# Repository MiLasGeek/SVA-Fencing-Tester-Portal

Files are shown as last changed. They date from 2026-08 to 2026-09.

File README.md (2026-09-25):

# SVA-Fencing-Tester-Portal 🤺

Willkommen im offiziellen Portal für den SVA-Fencing-Tester. Dieses Projekt wird als private Non-Profit-Initiative im Ehrenamt geführt, um Fechtvereine und Fechter mit einem zuverlässigen Werkzeug für die Wartung und Materialkontrolle zu unterstützen.

Der SVA-Fencing-Tester wird von Fechtern für Fechter ohne Gewinnabsicht entwickelt. Er soll den Sport durch erschwingliche Materialpflege attraktiver machen, bei Wartung und Turnierbetrieb Zeit sparen und nachvollziehbare, transparente Materialkontrollen unterstützen.

Die Bedienung wird bewusst einfach und möglichst intuitiv gestaltet, damit Ergebnisse eindeutig eingeordnet werden können und Interpretationsfehler vermieden werden. Das Gerät soll sowohl Einsteigern als auch erfahrenen Prüfern helfen; Nachwuchs nutzt es im Vereinsrahmen nach Einweisung und bei Bedarf begleitet.

Das Bedienkonzept folgt dem Prinzip **vom Ergebnis zum Detail**: Zuerst zeigt die Oberfläche klar OK oder NOK. Balken mit Grenzlinie und einstellbarem Warnbereich vermitteln anschließend, wie gut oder wie schlecht ein Messwert ist - mit einem Verlauf von Grün zu Gelb. Charts und Zahlenwerte ermöglichen die vertiefte Analyse; eine vollständige visuelle Anschluss- und Fehlermatrix macht Zusammenhänge auf einen Blick sichtbar. So reduziert die Oberfläche die geistige Belastung bei der Prüfung.

Für nachvollziehbare Materialprüfungen kann ein signiertes FIE-Preset verwendet werden. Die darin hinterlegten Grenzwerte sind im Gerät nur lesbar einsehbar; bei aktivem Preset kennzeichnet die Benutzeroberfläche den FIE-Modus deutlich. Das schafft Transparenz über die verwendeten Prüfparameter, ohne eine FIE-Zertifizierung oder formale Konformitätsaussage des Testers zu behaupten. Das Messprinzip und die Inhouse-Validierung sind in der [Messvalidierung](./docs/measurement_validation.md) dokumentiert.

⚠️ **AKTUELLER STATUS: Entwicklungs- und Evaluierungsphase**
Dieses öffentliche Portal veröffentlicht OTA-Updates, Handbücher, technische Hinweise und signierte Prüfparameter. Firmware und Webapp bleiben Closed Source; Quellcode und editierbare Elektronik-Layouts werden hier nicht veröffentlicht. Nicht CE-gekennzeichnete Einheiten sind keine allgemeinen Produkte und nicht für Verbraucher freigegeben.

---

## 📂 Portal-Übersicht

* 🤖 **[Firmware & OTA-Updates](./bin)** – Enthält die `version.json` für den automatischen Versionsabgleich über den Client-Browser sowie die offiziellen Update-Bundles.
* 🤺 **[FIE-Presets](./fie)** – Lesbare, signierte FIE-Prüfparameter mit aktuellem Manifest, Archiv und direktem Download für die Geräte-Webapp.
* 📑 **[FIE Material Rules (December 2025)](https://static.fie.org/uploads/38/190667-book%20m%20ang.pdf)** – Externe Regelwerksreferenz des aktuellen FIE-Presets; Erreichbarkeit und Aktualität liegen bei der FIE.
* 📐 **[Hardware & 3D-Druck](./hardware)** – STL- und STEP-Dateien für das frei druckbare Basis-Gehäuse und alle gängigen Verschleißteile.
* 📖 **[Online-Handbuch & Dokumentation](./docs)** – Das vollständige Online-Handbuch, ausführliche Reparaturanleitungen und die Material-Stückliste (BOM).
* ⚙️ **[Technische Spezifikationen](./FEATURES.md)** – Das vollständige, detaillierte Leistungsspektrum und alle Geräteeigenschaften im Überblick.
* ⏳ **[Entwicklungsgeschichte & Veröffentlichungsnachweis](./DEVELOPMENT_HISTORY.md)** – Die Chronologie der Hardware-Revisionen (Rev 1.0 bis Rev 4.0).
* 💻 **[Software-Architektur & Algorithmen](./SOFTWARE_ARCHITECTURE.md)** – Dokumentation der deterministischen Echtzeit-Schnittstellen und Lock-Free-Puffer.
* ⚖️ **[Rechtliches & Impressum](./IMPRINT.md)** – Gesetzliche Anbieterkennzeichnung nach § 5 DDG sowie Haftungsausschlüsse für Software und Hardware.
* 🛡️ **[Datenschutzerklärung](./PRIVACY.md)** – Transparente Informationen zur DSGVO-konformen Datenverarbeitung innerhalb dieses Repositories.
* 📋 **[Compliance-Status (Entwurf)](./docs/compliance/README.md)** – Vorläufige CE-, CRA- und FIE-bezogene Unterlagen; keine finale Konformitätsdokumentation.
* 📜 **[Lizenzliste (Third-Party)](./docs/compliance/THIRD_PARTY_LICENSES.md)** – Übersicht über die verwendeten Open-Source-Bibliotheken und Drittlizenzen.
* 💬 **[Community & Support](../../discussions)** – Unser virtuelles Vereinsheim. Nutze den Tab "Discussions" für Fragen, Erfahrungsaustausch und Best Practices.
* 🐛 **[Fehler melden](../../issues)** – Nutze den Tab "Issues" für strukturierte Bug-Reports zur Firmware, Webapp oder Hardware.

---

## 🚀 Highlights & Kernfeatures (Sperrveröffentlichung)

Der SVA-Fencing-Tester (Revision 4.0) bricht mit traditionellen Messgeräte-Konzepten und bietet Profiliga-Diagnose im ultrakompakten Eurokarten-Format ($100 \times 60$ mm):

* **860-Hz-Echtzeit-Abtastung:** Lückenlose Erkennung transienter Wackelkontakte im Millisekundenbereich zur präzisen Materialkontrolle.
* **Prädiktiver Matrix-Scan:** Graphentheoretische Transitivitäts-Reduktion überspringt redundante Kreuzprüfungen und schont ADC-Einschwingzeiten.
* **Asymmetrisches Fading:** Visueller Hold-Effekt „streckt“ flüchtige Fehler für das menschliche Auge (Sofort-Rot bei Defekt, weiches, einstellbares Fade-out).
* **Topologie-identische UI:** 1:1 grafische Buchsen-Projektion auf dem Display mit dynamischen Spline-Bögen zur sofortigen Entlarvung von Adernvertauschungen.
* **Echtes Zero-Power-Standby:** Automatische PMIC-Abschaltung bei Inaktivität. Knopflose Wiederzuschaltung rein über transienten Kondensator-Einschaltstrom.
* **Masse-Anker-Stabilisierung:** Das mechanische Plangepresste Akku-Platinen-Sandwich nutzt die Batteriezelle als thermische Kapazität zur ADC-Rauschminimierung.
* **Bulletproof-Recovery-Kaskade:** Ein im Core integrierter Notfall-HTML-Server und ein lokaler microSD-OTA-Pfad sichern das System gegen Datenkorruption im Feld ab.

👉 **Das vollständige, detaillierte Leistungsspektrum findest du in der [FEATURES.md](./FEATURES.md).**

---

## 🔒 Technisches Konzept & Sicherheit (Closed-Source)

Dieses Projekt ist auf Code-Ebene Closed-Source. Es werden keine Quellcodes oder editierbaren Elektronik-Layouts veröffentlicht. Zum Schutz vor Manipulationen, zum Erhalt der Turniertransparenz bei Waffenkontrollen und zur Abwehr von Reverse Engineering greift folgende Architektur:

* **Hybrid-Updates über Client-Brücke:** Die Geräte arbeiten im Messbetrieb komplett offline und strahlen einen eigenen WLAN-Access-Point aus. Der Abgleich erfolgt über den Browser des Endgeräts (Smartphone/PC), welcher die Update-Datei von GitHub lädt und lokal per Webapp auf den Tester überträgt. Alternativ ist ein Offline-Update via microSD-Karte möglich.
* **All-in-One Custom Bundle:** Updates werden als verschlüsseltes Kombi-Paket bereitgestellt, welches die Firmware, das LittleFS-Dateisystem (inkl. der komprimierten Webapp `webapp.gz`) und ein schlankes Geräte-Handbuch enthält.
* **Automatischer Failsafe (Recovery Mode):** Die Integrität des Filesystems wird beim Systemstart geprüft. Fehlt die `webapp.gz` im Flash oder ist sie beschädigt, lädt der ESP32 automatisch einen autarken, minimalistischen Notfall-Webserver. Die Weboberfläche zur Rettung ist im Fehlerfall direkt über **`http://192.168.4.1`** erreichbar.
* **Hardware-Sicherheit:** Für die Releasekonfiguration ist die hardwareseitige AES-Verschlüsselung des ESP32-S3 (Flash Encryption) vorgesehen. Sie schützt die Vertraulichkeit der Flash-Inhalte, ersetzt jedoch keinen hardwareseitig erzwungenen Secure Boot oder physischen Manipulationsschutz. Die genaue Grenze ist in der Compliance-Dokumentation beschrieben.

---

## 📖 Dokumentation (Hybrid-Konzept)

Um den begrenzten Flash-Speicher des ESP32 zu schonen, teilen wir die Dokumentation auf:
1. **Offline-Handbuch (Lite):** Direkt im LittleFS des Geräts gespeichert. Es ist extrem speicheroptimiert, verzichtet auf große Bilder und beschreibt nur die physischen Tasten, LEDs und die Display-Menüs.
2. **Online-Handbuch (Full):** Hier im Repository unter `/docs/manuals`. Nur hier findest du die vollständige Anleitung inklusive hochauflösender Screenshots der Webapp und Erklärungen zu den Browser-Statistiken.

---

## 🛠️ Bezug von Hardware & Ersatzteilen (Non-Profit)

Es gibt keinen kommerziellen Webshop und keine allgemeine Geräteabgabe. Nicht CE-gekennzeichnete Einheiten werden ausschließlich als kundenspezifische Evaluierungskits an benannte Vereine mit sachkundiger Projektleitung abgegeben. Der Verein übernimmt die Endmontage einschließlich der eigenständigen Beschaffung und des Anschlusses eines geeigneten Akkus über den vorgesehenen Steckverbinder und verwendet das Kit ausschließlich in einer dokumentierten Forschungs- und Entwicklungsumgebung.

Das Projekt kann eine technische Akkuempfehlung bereitstellen. Der Akku wird nicht als Bestandteil des Evaluierungskits geliefert. Das vermeidet Gefahrgutversand und hilft, die Bereitstellungs- und Beschaffungskosten für Vereine niedrig zu halten. Er darf nur unbeschädigt, ohne Gewalt und gemäß der Kit-Anleitung angeschlossen werden. Die Endmontage durch den Verein ändert für sich allein weder die rechtliche Einordnung des Kits noch ersetzt sie die später erforderliche Konformitätsbewertung.

Die Übergabe der Evaluierungskits erfolgt in der Regel persönlich. Dadurch entfällt Versandverpackung; die Anforderungen für eine spätere allgemeine Marktbereitstellung bleiben davon unberührt. Bei Rückgaben ist Versand nicht ausgeschlossen, wird aber vorab abgestimmt.

Für die Rücknahme eines Evaluierungskits bitte vorab Kontakt aufnehmen. Der abgestimmte Rückgabeweg und eine Vorlage für die erforderlichen Angaben stehen unter [Rücknahme eines Evaluierungskits](./docs/return_request_template.md) bereit.

Private Fechter erhalten keine Einheit direkt, sondern nur über ihren Verein im Rahmen dieses Projektvorhabens. Eine andere Bereitstellung wird erst nach Abschluss der erforderlichen Laborprüfungen und der Konformitätsbewertung geprüft.

Ein Erwerb oder eine Kostenerstattung für ein Evaluierungskit wird ebenso individuell mit dem Verein abgestimmt; es gibt keinen offenen Shop und keine anonyme Direktbestellung. Dieser kleine, dokumentierte Rahmen erleichtert Übergabe, Rücknahme und Nachverfolgbarkeit. Er ersetzt jedoch nicht die rechtliche Prüfung, falls eine Überlassung als Marktbereitstellung einzuordnen ist.

Die technische Vorbereitung für die Laborprüfung ist abgeschlossen. Bei der kleinen Stückzahl liegen die Kosten voraussichtlich etwa beim Vier- bis Fünffachen der Kosten von zehn Geräten. Spenden und Fördermittel werden vorrangig für die EMV- und Funkprüfungen durch ein geeignetes Labor eingesetzt.

Eine CE-Erklärung wird erst nach abgeschlossener, dokumentierter Konformitätsbewertung unterzeichnet. Vor einer allgemeinen Marktbereitstellung werden außerdem die jeweils anwendbaren Pflichten für Elektrogeräte, Batterien und Verpackungen - einschließlich Kennzeichnung, Registrierung, Rücknahme und Entsorgung - geprüft und erfüllt.

Für eine einzelne B2B-Registrierung fallen nach der veröffentlichten Gebührenübersicht der stiftung ear derzeit beispielhaft rund 28,40 EUR netto einmalig sowie rund 131,20 EUR netto jährlich an, zuzüglich möglicher Entsorgungskosten. Bei einer Weitergabe von etwa zwanzig Geräten ist das ein erheblicher Fixkostenanteil. Die begrenzte Evaluierungsphase ermöglicht Vereinen daher einen preiswerten, dokumentierten Testeinsatz. Sie ist jedoch keine Zusage, dass keine Markt-, CE-, Entsorgungs- oder sonstigen Rechtsrisiken bestehen; jede Überlassung wird einzeln dokumentiert und rechtlich eingeordnet.

Diese Abgrenzung dient nicht dazu, gesetzliche Pflichten zu umgehen. Sobald eine Überlassung als Marktbereitstellung einzuordnen ist, werden die erforderlichen Pflichten unabhängig von Stückzahl oder Kostendeckung erfüllt. Bei einer einmaligen Kleinserie wären die laufenden Registrierungs- und Organisationskosten jedoch ein erheblicher privater Zuschuss, weil Vereine die Geräte nur zum Selbstkostenpreis erhalten. Die Evaluierungsphase schafft deshalb einen nachvollziehbaren Weg, den tatsächlichen Bedarf und die technische Reife zunächst begrenzt zu prüfen.

Eine geringe Zahl dokumentierter Einheiten im Feld ist für diese Evaluierung sinnvoll; eine Ausweitung in kleinen Einzelschritten wäre es nicht. Steigt die Nachfrage über diesen Rahmen hinaus, soll ein geeigneter Hersteller die professionelle beziehungsweise maschinelle Fertigung, die abgeschlossene Konformitätsbewertung und die vollständige Marktfreigabe übernehmen. Voraussetzung ist ein Preis, der den Vereinen und der ehrenamtlichen Entwicklung weiterhin gerecht wird.

👉 **[Evaluierungskit-Anfrage für einen Verein erstellen](../../issues/new?template=anfrage_premium.md)**

---

## 🧾 Steuerlicher Hinweis & Abrechnung

* **Aktueller Rahmen:** Das Projekt wird von einer einzelnen Privatperson in der Freizeit betrieben; eine Gewinnabsicht besteht nicht. Solange keine andere Organisationsform oder gewerbliche Tätigkeit besteht, werden keine gesonderten Umsatzsteuerbeträge ausgewiesen.
* **Brutto-Selbstkosten:** Elektronische Bauteile werden über offizielle Distributoren wie Mouser und Aisler bezogen. Eine etwaige Weitergabe erfolgt zu den tatsächlich angefallenen Brutto-Materialkosten, ohne Gewinnaufschlag und nur im Rahmen der zeitlich möglichen Handbestückung.
* **Vereinsbuchhaltung:** Vereine erhalten einen privaten Kaufbeleg (Quittung über Aufwandsersatz/Materialkosten) für ihre Unterlagen. Kopien der originalen Distributor-Rechnungen können zur absoluten Transparenz beigelegt werden. 
* **Fertigung nach Verfügbarkeit:** Bestückung, Kalibrierung und Endtests erfolgen in der Freizeit und nur in kleinen Stückzahlen. Sollte sich die Organisations- oder Fertigungsform ändern, werden die rechtlichen, steuerlichen und vertraglichen Angaben vor einer Bereitstellung entsprechend überprüft und angepasst.

---

## 📄 Lizenz & Rechtliches

Die Firmware ist urheberrechtlich geschützt (Binary-only). Für die 3D-Druckdaten im Ordner `/hardware` gilt die **Creative Commons Namensnennung - Nicht-kommerziell - Weitergabe unter gleichen Bedingungen 4.0 International (CC BY-NC-SA 4.0)**. Eine gewerbliche Nutzung oder der kommerzielle Weiterverkauf der Gehäuseteile ist strikt untersagt. Siehe `LICENSE`-Datei für Details.

Informationen zum Anbieter sowie zum Datenschutz findest du in unserem separaten [Impressum](./IMPRINT.md) und der [Datenschutzerklärung](./PRIVACY.md).

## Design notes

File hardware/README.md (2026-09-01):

# Hardware-Übersicht

Dieser Bereich enthält ausgewählte, nicht-editierbare Visualisierungen der Hardware-Revisionen des SVA-Fencing-Testers. Schaltpläne, PCB-Quelldaten und Fertigungsdaten sind nicht Bestandteil dieses öffentlichen Portals.

## PCB-Renderings

- [Revision 2](./pcb/rev2/)
- [Revision 4](./pcb/rev4/)

## 3D-Modelle für Gehäuse-CAD

Die KiCad-exportierten STEP-Modelle enthalten die bestückten PCB-Baugruppen und dienen als räumliche Grundlage für Gehäusekonstruktionen:

- [Revision 2](./models/sva-fencing-tester-rev2.step)
- [Revision 4](./models/sva-fencing-tester-rev4.step)

Die Abbildungen dienen ausschließlich zur Identifikation und Dokumentation der jeweiligen Hardware-Revision. Sie sind keine Fertigungsunterlagen.

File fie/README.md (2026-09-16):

# FIE preset archive

This directory publishes readable, signed FIE test-parameter presets for the SVA-Fencing-Tester.

## Current preset

The current package is identified by [`latest.json`](./latest.json). It references the signed file in [`stable/`](./stable/) and includes its SHA-256 checksum for the browser download flow.

- Preset version: `1`
- Preset date: `2026-08-18`
- Rule reference: FIE Material Rules, `December 2025`
- Source: [FIE Material Rules PDF](https://static.fie.org/uploads/38/190667-book%20m%20ang.pdf)

## Use and verification

The device webapp can download the current preset through the user's browser, or the JSON file can be downloaded here and imported manually. In both cases, the ESP verifies the schema, values, key ID and ECDSA P-256/SHA-256 signature itself before it stores or activates a preset.

The manifest checksum is an additional transport check only. A modified portal file, manifest or browser response cannot activate a changed preset without a valid device-trusted signature.

The source URL is the signed reference snapshot for this particular preset; it is not a promise that the linked FIE document remains reachable or the newest publication. The external FIE website is outside this project's control. A changed FIE source, rule edition or URL requires a new dated, versioned and signed preset. Published preset files are never edited retroactively. Devices continue to show and use their imported preset until the user explicitly loads or imports a newer one.

## Publication rule

Each new release keeps its dated signed JSON package in `stable/` and updates `latest.json` only after the package, its SHA-256 value, FIE source document and source month/year have been reviewed together. The source version uses the exact form `Month YYYY`, for example `December 2025`.

This preset identifies a selected test-parameter profile. It is not an official FIE logo, certification, or a certification of a test result or device.

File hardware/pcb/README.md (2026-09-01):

# PCB-Visualisierungen

Dieser Bereich enthält nicht-editierbare Renderings und Grafiken der Leiterplatten (PCBs) des SVA-Fencing-Testers. Diese Abbildungen dienen ausschließlich zur Identifikation, Dokumentation und visuellen Überprüfung der jeweiligen Hardware-Revision. 

Schaltpläne, Layout-Quelldaten (z. B. KiCad-Dateien) und Gerber-Fertigungsdaten sind nicht Bestandteil dieses Verzeichnisses.

## PCB-Revisionen

- [Revision 2](./rev2/) – Enthält Darstellungen des stabilen Revision-2-Formfaktors (Platinen-Unterseite und Display).
- [Revision 4](./rev4/) – Enthält Darstellungen der aktuellen Revision-4-Hardware (Platinen-Unterseite und Display).

## Inhalt der Unterverzeichnisse

Jeder Revisions-Ordner stellt folgende Standard-Visualisierungen bereit:
* **Platinen-Layout (`*-bottom.png`)**: Ansicht der Leiterbahnen und kritischen Bauteilplatzierungen auf der Unterseite.
* **Display-Layout (`*-display.png`)**: Visuelle Referenz für die Ausrichtung und Integration der Display-Komponente.

Die bereitgestellten Grafiken sind keine Fertigungsunterlagen.

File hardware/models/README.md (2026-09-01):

# STEP-Modelle für Gehäuse-CAD

| Hardware-Revision | STEP-Modell |
| --- | --- |
| Rev 2 | [sva-fencing-tester-rev2.step](./sva-fencing-tester-rev2.step) |
| Rev 4 | [sva-fencing-tester-rev4.step](./sva-fencing-tester-rev4.step) |

Die Modelle stammen aus KiCad-STEP-Exports der bestückten PCB-Baugruppen und sind als räumliche Grundlage für Gehäuse-CAD vorgesehen. Sie sind keine Schaltplan-, PCB-Quell- oder Fertigungsdaten.

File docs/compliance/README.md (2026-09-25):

# 📜 Regulatory Compliance, Specifications & Impressum (Rev 2 & Rev 4) — Draft

> **Status: Entwurf / nicht finale Konformitätsdokumentation.** Dieses Dokument beschreibt den derzeitigen Planungs- und Entwicklungsstand. Es ist **keine** unterschriebene EU-Konformitätserklärung, kein CE-Nachweis, kein CRA-Konformitätsnachweis und kein FIE-Zertifikat. Finale, datierte und gegebenenfalls unterzeichnete Unterlagen werden nach Abschluss der technischen Prüfung und Freigabe veröffentlicht.

The SVA-Fencing-Tester (supporting hardware revisions 2 and 4 via automatic firmware detection) is intended to be used exclusively as a specialized workshop diagnostic and maintenance tool for fencing gear. It is not intended as a tournament signaling apparatus (Melder). The final regulatory classification and the scope of any required assessment will be confirmed before product release.

---

## 🤺 1. FIE Reference & Specifications — Draft
The intended use is a dedicated workshop test bench for fencing equipment. It is not a tournament scoring apparatus (Melder) and does not display or control competition hits. The project aims to document conformity of the tested fencing material with the applicable FIE material requirements. A separate FIE certification of the tester itself is not intended for this diagnostic use; the final scope will be documented before product release.

* **Signal Evaluation:** Designed to test and analyze weapon assemblies, body cords, and reels against the applicable electrical tolerance windows in the FIE Technical Rules.
* **Microsecond Analytics:** The firmware loop records transient resistance changes in the microsecond range to visually isolate mechanical contact bouncing (Prellen) before it triggers a lockout on an official piste scoring box.
* **Pure Diagnostic Scope:** The unit does not actively interfere with tournament scoring loops. It serves solely as a diagnostic aid for material inspection before use.

---

## 🇪🇺 2. CE / RED / RoHS — Planning Status
The following points define the intended compliance scope for the final device. They do not constitute a declaration that either revision already satisfies the listed directives:
* **Radio Equipment Directive (RED - 2014/53/EU):** Planned assessment of the local 2.4 GHz Wi-Fi function and transmission parameters.
* **EMC Directive (2014/30/EU):** Planned assessment of electromagnetic compatibility based on the finalized hardware design.
* **RoHS Directive (2011/65/EU):** Component and supplier documentation will be collected for the final bill of materials.

### Evaluation phase

Until the final conformity assessment is complete, non-CE-marked units are supplied only as custom-built evaluation kits to named fencing clubs with a qualified project lead. The club independently procures and connects a suitable battery through the specified connector as part of final assembly, and uses the kit solely in a documented research and development environment. The project may provide a technical battery recommendation, but the battery is not part of the evaluation kit. Battery connection must follow the kit instructions and is not, by itself, a substitute for the required conformity assessment. Private fencers do not receive units directly; any involvement is exclusively through their club within that documented project. This is not a general market release or a regular club operation.

The technical preparation for laboratory testing is complete. Because of the small quantity, laboratory costs are expected to be approximately four to five times the cost of ten devices. Donations and grants are therefore reserved primarily for the required EMC and radio testing.

### Market release gate

No CE declaration will be signed and no CE marking will be affixed before the final device has a documented conformity assessment. For this project, a suitable EMC and radio laboratory report is a required release record. The report, technical documentation, risk assessment, instructions, manufacturer identification, and EU declaration of conformity must be complete and internally approved before any general market release.

Before market release in Germany, the project must also determine and complete all applicable producer obligations for electrical equipment, batteries and packaging, including registration, marking, take-back and disposal information. Final assembly by a club or separate procurement of a recommended battery does not by itself remove these obligations. The evaluation-kit boundary remains subject to documented case-by-case legal review.

For perspective, the published stiftung ear B2B example for one registration currently shows approximately EUR 28.40 net one-off and EUR 131.20 net per year, before any actual disposal costs. For a small run of around twenty devices, this is a material fixed-cost share. The limited evaluation phase is intended to let clubs test the equipment affordably while evidence is gathered for the final release. It does not guarantee exemption from market, CE, disposal, competition or other legal requirements; each supply must remain documented and be assessed for its specific circumstances.

This boundary is not intended to avoid statutory duties. If a supply is classified as making the product available on the market, the applicable duties will be fulfilled regardless of quantity or cost recovery. For a one-off small run, however, recurring registration and administration costs would be a material private subsidy because clubs receive units only at cost. The evaluation phase therefore provides a documented way to establish actual demand and technical maturity before a general release is considered.

A small number of documented units in the field is appropriate for that evaluation; gradual expansion through additional small runs is not. If demand exceeds this limited scope, an appropriate manufacturer should take over professional or automated manufacture, completed conformity assessment and the full market-release process. This is conditional on a price that remains appropriate for clubs and respects the voluntary nature of the project's development.

---

## 🔒 3. EU Cyber Resilience Act (CRA) — Preliminary Security Concept
The SVA-Fencing-Tester (Rev 2 / Rev 4) is being developed according to "Security by Design" principles. The following describes the intended architecture and must be validated against the final hardware, firmware, update process and applicable CRA requirements:

* **Zero Personal Data (GDPR Free):** The system does not collect, process, or store any personal user data or fencing club metrics.
* **Credential Hardening:** Local Wi-Fi credentials and security tokens are securely hashed/encrypted within the non-volatile storage and cannot be extracted via the user interface or wireless dumps.
* **Secure Configuration Backup:** Parameter and JSON configuration files are encrypted during export. While the local import logic accepts standard schemas for club flexibility, unencrypted exploitation from the outside is blocked.
* **Minimized Attack Surface (No OS / No FTP):** The device does not run a generic operating system (No OS overhead). High-risk legacy protocols like FTP, Telnet, or SSH are completely omitted.
* **No Internet Routing:** The device operates exclusively as a local, air-gapped server. It features no network forwarding, no internet gateway routing, and cannot connect to external cloud services.
* **Hardened Server & Binary Streams:** The local network architecture consists solely of a locked-down, proprietary server utilizing a minimalist REST API and an isolated, purely binary measurement data stream for real-time hit telemetry.
* **Strict Upload Restriction:** Outside of the authenticated OTA firmware update pipeline and the local configuration JSON import, no files can be uploaded or written to the internal LittleFS partition.
* **Physical Service Boundary:** Secure Boot is not enabled. Flash encryption and the custom OTA format protect the confidentiality of release contents and the regular update paths, but they do not prevent physical reprogramming. Reprogramming requires opening the device, the custom programming adapter and an independently developed firmware for the custom hardware; a device modified in this way is outside the released and supported configuration.

---

## 📦 Proprietary Encrypted OTA Bundle Format (SVA-Container)

To protect release contents and maintain a controlled update workflow, the SVA-Fencing-Tester uses an encrypted, proprietary bundle format (`.ota`).

Unencrypted firmware binaries (`.bin`) or raw file system images are never distributed publicly and will be automatically rejected by the device's bootloader.

### 🛡️ Core Security Layers of the `.ota` Container:

1. **Cryptographic Encapsulation (Container Encryption):**
   The firmware payload and LittleFS system assets (webapp and lite manual) are packed into a proprietary container using a private cryptographic routine prior to deployment on the `main` branch. The intended protection against extraction or unauthorised modification depends on the implemented cryptography, key management and final release configuration.
2. **Integrity & Origin Validation:**
   Before executing any flash sequence, the device validates the structure, header signatures, and checksums of the custom bundle. Modified, corrupted, or third-party tampered files are rejected by the main updater and recovery server.
3. **Intellectual Property Protection:**
   This closed distribution workflow is intended to protect the integrity of released update bundles and the project's proprietary implementation.

---

*Note for the Testing Phase: The files deployed to the public `main` branch during the current 'Under Construction' phase contain purely non-functional dummy datasets to validate the download, storage routing, and parsing logic of the device webapp.*

---

## 📜 Impressum & Anbieterkennzeichnung (Legal Notice)

Dieses Portal ist eine private, ehrenamtliche Non-Profit-Initiative zur Unterstützung des Fechtsports.

Die Anbieterkennzeichnung und Kontaktangaben sind im zentralen [Impressum](../../IMPRINT.md) als Grafik hinterlegt.

*For official compliance inquiries or full hardware verification requests, please refer to the contact details provided in the integrated 'About' page of the official device webapp.*

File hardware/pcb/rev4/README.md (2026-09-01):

# PCB – Revision 4

| Ansicht | Datei |
| --- | --- |
| Bestückungsseite | [pcb-rev4-bottom.png](./pcb-rev4-bottom.png) |
| Display-/Frontansicht | [pcb-rev4-display.png](./pcb-rev4-display.png) |

Die Renderings zeigen Revision 4 zur visuellen Identifikation. Sie enthalten keine editierbaren PCB-, Schaltplan- oder Fertigungsdaten.

Das vollständige 3D-Modell für Gehäuse-CAD ist unter [sva-fencing-tester-rev4.step](../../models/sva-fencing-tester-rev4.step) verfügbar.

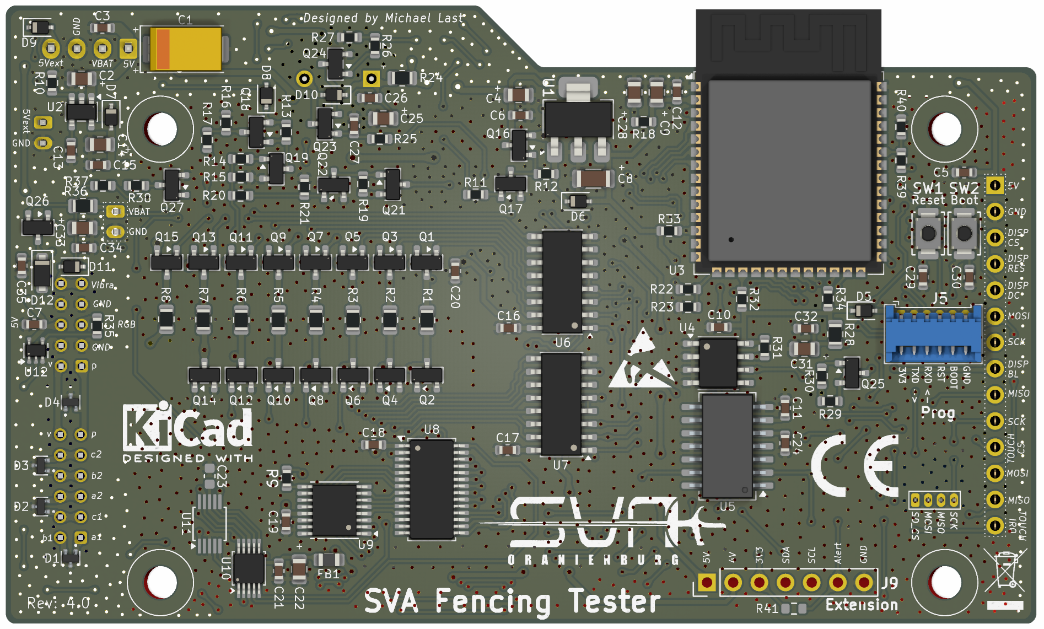
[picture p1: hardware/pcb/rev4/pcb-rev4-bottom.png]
Bestückungsseite Rev 4


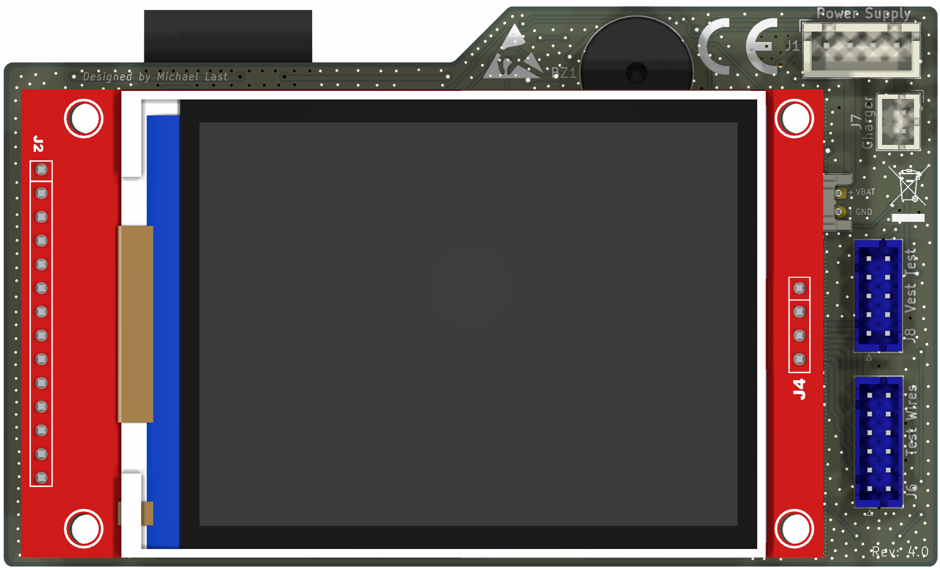
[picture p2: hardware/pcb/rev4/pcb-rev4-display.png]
Display-/Frontansicht Rev 4


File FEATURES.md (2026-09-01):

# ⚡ Feature-Übersicht & Leistungsspektrum (Features & Specifications)

Der SVA-Fencing-Tester (Revision 4.0) ist ein ultrakompaktes, proprietäres Prüf- und Diagnosegerät für den Fechtsport. Die Firmware wird als Closed-Source-Binary bereitgestellt. Es kombiniert multimodale Echtzeit-Messtechnik mit intuitiver visueller Analyse und industrieller Ausfallsicherheit.

---

### 🔬 Messtechnik & Diagnose-Performance
* **860-Hz-Echtzeit-Sampling:** Ultra-hochfrequente Abtastung zur lückenlosen Erfassung transienter Wackelkontakte im Millisekundenbereich.
* **Dualer Messbereich (0,01 Ω bis 10 MΩ):** Hochpräzise Durchgangsprüfung ($< 10\,\Omega$ mit $0,01\,\Omega$ Auflösung) und hochohmige Isolationsüberwachung ($> 500\,\text{k}\Omega$) in einer einzigen Matrix.
* **Prädiktiver Matrix-Scan:** Graphentheoretische Transitivitäts-Reduktion zur drastischen Verkürzung der physischen Abfragezyklen der N-zu-N-Kreuzmatrix.
* **Sub-Matrix-Paarprüfung:** Gezielte Fokussierung der vollen ADC-Abtastrate auf ein einzelnes Adernpaar (z. B. A1-A2) zur dedizierten, hochauflösenden Fehlersuche.
* **Flankengesteuerte Trigger-Engine:** Speicheroszilloskop-Modus für Waffenspitzen (Öffner/Schließer) mit frei einstellbarem Pre- und Post-Trigger-Verhältnis ($X\,\%$) im Live-Chart.

---

### 🎨 Visuelle UI/UX & Bedienkomfort
* **Asymmetrisches Fading (Fehler-Verstärker):** Visuelle Hold-Streckung für Mikrosekunden-Fehler (sofortiges hartes Rot bei Defekt, weiches Fade-out nach Stabilisierung). Abklingzeit einstellbar (*Off / Fast / Medium / Slow*).
* **Topologie-identische Netz-Matrix:** 1:1 grafisches Abbild der physischen Buchsen auf dem Display. Kurzschlüsse und Adernvertauschungen werden als dynamische, farbcodierte Spline-Bögen direkt visualisiert.
* **Duale Skalierungs-Balken mit Peak-Hold:** Lineare Anzeige für Durchgang ($0-10\,\Omega$) und logarithmische, invers gefüllte Darstellung für Isolation ($500\,\text{k}\Omega-10\,\text{M}\Omega$) inklusive dauerhafter Schlechtwert-Markierung.
* **Flow-Free Gestensteuerung:** Intuitive Navigation in einer horizontalen UI-Landschaft via Wischen, Touch-Bereichen und Long-Clicks – optimiert für die Bedienung in der Halle.
* **FIE-Preset-Transparenz:** Permanente Visualisierung des aktiven Regelwerks im Display. Manipulationssicherer Sabotageschutz (Read-Only Firmware-Lock) auf Geräteebene.

---

### 🔌 Konnektivität & Flottenmanagement
* **Dual-WiFi-Modus (AP & Client):** Autarker Access Point für die Planche und Client-Mode zur komfortablen Einbindung ins Vereins-Netzwerk.
* **Dynamische QR-Code-Kopplung:** Knopflose Verbindung per Scan direkt im Display (WiFi-AP-Connect, Webapp-Redirect via mDNS, Direktlink zum Public GitHub-Repo).
* **JSON-Parameter-Klonen:** Vollständiger Export und Import aller Einstellungen zur sekundenschnellen Flottenprovisionierung. Granulare Auswahl der Datenklassen via Checkbox-Filter beim Import.
* **Asymmetrische Credential-Sicherheit:** Verschlüsselte WiFi-Zugangsdaten im JSON-Export bei gleichzeitiger Akzeptanz von Klartext-Profilen zur Erstkonfiguration am PC.
* **Zentralisiertes Webapp-Update:** Passwortgeschütztes Over-the-Air-Update (OTA) für künftige FIE-Regelanpassungen direkt über den Browser.

---

### 🛡️ Hardware-Härtung, Power & Ausfallsicherheit
* **Echtes Zero-Power-Standby (0 Watt):** Automatische Abschaltung der 5V-Hauptschiene bei Inaktivität via Last-Unterschreitung des PMICs. Knopfloses Aufwecken rein über transienten Kondensator-Einschaltstrom (Inrush Current) durch kurzes Betätigen des Netzschalters ($< 1\,\text{s}$).
* **Peripherie-Trennung via LDO-Enable:** Vollständige physische und spannungslose Trennung der analogen +4V-Messstrecke im Deep-Sleep zur Eliminierung von Kriechströmen und Verhinderung von Akku-Restentladung.
* **Wartungsfreie RTC-Zeithaltung:** Direktes Akku-Backup der Echtzeituhr im Nanoampere-Bereich (weit unter der LiPo-Selbstentladung). Keine separate Knopfzelle nötig.
* **Temperaturkompensierte Batterie-Überwachung:** Silizium-Diode mit Gegenlauf-Kennlinie gleicht thermische Effekte des LiPos im Feld autark aus. Inhärente Fail-Safe-Sicherung gegen Überspannung bei Pfad-Unterbrechung.
* **Thermodynamisches Sandwich-Design:** Plangepresster 1800-mAh-LiPo-Akku wirkt als massive thermische Kapazität, dämpft Umgebungsschwankungen auf der Platine und eliminiert ADC-Rauschen. Schonende Laderate ($400\,\text{mA} \approx 0,22\,\text{C}$) schützt das TFT-Display vor Hitze.
* **Bulletproof Recovery-Kaskade:** Bei korruptem Filesystem startet die Firmware automatisch einen integrierten HTML-Notfall-Webserver zur Systemrettung im Browser. Zusätzlicher, autarker Offline-Flashpfad über integrierten SD-Kartenslot ($J4$).
* **Designed for Manufacturing & Repair:** Kompakte Eurokarten-Geometrie ($100 \times 60\,\text{mm}$) passend für Standard-Aluminium-Strangpressprofile ohne Platinenüberhang (keine Kollision mit tiefen 4-mm Frontbuchsen). Striktes Einseiten-SMD-Layout (Bottom) für kostengünstigen Single-Reflow-Nutzen inklusive Stencil-Schablone, vollständig handlötbar (Zero BGA/QFN) und mechanisch entkoppelte Anschlussbuchsen.

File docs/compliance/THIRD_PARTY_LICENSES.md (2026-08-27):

# Third-Party Components and Licenses

The primary firmware and custom web application of the SVA-Fencing-Tester are proprietary and closed-source. 

However, this project utilizes a variety of third-party open-source components, libraries, and frameworks within its compilation and build environments. The inventory below reflects the active components and their respective licenses.

## Core Firmware / Toolchain

| Component | Source / Package | License |
| --- | --- | --- |
| PlatformIO `espressif32` platform via pioarduino | `platform = https://github.com...` | Apache-2.0 |
| Arduino-ESP32 framework | `framework-arduinoespressif32` | LGPL-2.1-or-later |
| Arduino-ESP32 framework libraries | `framework-arduinoespressif32-libs` | LGPL-2.1-or-later |
| mklittlefs tool | `tool-mklittlefs` | MIT |

## PlatformIO Libraries

| Component | Version | License |
| --- | --- | --- |
| PsychicHttp | 2.1.1 | MIT |
| TaskScheduler | 3.8.5 | BSD-2-Clause |
| ArduinoJson | 7.4.3 | MIT |
| ADS1115_WE | 1.5.5 | MIT |
| ESP32Time | 2.0.6 | MIT |
| CRC | 1.0.4 | MIT |
| DS3232 | 0.6.1 | MIT |
| I2C_EEPROM | 1.9.4 | MIT |
| htcw_rmt_led_strip | 0.2.2 | MIT |
| Sqlite Micro Logger | 1.2.0 | Apache-2.0 |
| UrlEncode | transitive | MIT |

## Local / Vendored Libraries

| Component | Location | License |
| --- | --- | --- |
| XPT2046_Touchscreen_TT | `lib/XPT2046_Touchscreen_TT` | MIT; the remaining source files `XPT2046_Touchscreen_TT.h/.cpp` carry the MIT permission notice from the Paul Stoffregen-based upstream |

## Webapp Runtime Dependencies

| Component | Version | License |
| --- | --- | --- |
| Vue | 3.5.30 | MIT |
| Vue Router | 5.0.4 | MIT |
| Vue I18n | 11.3.0 | MIT |
| Bootstrap | 5.3.7 | MIT |
| bootstrap-icons-vue | 1.11.3 | MIT |
| @popperjs/core | 2.11.8 | MIT |
| mitt | 3.0.1 | MIT |
| sortablejs | 1.15.7 | MIT |
| spark-md5 | 3.0.2 | MIT or WTFPL |
| pulltorefreshjs | 0.1.22 | MIT |
| uPlot | 1.6.32 | MIT |
| uplot-vue | 1.2.4 | MIT |
| sass-embedded | 1.98.0 | MIT |
| @intlify/message-resolver | 9.1.10 | MIT |

## Webapp Build / Development Dependencies

| Component | Version | License |
| --- | --- | --- |
| @eslint/js | 10.0.1 | MIT |
| @intlify/unplugin-vue-i18n | 11.0.7 | MIT |
| @tsconfig/node22 | 22.0.2 | MIT |
| @types/bootstrap | 5.2.10 | MIT |
| @types/node | 25.5.0 | MIT |
| @types/pulltorefreshjs | 0.1.7 | MIT |
| @types/sortablejs | 1.15.8 | MIT |
| @types/spark-md5 | 3.0.5 | MIT |
| @vitejs/plugin-vue | 6.0.5 | MIT |
| @vue/eslint-config-typescript | 14.7.0 | MIT |
| @vue/tsconfig | 0.9.1 | MIT |
| eslint | 10.1.0 | MIT |
| eslint-plugin-vue | 10.8.0 | MIT |
| globals | 17.4.0 | MIT |
| npm-run-all | 4.1.5 | MIT |
| prettier | 3.8.1 | MIT |
| sass | 1.98.0 | MIT |
| sass-loader | 16.0.7 | MIT |
| TypeScript | 5.9 | Apache-2.0 |
| Terser | 5.46.1 | BSD-2-Clause |
| Knip | 6.0.4 | ISC |
| Vite | 8.0.2 | MIT |
| vite-plugin-compression | 0.5.1 | MIT |
| vite-plugin-css-injected-by-js | 4.0.1 | MIT |
| vue-eslint-parser | 10.x | MIT |
| vue-tsc | 3.2.6 | MIT |

## Notes

- This inventory is based on the package metadata and license files present in the current local project environment.
- The web dependency sections reflect the direct production and development dependencies declared in `webapp/package.json`.
- Transitive dependencies may introduce additional notices or obligations.
- The proprietary license of the primary SVA-Fencing-Tester firmware does not affect or alter the original open-source licenses governing these third-party tools and components.

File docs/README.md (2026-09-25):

# Dokumentation

Diese Übersicht führt zu den öffentlich verfügbaren Anleitungen und Hintergrundinformationen für den SVA-Fencing-Tester.

> **Hinweis zum Projektstatus:** Solange das Portal als „Under Construction“ gekennzeichnet ist, sind alle Inhalte als Entwicklungs- und Testdokumentation zu verstehen.

## Anleitungen

- [Firmware & OTA-Updates](../bin/README.md) – Update über die lokale Geräte-Webapp, Downgrade und Recovery-Verweis.
- [SD-OTA-Recovery](./manuals/sd_ota_recovery.md) – Wiederherstellung bzw. Offline-Update per SD-Karte.
- [Versionskonvention](./manuals/version_convention.md) – Aufbau und Einordnung der Firmware-Versionen.

## Wartung und Hardware

- [Stückliste & Service-Konzept](./bom.md) – Überblick über Komponenten und austauschbare Teile.
- [Messvalidierung und Genauigkeit](./measurement_validation.md) – Messprinzip, Inhouse-Validierung und FIE-Modus.
- [Reparaturleitfaden](./repair/material_failures.md) – Hinweise zu häufigen Materialfehlern an Fechtausrüstung.
- [Hardware-Übersicht](../hardware/README.md) – PCB-Renderings und STEP-Modelle der Hardware-Revisionen.

## Rechtliches und Nachweise

- [Compliance-Status (Entwurf)](./compliance/README.md) – Vorläufiger CE-, CRA- und FIE-bezogener Status.
- [Third-Party-Lizenzen](./compliance/THIRD_PARTY_LICENSES.md) – Versionsgebundener Nachweis der verwendeten Komponenten.
- [Vorlage für Kostenbeleg](./receipt_template.md) – Dokumentationsvorlage für privaten Aufwandsersatz.
- [Rücknahme eines Evaluierungskits](./return_request_template.md) – Vorlage und Ablauf für die abgestimmte Rückgabe.

## Hilfe und Rückmeldung

Fragen, Fehlerberichte und Vorschläge können über die [Issue-Vorlagen](../.github/ISSUE_TEMPLATE/README.md) eingereicht werden.

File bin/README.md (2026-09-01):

# Firmware & OTA-Updates

Dieser Ordner enthält die OTA-Bundles für den SVA-Fencing-Tester sowie die Datei `version.json` für den Versionsabgleich in der Geräte-Webapp.

> **Entwicklungsstatus:** Solange das Portal als „Under Construction“ gekennzeichnet ist, sind bereitgestellte Dateien ausschließlich für Tests vorgesehen. Installiere nur ausdrücklich freigegebene Bundles auf einem Gerät.

## Update-Prinzip

Der Tester benötigt selbst keinen Internetzugang. Er stellt für die lokale Geräte-Webapp ein eigenes WLAN bereit. Ein Smartphone oder PC übernimmt die Internetverbindung, lädt das OTA-Bundle aus diesem Portal herunter und überträgt die Datei anschließend lokal über die Webapp an das Gerät.

## Update durchführen

1. Stelle sicher, dass der Akku ausreichend geladen ist und unterbrich die Stromversorgung während des Updates nicht.
2. Verbinde Smartphone oder PC mit dem WLAN des Testers und öffne die lokale Geräte-Webapp.
3. Öffne dort den Update-Bereich und wähle **Neueste Version laden**. Die Webapp lädt das vollständige Bundle über die Internetverbindung des Clients, verifiziert dessen SHA-256-Prüfsumme und bietet es anschließend zur lokalen Übertragung an.
4. Prüfe Version und Hinweise und starte die Übertragung auf den Tester. Das Gerät selbst benötigt dabei keinen Internetzugang.
5. Alternativ kann eine bereits gespeicherte `.ota`-Datei über die Dateiauswahl hochgeladen werden. Das ist auch der Weg für ein gezieltes Downgrade.
6. Warte, bis die Webapp den erfolgreichen Abschluss meldet. Das Gerät startet danach gegebenenfalls neu.
7. Prüfe nach dem Neustart im Info-Bereich die installierte Version.

## Downgrade

Ältere, kompatible Bundles bleiben in [`stable/`](./stable/) verfügbar. Für ein Downgrade wird derselbe Ablauf verwendet. Installiere nur vollständige, ausdrücklich freigegebene OTA-Bundles.

## `version.json` für die direkte Aktualisierung

Die Geräte-Webapp liest die aktuelle Freigabe aus `version.json`. Damit der Button **Neueste Version laden** aktiv genutzt werden kann, benötigt `latest_release` zusätzlich zu den beschreibenden Feldern diese Werte:

```json
{
  "latest_release": {
    "version": "1.2.3+45",
    "filename": "SVA-Fencing-Tester_1.2.3+45.ota",
    "download_url": "https://raw.githubusercontent.com/MiLasGeek/SVA-Fencing-Tester-Portal/main/bin/stable/SVA-Fencing-Tester_1.2.3%2B45.ota",
    "sha256": "64-stellige-kleingeschriebene-sha256-pruefsumme"
  }
}
```

Die Datei wird erst nach vollständigem Download und erfolgreicher Prüfsummenprüfung als Update-Datei angeboten. Solange noch kein freigegebenes Bundle existiert, bleiben `filename` und `sha256` bewusst weg; die Webapp bietet dann keine Direktinstallation an.

## SD-Karten-Recovery

Falls ein reguläres Update nicht möglich ist oder die Webapp nicht geladen werden kann, nutze die [Anleitung zur SD-OTA-Recovery](../docs/manuals/sd_ota_recovery.md).

## Screenshots

Screenshots der einzelnen Webapp-Schritte werden nach Fertigstellung der finalen Update-Oberfläche ergänzt.

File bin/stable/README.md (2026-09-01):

# Stabile OTA-Bundles

Dieser Ordner enthält freigegebene OTA-Bundles für den SVA-Fencing-Tester. Die jeweils aktuelle Version wird über `../version.json` referenziert.

Ältere, kompatible Versionen bleiben hier für einen möglichen Downgrade verfügbar. Verwende nur vollständige `.ota`-Bundles, die für die jeweilige Hardware-Revision freigegeben sind.

Eine Anleitung zum lokalen Update über die Geräte-Webapp findest du in der [Update-Anleitung](../README.md).

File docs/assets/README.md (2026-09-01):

# Dokumentations-Assets

Dieser Ordner enthält Bilder, die in der öffentlichen Dokumentation verwendet werden.

- `Impressum.png` – Grafik mit den im Impressum genannten Kontaktinformationen.
- `hist_01_breadboard_2024.png` – Bild aus der Entwicklungsgeschichte.

Die Assets dienen der Dokumentation und sind nicht als technische Fertigungsunterlagen vorgesehen.

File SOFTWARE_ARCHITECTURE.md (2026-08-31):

# 💻 Software-Architektur & Deterministisches Echtzeit-Framework

Dieses Dokument dokumentiert die softwareseitige Architektur, die asynchrone Kommunikationsmatrix und die Echtzeit-Datenverarbeitung des SVA-Fencing-Testers zum Schutz des geistigen Eigentums (Stand der Technik). Der Fokus der Firmware liegt auf absolutem Determinismus, Lock-Free-Ressourceneffizienz und der Vermeidung von blockierendem Overhead zur Gewährleistung der 860-Hz-Echtzeit-Messtaktung auf der ESP32-S3-Plattform.

---

### 1. Striktes Task-Priorisierungs-Modell (RTOS & Bare-Metal Hybrid)
Die Firmware arbeitet auf Basis von FreeRTOS in Kombination mit hardwarenahen Interrupts (INT) und dedizierten Timern (Ticker). Zur Gewährleistung Jitter-freier Messungen sind die Systemaufgaben streng nach zeitlicher Kritikalität hierarchisch auf die CPU-Kerne aufgeteilt:
* **Priorität 1: Der Mess-Task (Core 0):** Höchste Systempriorität. Liest den I2C-Messwandler (ADS1115) im kontinuierlichen Modus aus, steuert die binäre FET-Kreuzmatrix und berechnet die ratiometrischen Widerstandswerte.
* **Priorität 2: Der UI-Task (Core 1):** Mittlere Priorität. Verwaltet die grafische Benutzeroberfläche des TFT-Displays (Touch-Eingaben, Kurven-Rendering aus dem PSRAM über den SPI-Bus).
* **Priorität 3: Der WiFi/Netzwerk-Task (Core 0/1):** Niedrigste Priorität. Verwaltet den HTTP-Server und die asynchrone Bereitstellung der JSON/Binär-Datenströme für die Webapp.

---

### 2. Lock-Free I2C-Zentralisierung & Thread-Sicherheit
Um blockierende Mutex- oder Semaphor-Sperren (Locks) auf dem I2C-Bus zu verhindern, die das Timing des zeitkritischen Mess-Tasks unvorhersehbar verzögern würden, sind sämtliche I2C-Zugriffe exklusiv im Mess-Task zentralisiert:
* **Flag-Steuerung:** Andere Tasks (z. B. UI oder Webapp) fordern Daten oder Einstellungsänderungen (wie das Schreiben in den FRAM oder das Auslesen der RTC) rein über atomare Status-Flags an. Der Mess-Task arbeitet diese Anforderungen sequenziell in seinen natürlichen Messpausen ab. Der Bus bleibt vollkommen kollisions- und blockierungsfrei.

---

### 3. Ultra-Schlanker Modulo-Ringpuffer (Lock-Free Circular Buffer)
Der Datenaustausch der hochfrequenten Messwerte zwischen Core 0 (Messung) und Core 1 (UI-Darstellung) erfolgt über einen maßgeschneiderten, hochoptimierten Ringpuffer, der ohne Mutex-Sperren auskommt:
* **Entkoppelte Pointer-Logik:** Der Producer (Mess-Task) inkrementiert ausschließlich den `Head`-Pointer. Der Consumer (UI-Task) verwaltet einen eigenen, isolierten `Tail`-Pointer.
* **Modulo- & Overflow-Handling:** Der physische Speicherindex wird über eine einfache Modulo-Operation mit der Pufferkapazität berechnet. Der `Head`-Pointer läuft als fortlaufender Ganzzahlwert ($N \times \text{Kapazität}$) endlos hoch. Dadurch wird das systemkritische Überlauf-Handling (Overflow) mathematisch trivial gelöst, die CPU-Zyklen pro Schreibvorgang auf ein absolutes Minimum reduziert und Race Conditions prinzipiell ausgeschlossen.

---

### 4. Proprietäres Binär-Datenformat zur Bandbreiten-Minimierung
Um den WLAN-Durchsatz und den RAM-Overhead des ESP32-S3 im 860-Hz-Betrieb minimal zu halten, werden Live-Messdaten nicht als Text (JSON), sondern in einem hochkomprimierten, proprietären **16-Bit-Binärformat** gestreamt:
* **2 Steuerbits (Bit 15–14):** Definieren den Kontext des Datenpakets (z. B. Kanal-ID, Statustyp oder Bereichs-Indikator).
* **14 Databits (Bit 13–0):** Übertragen den reinen Nutzwert.
* **Hybride Skalierung (Festkomma & Logarithmisch):** Im FIE-relevanten Niederohmbereich ($< 10\,\Omega$) arbeiten die 14 Bits als hochauflösendes Festkommaformat zur exakten Zehntel-Ohm-Darstellung. Wechselt das System in den hochohmigen Isolationsbereich ($> 500\,\text{k}\Omega$), schaltet das Format automatisch auf eine logarithmische Skalierung um. Dies garantiert ein Maximum an signifikanten Stellen (*Maximum Significants*) bei gleichzeitig maximaler Dynamikreichweite (*Maximum Range*) innerhalb eines einzigen 2-Byte-Wortes.

---

### 5. LittleFS-Partitionierung & Redundantes Dual-App-Speicherschema
Die Flash-Topologie des ESP32-S3 ist strikt in funktionale Segmente unterteilt, um die Speicherbandbreite optimal zu nutzen:
* **Duale App-Redundanz:** Der ausführbare Firmware-Kern arbeitet im klassischen Dual-Partition-Verfahren (app0 und app1). Dies ermöglicht sichere, fehlerresistente Over-the-Air-Updates des Core-Codes im laufenden Betrieb.
* **Isolierte Webapp- & Manual-Partition:** Die komprimierte Single-Page-Application (webapp.gz) sowie die digitalen Benutzerhandbücher (manuals) sind vollständig in eine separate, dedizierte LittleFS-Partition ausgelagert. Dies verhindert das Überschreiten der App-Speichergrenzen und entkoppelt Web-Ressourcen logisch vom Binärcode.

---

### 6. Unzerstörbares Werks-Dateisystem (FFat-Immutable-Partition)
Die Systemarchitektur nutzt eine dedizierte, verschleißfreie Flash-Dateisystempartition (FFat) zur Speicherung der unveränderlichen System-Assets. FIE-Werkspresets, Systemspezifikationen und Custom-Vereinslogos sind direkt in diesem partitionsbasierten Speichersegment verankert. Diese Immutable-Struktur ist fest an den OTA-Update-Pfad gekoppelt, wodurch ein unzerstörbarer System-Fallback (Factory Reset) bei Datenkorruption des externen flüchtigen Speichers systemisch garantiert ist.

---

### 7. Unified-Firmware mit I²C-Autoscan & Fallback-Logik
Die Firmware führt beim Systemstart einen automatischen Peripheriescan durch und adaptiert vorhandene Hardware-Topologien dynamisch zur Laufzeit:
* **Modulare Bestückungsvarianten:** Das System erkennt das Fehlen von RTC (Fallstand: keine Uhrzeit), sekundärem ADC (Wechsel von Parallelsampling auf sequenzielles Time-Multiplexing) oder FRAM (Wechsel auf EEPROM/Flash) und schaltet die Systemlogik verzögerungsfrei in den jeweiligen Fallback-Modus.
* **Vollständige Abwärtskompatibilität:** Durch die Abfrage historischer I²C-Adressen (z. B. 0x2F für Digital-Potentiometer oder 0x68 für ältere RTC-Typen) bleibt ein einziger, einheitlicher Release-Build über alle Hardware-Generationen hinweg (Rev 2.0 bis Rev 4.0) plattformübergreifend lauffähig.
---

### 8. Prädiktiver N-zu-N-Matrix-Optimierungsalgorithmus (Transitive Reduktion)
Zur Maximierung der transienten Erfassungsrate (860 Hz) arbeitet die Firmware nicht mit einem statischen, sequenziellen Durchlaufen aller Kreuzungspunkte, sondern implementiert eine dynamische, graphentheoretische Matrix-Reduktion zur Laufzeit:
* **Transitive Zustandsschlussfolgerung:** Der Algorithmus nutzt die mathematische Transitivität und den historisch ermittelten Systemzustand (Kopplung vs. Isolation), um redundante Messzyklen logisch zu eliminieren. Wird eine niederohmige FIE-Verbindung zwischen Knoten $A_1$ und $A_2$ detektiert sowie eine Isolation zwischen $B_1$ und $A_1$ nachgewiesen, schlussfolgert die State-Machine prädiktiv die Isolation zwischen $B_1$ und $A_2$. Ist zudem $B_1$ mit $B_2$ verbunden, wird die Isolation von $B_2$ zu $A_1$ und $A_2$ rein mathematisch verifiziert, ohne den physischen Messkanal abzufragen.
* **Präventive PGA-Vorselektion:** Basierend auf dem prädiktiv erwarteten Zustand steuert die Firmware das Register des internen Signalverstärkers (PGA) des ADS1115 vorausschauend an. Dies eliminiert Einschwingzeiten (Settling Times) und Sättigungs-Artefakte (Clipping) beim Kanalwechsel vollständig, wodurch die physikalische Zykluszeit auf das absolute Minimum komprimiert wird.

---

### 9. Hochauflösende Einzelpaar-Abtastung (Sub-Matrix-Modus)
Neben dem universellen N-zu-N-Gesamtscan unterstützt die Firmware die gezielte Reduktion der Schaltmatrix auf isolierte Einzelpaar-Prüfungen (z. B. dediziert A1-A2 oder B2-C1). Durch den vollständigen Entfall von Multiplexer-Umschaltzeiten (ADG707) und PGA-Registeranpassungen wird die transiente Abtastrate des 16-Bit-ADC (ADS1115) exakt auf den Zielkanal konzentriert. Dies maximiert die zeitliche Auflösung zur Detektion von Mikrosekunden-Kabelbrüchen unter mechanischer Last (Biegetest), während der Isolations- und Verbindungsstatus des Paares parallel autark abgeleitet wird.

---

### 10. Flankengesteuerte transiente Trigger-Engine & Pre-/Post-Speicherung
Für die detaillierte Analyse des mechanischen Schaltverhaltens von Waffen-Spitzenkontakten implementiert das System eine universelle Signal-Trigger-Engine im Echtzeit-Chart:
* **Flanken-Unabhängiger Trigger:** Die Firmware überwacht kontinuierlich den Gradienten der Widerstandsänderung. Bei Überschreiten der Schwellenwert-Flanke (unabhängig von der Richtung: Low-to-High / High-to-Low) friert das Grafik-Framework das Live-Chart instantan ein.
* **Einstellbares Pre-/Post-Trigger-Verhältnis (X-Prozent):** Der Stopp- und Visualisierungszeitpunkt des eingefrorenen Signalverlanfs ist über einen prozentualen Parameter ($X$) auf der Zeitachse frei konfigurierbar. Dies ermöglicht die exakte geometrische Positionierung des Schaltmomenten auf dem Display, wodurch transiente Prell-Effekte vor dem Stoß (Pre-Trigger) sowie Kontaktschwankungen nach dem mechanischen Anschlag (Post-Trigger) zur tiefgehenden Rüstmeister-Diagnose konserviert werden.

---

### 11. Asymmetrische UI/UX-Visualisierungs-Engine & Gestensteuerung
Zur intuitiven Fehlersuche im Feld implementiert die Core-UI auf Core 1 eine asymmetrische, farbcodierte Signal-Verstärkungs-Engine. Diese übersetzt hochfrequente transiente Messereignisse (860 Hz) in eine für das menschliche Auge optimierte visuelle Dynamik:
* **Asymmetrisches Fade- & Hold-Verfahren (Wackelkontakt-Hold):**
  * *Signal-Eintritt (Gut):* Ein stabiler niederohmiger Durchgang blendet zeitverzögert weich ein (Fade-in zu Grün). Ein transienter Kontaktausfall schaltet die Anzeige ohne Latenz augenblicklich hart um (Sofort-Rot).
  * *Fehler-Austritt (Schlecht):* Ein transienter Fehlerfall triggert sofort die Alarmfarbe Rot. Nach der Stabilisierung des Signals blendet die Warnfarbe verzögert aus (Fade-out). Dieser visuelle Hold-Effekt streckt Mikrosekunden-Einbrüche, wodurch sporadische Wackelkontakte ohne Trägheitsverlust für den Anwender sichtbar werden.
* **Topologie-identische Netz-Matrix & Spline-Visualisierung:** Die UI projiziert ein 1:1 geometrisches Abbild der physischen Buchsenanordnung auf das Display. Elektrische Zustände des prädiktiven N-zu-N-Scans werden in Echtzeit als dynamisches Vektor-Netzwerk dargestellt: Offene Kanäle verbleiben grau, gültige Verbindungen spanen grüne/gelbe Spline-Bögen, und Brückenfehler/Isolationsbrüche leuchten rot auf. Adernvertauschungen sind instantan geometrisch interpretierbar. Die Abklinggeschwindigkeit des Hold-Effekts ist über diskrete Stufen regulierbar (*Off / Fast / Medium / Slow*).
* **Gestenbasierte Landschafts-UI (Flow-Free Interaction):** Die Benutzeroberfläche verzichtet auf starre Menü-Strukturen und Double-Clicks. Die Navigation erfolgt fluid über Gesten (Wischen/Sliden in einer horizontalen UI-Landschaft), Touch-Bereiche und Long-Clicks. Dies gewährt maximale Bedienfreiheit und stellt sicher, dass Laien rein intuitiv über die Farbmetrik (Grün-Gelb-Rot) agieren können, während Rüstmeister parallel die vollständige physikalische Rohdaten-Transparenz erhalten.

---

### 12. Autonome Anschlusspaar-Suchlogik & Zustandshold-Ablauf
Zur Optimierung von Ein-Mann-Prüfungen an langen Hallenleitungen implementiert die Firmware eine zustandsgesteuerte Auto-Lock-Such-Engine:
* **Autonomer Suchmodus:** Solange kein gültiger Messkontakt vorliegt, befindet sich das System im kontinuierlichen Suchlauf. Die RGB-Signalisierung verbleibt hierbei in einem gedimmten, neutralen Weiß (visueller Grauwert).
* **Dynamische Messpaar-Verriegelung:** Bei Eintritt eines stabilen "OK"-Zustands arretiert die Firmware den Messfokus augenblicklich auf diesem dedizierten Paar, schaltet die LED in die aktive FIE-Farbmetrik und aktiviert die akustischen/haptischen Signalgeber. Die Matrix-Verriegelung bleibt so lange aktiv, bis das Signal für eine konfigurierbare, längere Zeitschwelle permanent im "NOK"-Bereich verbleibt. Erst nach Ablauf dieses Timeouts wechselt das Framework kreisfrei zurück in den globalen Suchmodus.

---

### 13. Multimodale Feedback-Kaskade (Buzzer / RGB-LDO / Haptik)
Jeder Messmodus verfügt über vollständig unabhängig konfigurierbare Signalisierungsparameter zur optimalen Anpassung an die Hallenakustik:
* **Akustik-Profil (Buzzer):** Softwareseitig modulierbar in den Stufen *Off / Short NOK / Long NOK / OK*.
* **Haptik-Profil (Vibrationsmotor):** Angesteuert über den dedizierten Treiber-IC NCP18255 zur direkten mechanischen Alarmierung bei transienten oder permanenten Fehlern (*Off / Short NOK / Long NOK*), um akustische Störungen in der Fechthalle zu umgehen.
* **Visuelles Umgebungs-Mapping (RGB-LED):** Gepuffert über eine 74LVC1617-Treiberstufe arbeitet die externe RGB-Status-LED synchron mit der asymmetrischen Fading- und Farb-Engine des Hauptdisplays. Die Grundhelligkeit ist zur Vermeidung von Blendeffekten bzw. zur Maximierung der Tageslichttauglichkeit vollständig per Software registergesteuert skalierbar.

---

### 14. FIE-Preset-Validierung & Sabotageschutz
Zur Einhaltung internationaler Wettkampfstandards implementiert die Firmware eine manipulationssichere Preset-Validierungs-Engine für die Materialkontrolle:
* **Permanentes Visuelles FIE-Feedback:** Das aktiv geladene FIE-Regelwerk mitsamt den exakten physikalischen Grenzwerten wird permanent transparent im UI dargestellt. Dies sichert eine unanfechtbare Nachvollziehbarkeit bei offiziellen Waffenkontrollen auf Turnieren.
* **Read-Only Firmware-Lock:** Die Kern-Grenzwerte sind im Firmware-Image als unveränderliche Read-Only-Konstanten fest verankert und hardwareseitig über die aktive Flash-Verschlüsselung (Flash Encryption) gegen jegliche lokale oder physische Manipulation geschützt. 
* **Zentralisiertes Webapp-Update:** Zukünftige offizielle Regeländerungen des Internationalen Fechtverbandes (FIE) können ohne Hardware-Modifikationen über die integrierte Webapp per passwortgeschütztem Over-the-Air-Update (OTA) eingespielt und im FRAM dynamisch aktualisiert werden.

---

### 15. Granulares JSON-Parameter-Framework & Asymmetrischer Krypto-Import
Für das effiziente Flottenmanagement implementiert die Firmware eine konfigurierbare Im-/Export-Schnittstelle auf JSON-Basis über die integrierte Webapp:
* **Selektiver Import via Kategorie-Filter:** Beim Einspielen der JSON-Konfigurationsdatei erlauben modulare Checkboxen das selektive Überschreiben spezifischer Datenklassen (z. B. Hardware-Kalibrierungsdaten vs. globale Systemeinstellungen).
* **Asymmetrische Credential-Sicherheit:** WiFi-Zugangsdaten (SSID/Passwort) werden beim Export aus dem Gerät kryptografisch verschlüsselt in die JSON-Struktur eingebunden. Der Import-Parser akzeptiert zur vereinfachten Erstprovisionierung neuer Geräte über den Administrations-PC jedoch auch unverschlüsselte Klartext-JSON-Profile.

---

### 16. Dual-Netzwerk-Topologie & Dynamische QR-Code-Kopplungs-Engine
Das Kommunikationsmodul unterstützt den parallelen oder exklusiven Betrieb als eigenständiger Access Point (AP-Mode) oder als Netzknoten im bestehenden Infrastruktur-Netzwerk (Client-Mode). Zur Eliminierung manueller Eingabefehler im Hallenbetrieb generiert das TFT-Grafikframework dynamische QR-Codes im Geräte-Display:
* **WiFi-AP-Connect:** Automatisierte Endgeräte-Kopplung an den verschlüsselten Access Point ohne manuelle Passworteingabe.
* **Webapp-Redirect:** Direkter Aufruf der REST/WebSocket-Schnittstelle via lokaler mDNS-Namensauflösung (`fencingtester.local`).
* **Public-Repo-Link:** Permanenter QR-Verweis auf das öffentliche GitHub-Repository zur abrufbaren Bereitstellung der Open-Hardware-Dokumentation im Feld.

---

### 17. Integrierter Recovery-Webserver & Autarker SD-Karten-OTA (Offline Rescue)
Zur Gewährleistung einer absoluten Ausfallsicherheit (Anti-Brick-Schutz) implementiert das System eine mehrstufige Notfall-Update-Kaskade:
* **Automatischer Notfall-OTA-Server:** Erkennt die Firmware beim Systemstart eine Beschädigung oder das vollständige Fehlen der webapp.gz in der LittleFS-Partition, startet die MCU autark einen minimalistischen, fest im Core-Image integrierten Recovery-Webserver. Dieser stellt via Direktaufruf eine native HTML-Schnittstelle bereit, über die die LittleFS-Dateistruktur direkt im Browser ohne externe Programmierwerkzeuge wiederhergestellt werden kann.
* **Hardwarenaher SD-OTA-Pfad:** Für den netzwerkunabhängigen Offline-Einsatz in isolierten Fechthallen verfügt das System über eine autarke SD-Karten-Update-Routine. Beim Booten detektiert die Firmware das Vorhandensein spezifischer Binärdateien auf dem SD-Speichermedium (J4-Schnittstelle) und triggert einen vollautomatischen lokalen Flash-Vorgang für die App- oder Filesystem-Bereiche.

---

### 18. Asymmetrisches UI-Design-Framework & Visuelle Skalierungslogik
Das visuelle Konzept folgt einer dualen Design-Philosophie, die strikte funktionale Konsistenz mit gerätespezifischer UX-Optimierung kombiniert:
* **Device-UI (Strikter Minimalismus):** Die hardwareintegrierte Benutzeroberfläche auf dem 2,8"-TFT-Display ist sachlich, unverschnörkelt und auf maximale Kontrastwerte optimiert. Jede visuelle Redundanz wird zugunsten einer fehlerfreien Ablesbarkeit im hektischen Hallenbetrieb unter schwierigen Lichtverhältnissen eliminiert.
* **Webapp-UI (Feingranulares Diagnose-Center):** Die Client-Side-Webapp spiegelt die Kern-Struktur und den Bedien-Flow der Device-UI 1:1 wider, nutzt jedoch die höhere Pixeldichte moderner Endgeräte-Displays aus. Durch feinere Vektorgrafiken, abgerundete UI-Elemente und strukturierte Hintergrund-Farbpaletten wird eine hochwertige High-End-Ästhetik erzielt.
* **Flächeneffizientes Informations-Mapping:** Der zusätzliche Anzeigeraum auf größeren Client-Bildschirmen wird explizit zur Skalierung hochauflösender Live-Widerstands-Charts und Trendkurven genutzt. Das Aufblähen von reinem Text wird systemisch verhindert. Der globale Informations- und Bedien-Flow ist streng linear von links nach rechts sowie von oben nach unten ausgerichtet und folgt der physischen Geometrie des äußeren Buchsenlayouts.

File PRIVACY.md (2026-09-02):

# Datenschutzerklärung (DSGVO)

Der Schutz deiner persönlichen Daten ist uns ein wichtiges Anliegen. Nachfolgend informieren wir dich über den Umgang mit deinen Daten im Rahmen dieses GitHub-Repositories. 

Da dieses Projekt auf der Plattform GitHub gehostet wird, weisen wir darauf hin, dass die grundlegende technische Infrastruktur von der GitHub, Inc. bereitgestellt wird.

---

### 1. Verantwortlicher im Sinne der DSGVO
Verantwortlich für die Datenverarbeitung in diesem spezifischen Repository ist der im [Impressum](IMPRINT.md) genannte Betreiber des Projekts.

---

### 2. Datenverarbeitung durch den Plattform-Betreiber (GitHub)
Dieses Repository wird auf GitHub gehostet. Wenn du diese Seite besuchst, erfasst GitHub automatisch Protokollierungsdaten (z. B. deine IP-Adresse, Browsertyp, Datum und Uhrzeit des Zugriffs). Auf diese Datenverarbeitung haben wir keinen Einfluss.

GitHub verarbeitet Nutzungs- und Inhaltsdaten im Rahmen der eigenen Plattformverantwortung. Informationen zu Empfängern, möglichen internationalen Datenübermittlungen und den dort geltenden Schutzmaßnahmen findest du in der [GitHub Privacy Statement](https://docs.github.com/de/site-policy/privacy-policies/github-privacy-statement).

---

### 3. Datenverarbeitung bei Interaktion (Issues, Discussions, Pull Requests)
Wenn du aktiv mit diesem Repository interagierst (z. B. einen Bug-Report im Tab „Issues“ erstellst oder dich im virtuellen Vereinsheim unter „Discussions“ austauschst), werden folgende Daten öffentlich sichtbar verarbeitet:
* Dein GitHub-Benutzername und dein Profilbild.
* Der Inhalt deines Beitrags (z. B. Fehlerbeschreibungen, Fragen zum Fechtsport-Tester oder hochgeladene Logfiles/Bilder).
* Der Zeitpunkt deiner Interaktion.

**Zweck der Verarbeitung:** Bereitstellung einer Support- und Austauschplattform für Fechter und Vereine, Fehlerbehebung der Firmware/Hardware sowie die kontinuierliche Weiterentwicklung des Projekts.
**Rechtsgrundlage:** Die Verarbeitung erfolgt auf Grundlage unseres berechtigten Interesses an der Kommunikation mit Nutzern und der Verbesserung unseres Non-Profit-Projekts (Art. 6 Abs. 1 lit. f DSGVO).
**Empfänger:** Die Beiträge werden über GitHub verarbeitet und sind bei öffentlichen Issues, Discussions und Pull Requests für die Öffentlichkeit sichtbar. Darüber hinaus setzen wir für dieses Repository keine eigenen Tracking- oder Analysedienste ein.

---

### 4. Hardware- und Ersatzteilanfragen
Sobald die Testphase beendet ist und Anfragen für Komplettgeräte oder vorbestückte Platinen über GitHub-Formulare (Issue Templates) möglich sind, verarbeiten wir die von dir dort freiwillig angegebenen Daten (z. B. Vereinsname, Stückzahlen). 
* Diese Daten dienen ausschließlich der Vorbereitung und – erst nach Abschluss der Testphase – der Abwicklung eines angefragten Materialkosten- und Aufwandsersatzes.
* Eine Weitergabe erfolgt nur, soweit sie für die Abwicklung erforderlich oder gesetzlich vorgeschrieben ist. Hardware-Anfragen sind während der Testphase deaktiviert.
**Rechtsgrundlage:** Die Verarbeitung dient der Anbahnung oder Erfüllung einer privaten Vereinbarung über den Aufwandsersatz (Art. 6 Abs. 1 lit. b DSGVO).

---

### 5. Speicherdauer
* **Öffentliche Beiträge:** Beiträge in Issues und Discussions bleiben grundsätzlich sichtbar, solange sie auf GitHub veröffentlicht sind. Die Bearbeitung oder Löschung richtet sich nach den Funktionen und Richtlinien von GitHub; bei berechtigten Löschanfragen kannst du den im Impressum genannten Kontakt nutzen.
* **Anfragen:** Daten aus später aktivierten Hardware-Anfragen werden nur so lange gespeichert, wie dies für die Bearbeitung, Abwicklung und gegebenenfalls gesetzliche Aufbewahrungspflichten erforderlich ist.

---

### 6. Deine Rechte
Du hast im Rahmen der DSGVO das Recht auf kostenlose Auskunft über deine bei uns gespeicherten Daten (Art. 15 DSGVO) sowie ein Recht auf Berichtigung (Art. 16 DSGVO), Löschung (Art. 17 DSGVO) oder Einschränkung der Verarbeitung (Art. 18 DSGVO) dieser Daten. 

Da deine Beiträge auf GitHub öffentlich sind, kannst du viele davon selbst editieren oder löschen. Bei Fragen zur Löschung von Inhalten, die du nicht selbst entfernen kannst, wende dich bitte an die im Impressum angegebene E-Mail-Adresse. Zudem steht dir ein Beschwerderecht bei einer Datenschutz-Aufsichtsbehörde zu.

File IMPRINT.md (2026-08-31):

# Impressum & Anbieterkennzeichnung

Angaben gemäß § 5 Digitale-Dienste-Gesetz (DDG). 

Da es sich hierbei um ein ehrenamtliches Non-Profit-Projekt zur Unterstützung von Fechtvereinen handelt, werden die privaten Kontaktdaten des Entwicklers zum Schutz vor automatisiertem Spam und Text-Scraping als Grafik bereitgestellt.

### Diensteanbieter & Kontakt
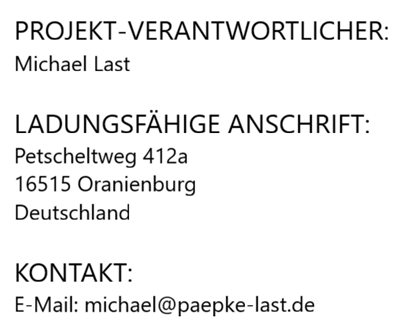
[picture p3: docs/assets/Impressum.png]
Kontaktdaten für das Impressum


*(Hinweis: Sollte das Bild oben nicht laden, findest du die Kontaktdaten direkt in der Datei `docs/assets/Impressum.png` im Repository).*

---

### Rechtliche Hinweise & Haftungsausschluss (Disclaimer)

#### 1. Haftungsbeschränkung für Inhalte und Downloads
Die Inhalte dieses Repositories (Firmware-Binärdateien, 3D-Druckdaten, Handbücher und Bauanleitungen) wurden mit größtmöglicher Sorgfalt erstellt. Da es sich um eine private, nicht-kommerzielle Initiative handelt, erfolgt die Bereitstellung aller Daten ausdrücklich ohne Mängelgewähr („as is“) sowie ohne jegliche vertragliche Garantie oder Zusicherung von Eigenschaften. Eine Haftung für die Richtigkeit, Vollständigkeit und Aktualität der bereitgestellten Daten wird ausgeschlossen.

#### 2. Haftungsausschluss für Sach- und Personenschäden
Die Nutzung der Firmware sowie der Nachbau der Hardwarekomponenten (einschließlich Platinenbestückung und 3D-Druck-Gehäuseteilen) geschehen vollständig auf eigene Gefahr und eigenes Risiko des Nutzers oder des jeweiligen Fechtvereins. Der Betreiber dieses Portals haftet nicht für Schäden, die durch unsachgemäßen Zusammenbau, fehlerhafte Bauteile, Akku-Fehlfunktionen oder den Einsatz des Fencing-Testers bei der Materialkontrolle entstehen.

#### 3. Urheberrecht & Lizenzierung
Die Urheberrechte für die bereitgestellten Inhalte verbleiben beim Portal-Betreiber. Die Firmware wird ausschließlich im Binärformat (Binary-only) bereitgestellt. Für die im Hardware-Ordner hinterlegten 3D-Druckdaten gilt die Lizenz **Creative Commons Namensnennung - Nicht-kommerziell - Weitergabe unter gleichen Bedingungen 4.0 International (CC BY-NC-SA 4.0)**. Jede kommerzielle Nutzung oder der Weiterverkauf von Gehäuseteilen ist untersagt.

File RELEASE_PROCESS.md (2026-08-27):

# 🚀 SVA-Fencing-Tester – Release Checklist

Dieses Dokument dient als Leitfaden für die manuelle Release-Erstellung und das Deployment auf den öffentlichen `main`-Branch des Portals.

## 1. Vorbereitung & Code-Härtung (Privat)
- [ ] **Compiler-Schalter prüfen:** Sicherstellen, dass alle Test- und Debug-Bibliotheken (wie z. B. der alte FTP-Server oder serielle Ausgaben) für die Produktion per `#ifdef` deaktiviert sind.
- [ ] **Sicherheit aktivieren:** Firmware-Verschlüsselung aktivieren.
- [ ] **Bundle bauen:** Die lokale Webapp komprimieren (`webapp.gz`) und das LittleFS-Image inklusive des aktuellen `device_manual_lite.pdf` erstellen.
- [ ] **Kompilieren:** Den automatisierten Post-Build-Workflow ausführen, um das finale Kombi-Bundle (`.ota`) zu generieren.

## 2. Automatisierter Lizenz-Export (Yarn / Webapp)
Da die Webapp-Abhängigkeiten (Vue, Vite-Plugins, Bootstrap etc.) stark verschachtelt sind, wird der Export vor dem Release kurz automatisiert:
- [ ] Öffne das Terminal in deinem `webapp/`-Ordner.
- [ ] Führe folgenden Befehl aus, um alle aktiven Produktions-Lizenzen in eine Textdatei zu schreiben:
  ```bash
  npx license-checker-rseidelsohn --production --csv > webapp_lizenzen.txt
  ```

## 3. KI-gestützter Dokumentationsabgleich
- [ ] Kopiere den Inhalt der generierten `webapp_lizenzen.txt` und deine aktuelle `platformio.ini`.
- [ ] Übergib die Daten an die KI mit dem Befehl: 
  *"Hier sind meine aktuellen Webapp- und Firmware-Abhängigkeiten. Aktualisiere bitte die Tabelle in meiner docs/compliance/THIRD_PARTY_LICENSES.md und behalte das bestehende Format bei."*
- [ ] Kopiere die von der KI generierte Markdown-Tabelle und füge sie in deine `THIRD_PARTY_LICENSES.md` im Portal ein.
- [ ] Trage die neue Versionsnummer, den Build-Counter und das aktuelle Datum in die `bin/CHANGELOG.md` ein.

## 4. Manuelles Deployment (Public Portal)
- [ ] Wechsle in deinem Portal-Repository auf den Branch **`main`**.
- [ ] Kopiere das neue `.ota`-Bundle in den Ordner `bin/stable/`. 
- [ ] Lösche bei Bedarf uralte Builds, behalte aber die letzten *n* Versionen als schnelles Downgrade-Sicherheitsnetz im Ordner.
- [ ] Aktualisiere die `bin/version.json` mit der neuen Versionsnummer, dem exakten Dateinamen und dem korrekten GitHub-Raw-Link, der auf den `main`-Branch zeigt.
- [ ] Pushe die Änderungen auf den **`main`**-Branch.
- [ ] **Live-Test:** Verbinde ein Testgerät im Offline-WLAN, öffne die About-Page und prüfe, ob der Client-Browser den Versionsabgleich über die neue `version.json` fehlerfrei ausführt.

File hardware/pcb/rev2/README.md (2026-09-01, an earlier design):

# PCB – Revision 2

| Ansicht | Datei |
| --- | --- |
| Bestückungsseite | [pcb-rev2-bottom.png](./pcb-rev2-bottom.png) |
| Display-/Frontansicht | [pcb-rev2-display.png](./pcb-rev2-display.png) |

Die Renderings zeigen Revision 2 zur visuellen Identifikation. Sie enthalten keine editierbaren PCB-, Schaltplan- oder Fertigungsdaten.

Das vollständige 3D-Modell für Gehäuse-CAD ist unter [sva-fencing-tester-rev2.step](../../models/sva-fencing-tester-rev2.step) verfügbar.

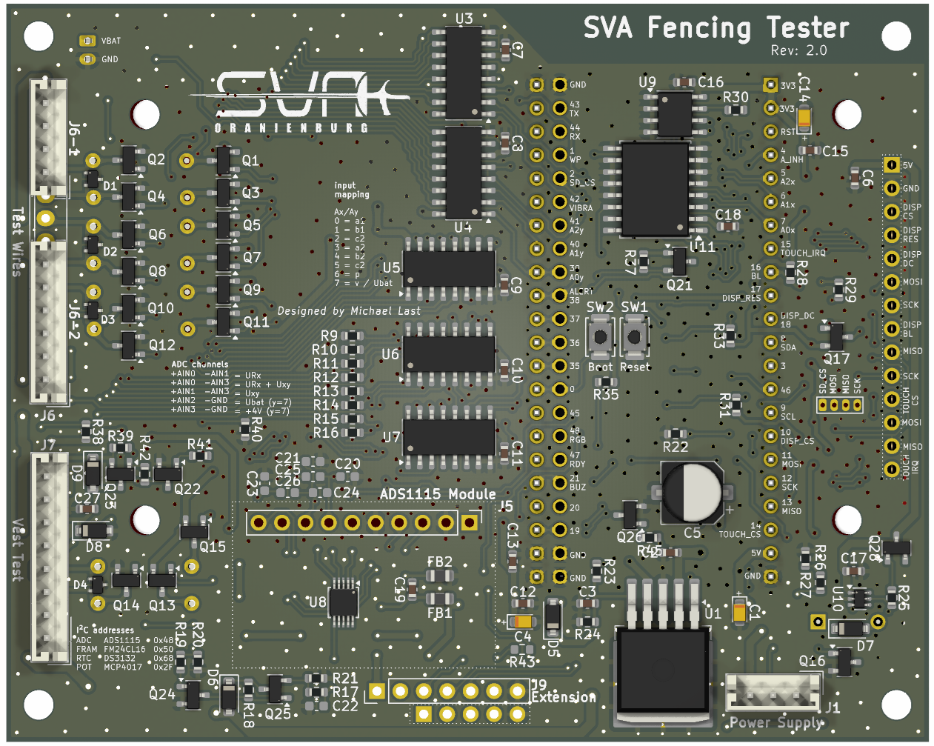
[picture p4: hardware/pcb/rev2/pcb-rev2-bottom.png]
Bestückungsseite Rev 2


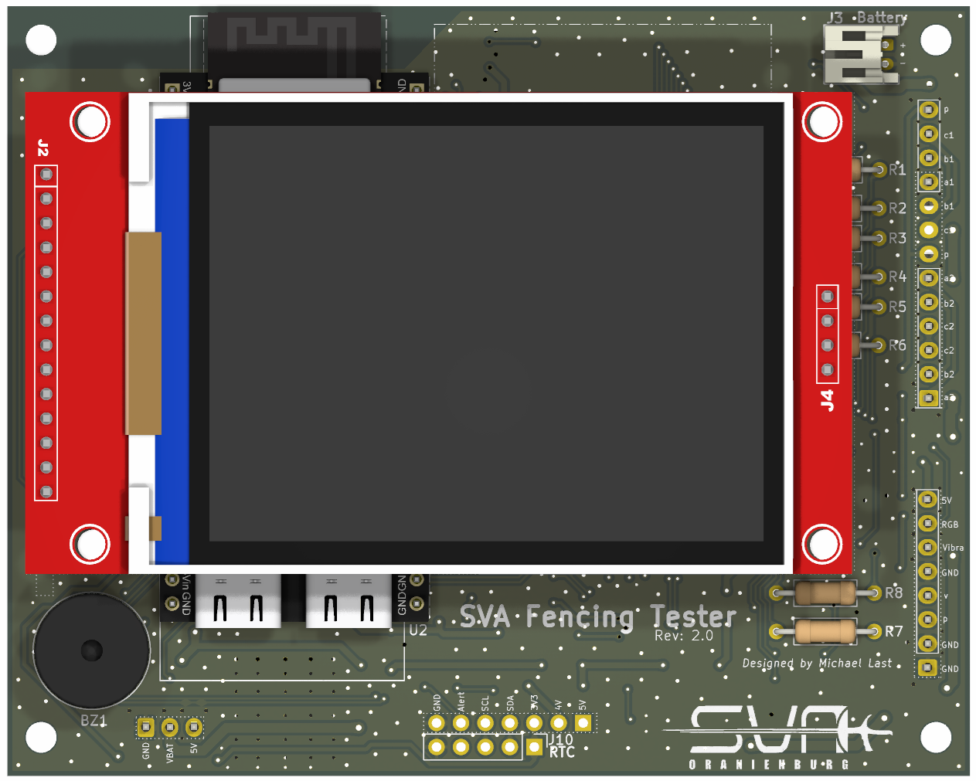
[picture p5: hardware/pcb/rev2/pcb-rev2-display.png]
Display-/Frontansicht Rev 2


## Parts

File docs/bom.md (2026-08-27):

# 🛠️ Bill of Materials (BOM) & Spare Parts Specification

The SVA-Fencing-Tester utilizes a hybrid repair philosophy to balance electronic reliability with maintenance accessibility for fencing clubs. This documentation and portal exclusively support the current **Revision 4 (Hardware Rev 4)**. Legacy versions (such as Revision 2 from 2024) are deprecated due to shifting technical requirements and regulatory compliance standards.

## ⚠️ High-Density SMD Warning (Main PCB)
The Core Carrier PCB is a highly integrated, custom **surface-mount device (SMD)** assembly. The ESP32 module is soldered directly onto the board with a hidden thermal ground pad underneath. 
* **No Field Rework:** Individual electronic components, chips, and the MCU itself **cannot be replaced by hand or with standard soldering irons** at the club.
* **Component Replacement:** In the event of a core hardware failure, the entire pre-assembled PCB must be swapped out, or the device must be sent back for specialized volunteer repair.

---

## 📐 Core Components & Dynamic Market Cost

All components are purchased with regular gross taxes included from official distributors (Mouser, Aisler). 

> 📊 **Note on Pricing & Component Markets:** Due to heavy price fluctuations in the international semiconductor and microcontroller markets, component costs are highly volatile. Once the final calculation for Rev 4 is finalized, a dated reference sheet will be uploaded. Currently, all part requests are evaluated at the exact market-rate billing cost at the time of procurement.

| Component | Specification / Type | Function / Integration | Primary Source | Club Replaceable? | Cost State |
| :--- | :--- | :--- | :--- | :--- | :--- |
| **Main PCB Assembly** | SVA-Fencing-Tester Rev 4 (Custom SMD) | Core routing, power management & embedded ESP32 module | [Aisler](https://aisler.net) / Pre-Assembled | **No** (Swap entire board only) | *Market dependent (On Request)* |
| **OLED Display** | 2.42" Module (SPI / I2C Variant) | Local UI & target hit visualization | [Mouser](https://mouser.com) | **Yes** (Via modular connector) | *Market price* |
| **Battery Pack** | LiPo 3.7V (with integrated PCM circuit) | Mobile power supply using a **JST-connector** | Reliable Battery Vendor | **Yes** (Plug & Play - No soldering) | *Market price* |
| **Fencing Sockets** | Three-Pin Sockets (Standard FIE) | Weapon & Reel hardware interface | Fencing Suppliers | **Yes** (Via screw terminals) | *Market price* |

---

## 📦 Mechanical & 3D-Printed Parts

Structural parts are 100% user-replaceable. Files are located in the `/hardware` directory of this portal.
* **Basic Enclosure:** Shell for everyday club use. Available in `/hardware/housing-basic/`.
* **Wear Parts:** High-stress elements like button caps, enclosure clips, and protective bumpers. Available in `/hardware/spare-parts/`.

---

## 🔧 Repair & Service Strategy for Clubs

1. **Modular Self-Service:** Fencing clubs are highly encouraged to perform simple swaps themselves (replacing the display, changing the battery pack via JST plug, or 3D-printing worn-out plastic parts).
2. **PCB Failure Support:** If the main electronics fail, do not attempt to desolder the ESP32. Please open a [Hardware Request Ticket](../../issues) to coordinate either a full board replacement (at current material cost) or an ehrenamt-level repair request depending on volunteer availability.

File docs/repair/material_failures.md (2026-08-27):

# 🔧 Material Testing & Workshop Diagnosis Guide (Rev 4)

*Note: The SVA-Fencing-Tester is strictly a specialized workshop diagnostic tool for material inspection, maintenance, and repair. It is **not** a piste scoring box (Melder) and is not intended for tournament signaling.*

When testing equipment, the tester's high-speed sampling loop and real-time data stream will help you isolate typical mechanical and electrical material failures before the gear enters the strip.

---

## 1. Dirty or Oxidized Weapon Tips (Foil / Epee)

### 📊 Detection via Tester
The real-time status output or parameter log shows erratic resistance spikes or inconsistent state changes when the point is depressed slowly.

### 🔍 Root Cause
Sweat, dirt, and insulating oxide layers accumulate inside the barrel. This prevents clean electrical contact, confusing standard scoring boxes later on.

### 🛠️ Workshop Action
1. Disassemble the weapon tip (remove the tiny tip screws safely).
2. Clean the internal contact spring and the cavity using a cotton swab dipped in Isopropyl Alcohol (IPA).
3. Check for structural deformations of the barrel. Reassemble and run a dynamic compression test using the tester's live view.

---

## 2. Mechanical Contact Bouncing (Prellen)

### 📊 Detection via Tester
A single mechanical compression registers as multiple, rapid micro-breaks or multiple rapid hits within a few milliseconds in the data stream.

### 🔍 Root Cause
"Contact Bouncing" (Prellen) happens when metal strikes metal. While the SVA firmware handles software-level debouncing, severe mechanical bouncing indicates a degraded or structurally fatigued spring that vibrates excessively upon impact.

### 🛠️ Workshop Action
1. Test the weight spring tension using the official FIE specification gauges (500g for Foil / 750g for Epee).
2. If the tester registers prolonged bouncing beyond acceptable microsecond margins, stretch the return spring slightly or replace it with a factory-new spring.

---

## 3. Sliding Contact Noise ("Bürstenfeuer") in Cord Reels

### 📊 Detection via Tester
The tester logs rapid CRC errors, flickering connection IDs, or massive electrical noise spikes specifically *while* the cable is being pulled out or reeled back into the drum.

### 🔍 Root Cause
The sliding carbon brushes or copper tracks inside the floor reel (Rolle) are worn, dusty, or oxidized. Movement triggers micro-arcs and transient breaks ("Bürstenfeuer"), causing heavy signal degradation.

### 🛠️ Workshop Action
1. Mount the reel to the workshop bench and connect it to the tester without a weapon attached.
2. Slowly pull the cable to its full length while observing the binary data stream.
3. If noise occurs, open the reel housing, remove dust/grease build-up from the copper tracks, and clean the brushes. Apply a microscopic layer of specialized conductive contact grease if necessary.

---

## 4. Body Cord & Mask Cord Micro-Breaks

### 📊 Detection via Tester
The tester reports a stable connection, but sudden breaks occur when the cable is flexed, twisted, or shaken near the plugs.

### 🔍 Root Cause
Internal copper strand fractures inside the insulation, usually right at the strain relief of the three-pin or two-pin plug.

### 🛠️ Workshop Action
1. Connect the cable to the tester and activate the hardware log / touch-debug routine if available.
2. Systematically flex the cable centimeter by centimeter, especially near the connectors.
3. Once the tester signals a break, cut the cable 5 cm below that point, strip the wires, and re-terminate the plug terminals.

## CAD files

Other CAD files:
hardware/models/sva-fencing-tester-pcb-reference.step

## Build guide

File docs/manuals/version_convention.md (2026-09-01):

# 🏷️ Firmware Naming & Versioning Convention

To ensure full traceability across our automated pre- and post-build systems, all official binary bundles deployed to the `main` branch follow a strict naming matrix.

## 📐 Filename Pattern
`SVA-Fencing-Tester.release_[MAJOR].[MINOR].[PATCH]+[BUILD]_[YYYY-MM-DD]_[HH]_[MM].ota`

### Breakdown of the Matrix Components:
* **`SVA-Fencing-Tester.release_`**: Fixed prefix identifying official production/testing distribution builds.
* **`[MAJOR]`**: Incremented for groundbreaking changes (e.g., complete UI overhaul, structural breaking changes in the communication protocol).
* **`[MINOR]`**: Incremented for new feature additions (e.g., adding a new fencing tournament mode to the webapp).
* **`[PATCH]`**: Incremented for backward-compatible bug fixes (e.g., UI alignment fixes or battery calibration tweaks).
* **`+[BUILD]`**: The absolute build counter from the automated build pipeline. Essential for distinguishing multiple compilations within the same patch level.
* **`_[YYYY-MM-DD]`**: The exact compilation date (Year-Month-Day).
* **`_[HH]_[MM]`**: The exact compilation time (Hour-Minute) in 24h format.

---

## 🔍 Practical Example
`SVA-Fencing-Tester.release_0.7.0+71_2026-08-17_17_31.ota`

* **Version:** 0.7.0
* **Build Number:** 71
* **Date of Compilation:** August 17, 2026
* **Time of Compilation:** 17:31 (5:31 PM)

## 🤖 Webapp & Device Parsing Logic
The internal updater firmware and the client-side browser bridge use the `+` delimiter to split the active core version string from the build metadata. When the client-side browser bridge fetches the `version.json` from the `main` branch, it evaluates:
1. Is the `[MAJOR].[MINOR].[PATCH]` string higher than the flashed version?
2. If versions match, is the `[BUILD]` number higher than the current device state?

This guarantees that incremental test builds can be pushed and evaluated by test devices without needing to bump the main release version prematurely.

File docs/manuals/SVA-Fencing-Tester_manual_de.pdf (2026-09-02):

# Bedienungsanleitung

# SVA-Fencing-Tester

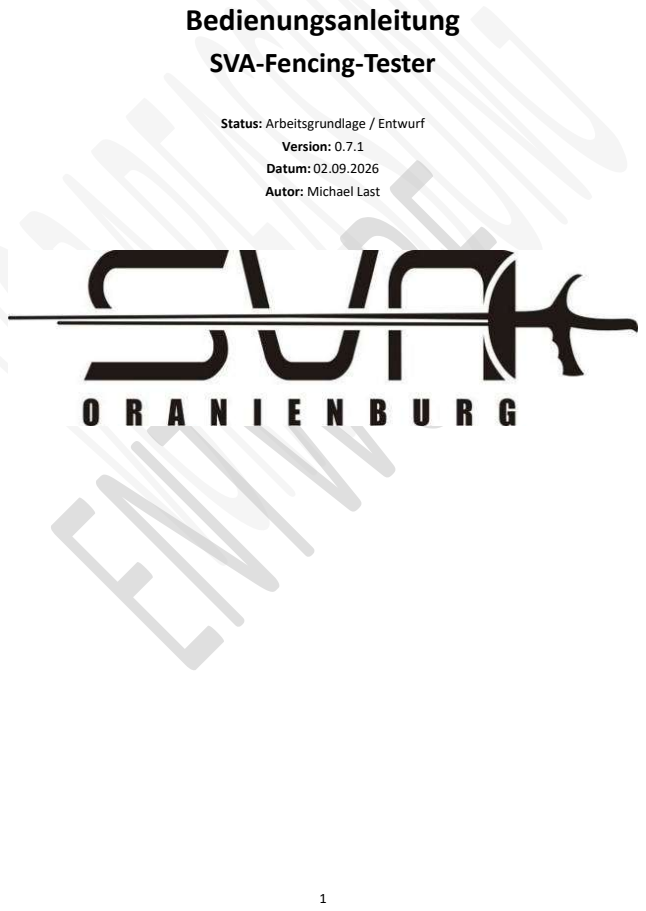
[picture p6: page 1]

Status: Arbeitsgrundlage / Entwurf

Version: 0.7.1
Datum: 02.09.2026
Autor: Michael Last

## Inhaltsverzeichnis

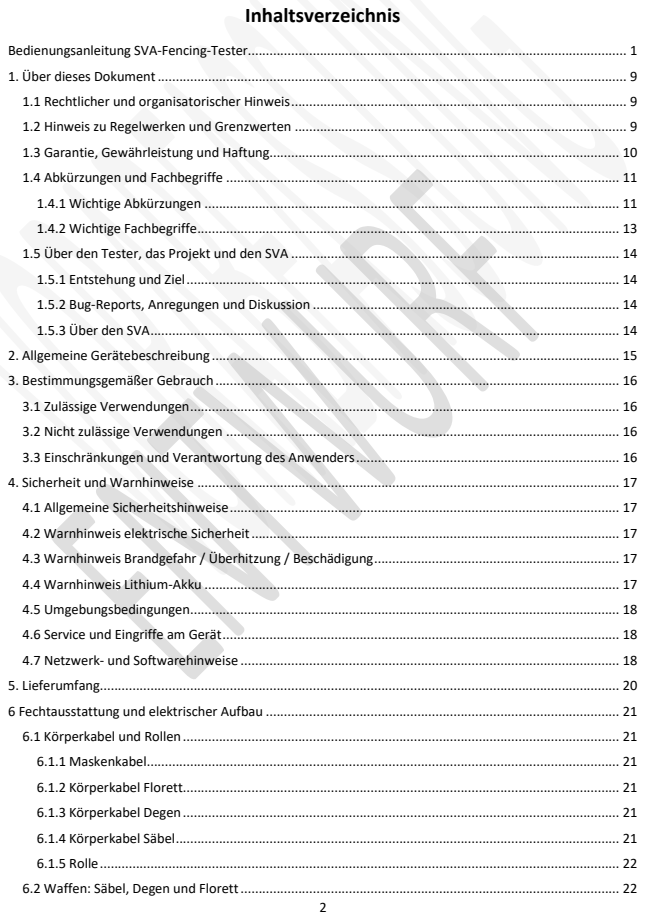
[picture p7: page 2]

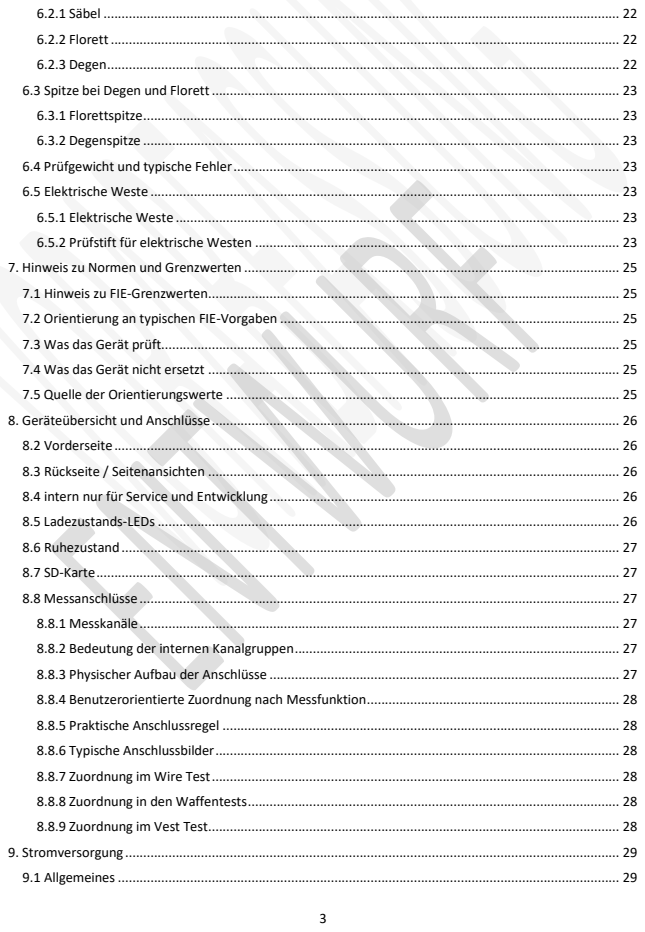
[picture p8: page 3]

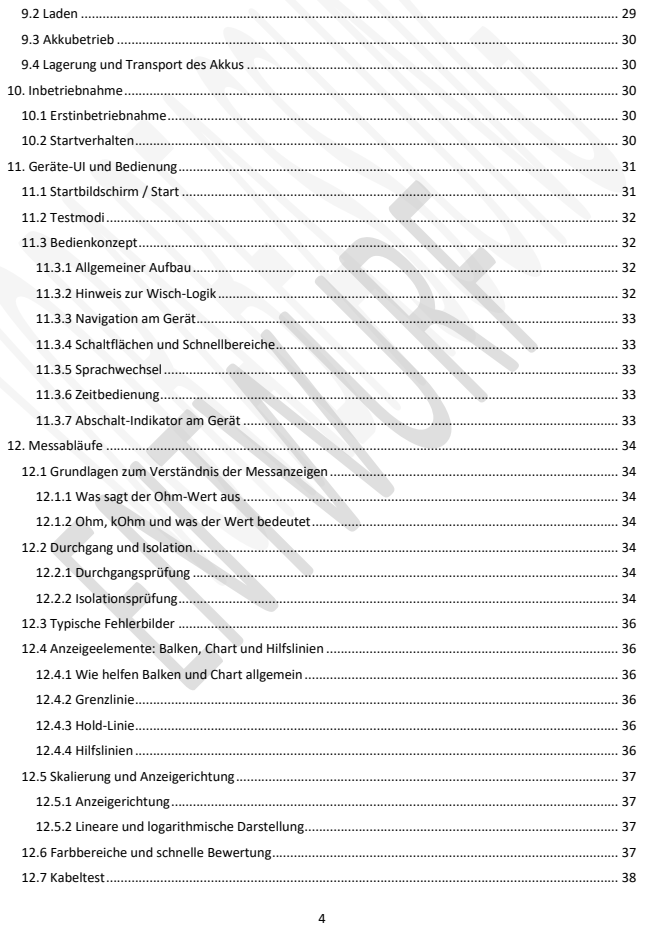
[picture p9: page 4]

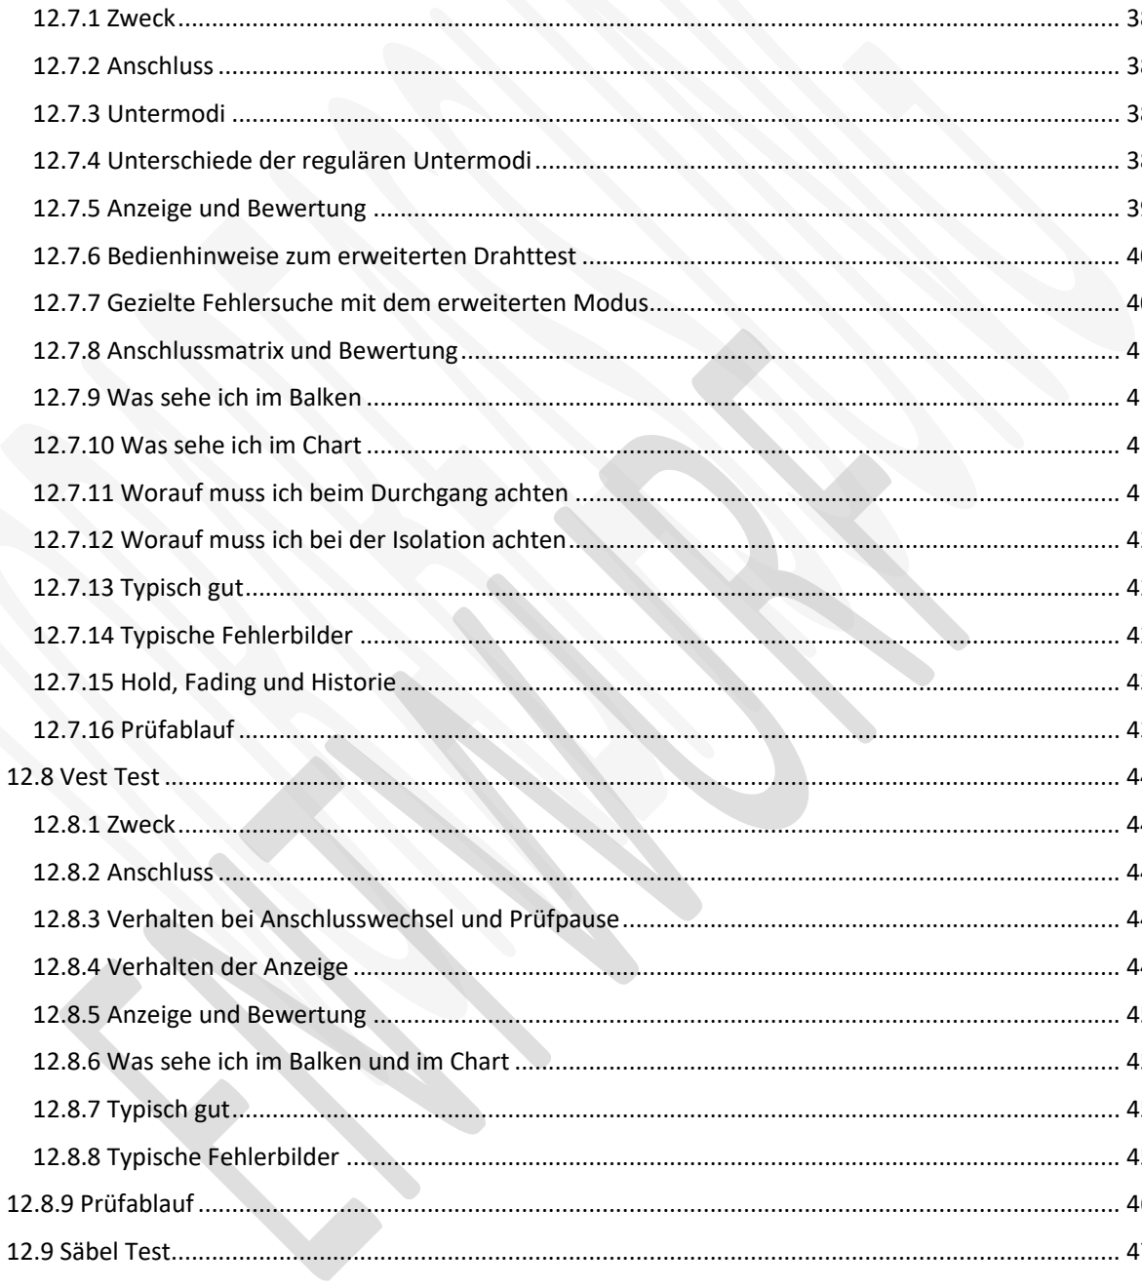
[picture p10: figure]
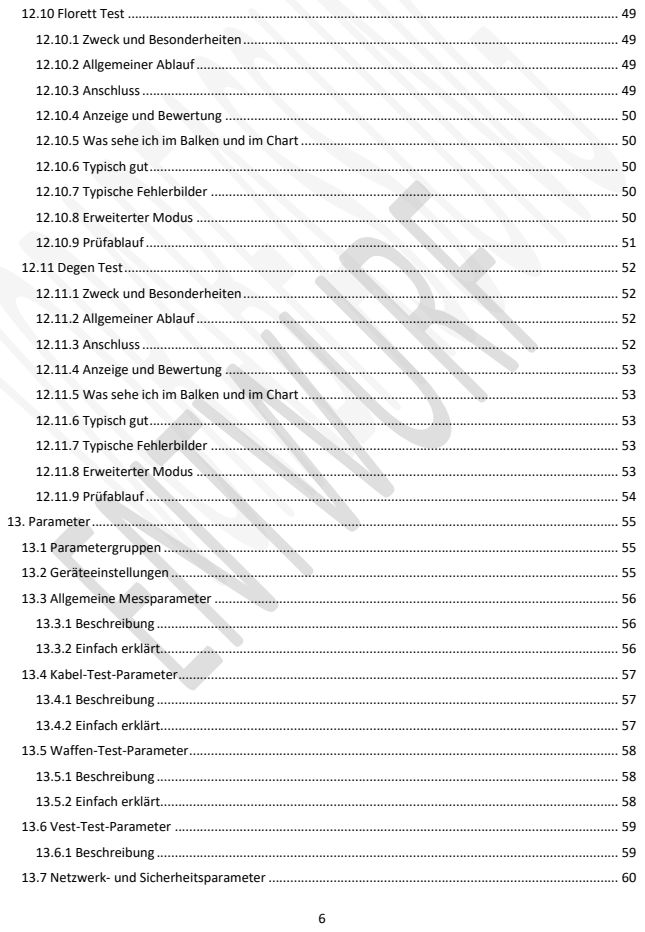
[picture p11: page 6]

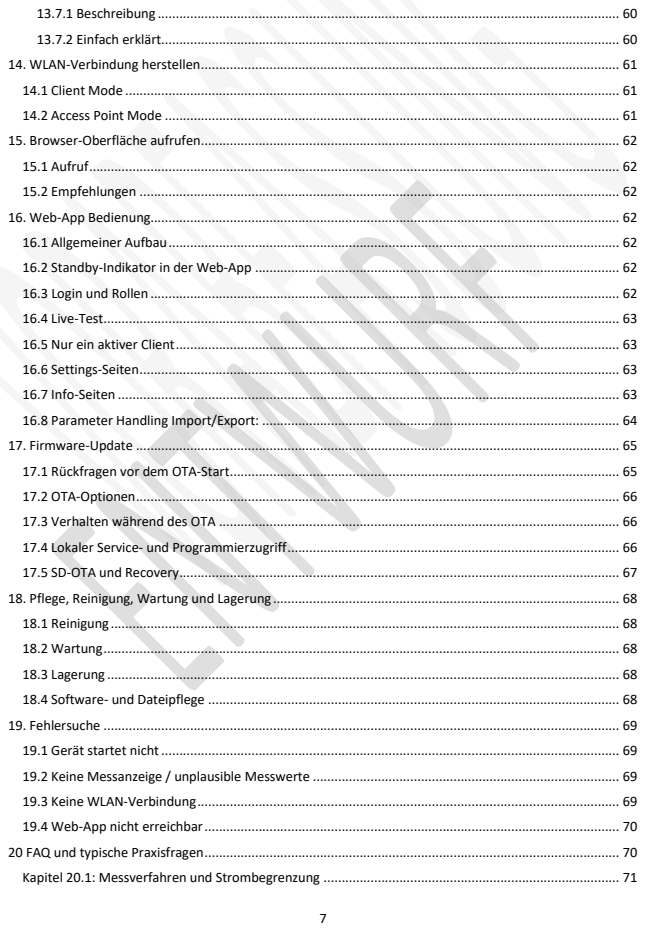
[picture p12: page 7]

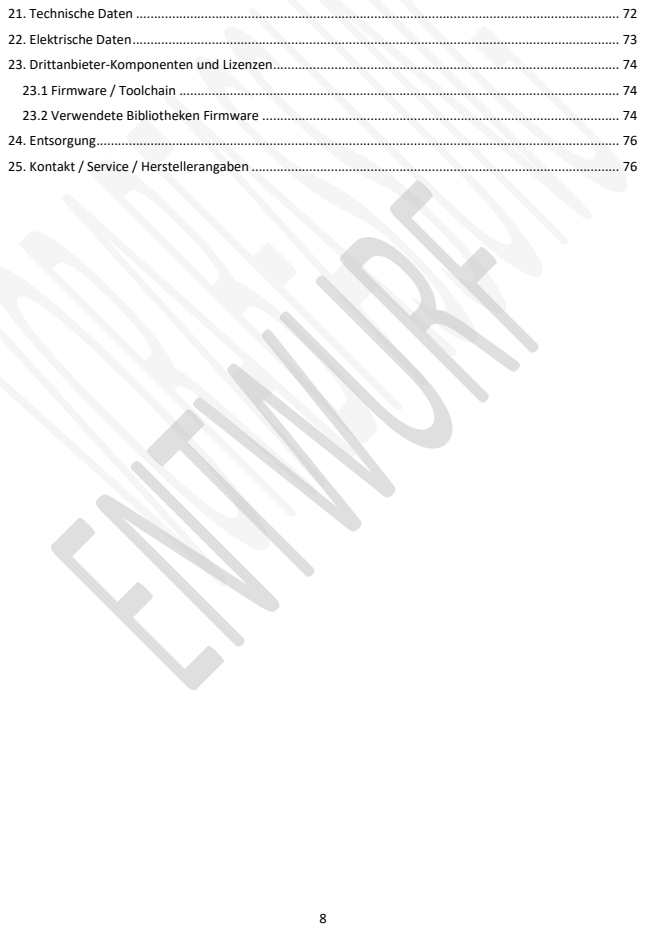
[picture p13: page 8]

21. Technische Daten ...................................................................................................................................... 72
22. Elektrische Daten....................................................................................................................................... 73
23. Drittanbieter-Komponenten und Lizenzen................................................................................................ 74
23.1 Firmware / Toolchain .......................................................................................................................... 74
23.2 Verwendete Bibliotheken Firmware ................................................................................................... 74
24. Entsorgung................................................................................................................................................. 76
25. Kontakt / Service / Herstellerangaben ...................................................................................................... 76

### 1. Über dieses Dokument

Diese Bedienungsanleitung beschreibt die sichere Inbetriebnahme, Bedienung und bestimmungsgemäße Verwendung des SVA-Fencing-Testers. Im Mittelpunkt steht die Bedienung direkt am Gerät. Zusätzlich wird beschrieben, wie das Gerät über eine Weboberfläche im Browser auf dem Smartphone, Tablet oder Computer angezeigt und bedient werden kann.

Zielgruppe:
- Anwender im Bereich Fechtsport, Service, Wartung und Prüftechnik
- Personen, die im Verein Leitungen (Körperkabel, Maskenkabel, Rollen), Waffen oder Westen prüfen.

### 1.1 Rechtlicher und organisatorischer Hinweis

Der SVA-Fencing-Tester ist ein privat und ehrenamtlich entwickeltes Projekt zur gezielten Unterstützung des Fechtsports. Die Bereitstellung und Weitergabe erfolgen vollständig auf Non-Profit-Basis und ohne Gewinnerzielungsabsicht, um Vereinen eine erschwingliche und hochpräzise Materialpflege zu ermöglichen.

Hinweise zum Urheberrecht und Eigentumsschutz:

- Die integrierte Firmware sowie die gerätespezifische Webapp sind geistiges Eigentum des Entwicklers und strikt Closed-Source.
- Jede Form der unbefugten Vervielfältigung, Modifikation, Dekompilierung (Reverse Engineering) oder des unerlaubten Kopierens der Programmdaten ist ausdrücklich untersagt.
- Das Produkt ist kein industriell seriengefertigtes Messgerät, sondern ein im privaten Ehrenamt entstandenes Werkzeug für die vereinsinterne Praxis.
- Es wird nach bestem Wissen und Gewissen auf Basis jahrelanger praktischer Erfahrungen an der Planche bereitgestellt.
- Die Nutzung des Geräts sowie die daraus abgeleiteten Reparaturentscheidungen erfolgen vollständig eigenverantwortlich durch den Anwender.

### 1.2 Hinweis zu Regelwerken und Grenzwerten

Der Tester unterstützt mit einem nicht am Gerät veränderbaren FIE-Preset die elektrische Materialprüfung anhand der vorgesehenen Prüfparameter. Aktualisierungen des Presets erfolgen kontrolliert über die Webapp; bei aktivem Preset zeigt das Gerät das FIE-Logo. Der Tester ist ein Materialtester, keine Meldeanlage und keine Trefferanzeige. Eine formale Aussage zur FIE-Konformität wird erst nach abgeschlossenem, separat dokumentiertem Nachweis veröffentlicht.

### 1.3 Garantie, Gewährleistung und Haftung

Sofern nicht zwingende gesetzliche Vorschriften etwas anderes verlangen, gilt:
- Es wird keine Garantie für bestimmte Eigenschaften, Verfügbarkeit oder Eignung für einen bestimmten Zweck übernommen.
- Es wird keine darüberhinausgehende Gewährleistungszusage abgegeben.
- Für direkte oder indirekte Schäden, Folgeschäden, Datenverlust, Fehlmessungen oder daraus abgeleitete Entscheidungen wird keine Haftung übernommen, soweit gesetzlich zulässig.

Wichtig:
- Der Anwender bleibt für den sachgerechten Einsatz und die Bewertung der Messergebnisse verantwortlich.
- Das Gerät unterstützt die Prüfung, ersetzt aber nicht die fachliche Beurteilung des Anwenders.

### 1.4 Abkürzungen und Fachbegriffe

Dieses Kapitel erklärt wichtige Begriffe aus dem weiteren Verlauf der Bedienungsanleitung.

### 1.4.1 Wichtige Abkürzungen

- ADC: Analog-to-Digital Converter (Analog-Digital-Wandler; integrierter Schaltkreis zur Umsetzung analoger Messspannungen in digitale Zahlenwerte).
- AP: Abkürzung für Access Point. Das Gerät stellt dabei selbst ein WLAN bereit.
- BMP: einfaches Bilddateiformat, hier genutzt für Bildschirmfotos von Geräteoberfläche.
- BOM: Bill of Materials (Stückliste; Verzeichnis aller elektronischen und mechanischen Bauteile, die für die Bestückung der Platine benötigt werden).
- CRA: Cyber Resilience Act (Europäische Cyberresilienz-Verordnung für Produkte mit digitalen Elementen).
- DHCP: automatische Vergabe der Netzwerkadresse.
- DSO: Daylight Saving Time (Sommerzeit; Status-Flag zur kosmetischen Zeitumstellung im Benutzerinterface, synchronisiert über den Browser).
- DST: automatische Vergabe der Netzwerkadresse.
- EMV: Elektromagnetische Verträglichkeit (Fähigkeit eines Apparates, in seiner elektromagnetischen Umwelt zufriedenstellend zu arbeiten, ohne selbst unzulässige Störungen zu verursachen).
- ESD: Electrostatic Discharge (Elektrostatische Entladung; hochenergetische
Spannungsdurchschläge, die durch Schutzdioden direkt an den Buchsen abgefangen werden).
- FIE: Internationaler Fechtverband.
- FPU: Floating Point Unit (Gleitkommaeinheit; dedizierter mathematischer Co-Prozessor im Hauptchip zur schnellen Berechnung ratiometrischer Messwerte in Echtzeit).
- FRAM: Ferroelectric Random Access Memory (Ferroelektrischer Zufallsspeicher; extrem langlebiger, magnetischer Datenspeicher für verschleißfreie Sicherung der Live-Parameter).
- GND: Ground (Masse; das gemeinsame Bezugspotenzial der elektrischen Schaltung).
- Heap: Dynamischer Speicherbereich (Teil des RAMs, aus dem die Software zur Laufzeit flexibel Speicher für JSON-Objekte, Web-Clients oder temporäre Puffer anfordert).
- IP-Adresse: Zahlenadresse, unter der ein Gerät im Netzwerk erreichbar ist.
- I²C: Inter-Integrated Circuit (Serieller Datenbus zur internen Kommunikation zwischen dem Hauptprozessor, den Messwandlern und der Echtzeituhr).
- JSON: Dateiformat für gespeicherte Einstellungen und Konfigurationen.
- LittleFS: Little File System (Robustes, stromausfallsicheres Dateisystem im internen Speicher; dient zur Verwaltung der geräteunabhängigen Webapp-Dateien).
- mDNS: Aufruf eines Geräts über einen Namen statt über eine Zahlenadresse.
- MUX: Multiplexer (Elektronischer Umschalter, der die lastfreien Messspannungen hochohmig an die Wandlerstufen leitet).
- NOK: Not OK (Nicht in Ordnung; Fehlerzustand bei Grenzwertüberschreitung oder Signalabriss).
- NTP: Network Time Protocol (Netzwerkzeitprotokoll; wird in diesem System aufgrund der bewussten Offline-Architektur nicht verwendet).

- OTA: Firmware-Update über WLAN und Browser, ohne das Gerät zu öffnen.
- PCB: Printed Circuit Board (Leiterplatte / Platine; der mechanische Träger und elektrische Verbinder der elektronischen Bauteile).
- PGA: Programmable Gain Amplifier (Programmierbarer Signalverstärker; sorgt im ADC für die automatische, feinstufige Bereichsanpassung bei kleinsten Spannungen).
- PWM: Pulsweitenmodulation (Digitales Modulationsverfahren; steuert hier die stufenlose Lautstärke des Signalgebers sowie die Helligkeit des Bildschirms).
- PSRAM: Pseudo-Static Random Access Memory (Pseudostatischer Arbeitsspeicher; externer, über die SPI-Schnittstelle angebundener RAM-Speicher zur Bereitstellung des großen Display-Framebuffers).
- RAM: Random Access Memory (Flüchtiger Arbeitsspeicher; schneller Hauptspeicher des Mikrocontrollers für Programmdaten und Variablen, aufgeteilt in schnellen internen SRAM und externen PSRAM).
- RED: Radio Equipment Directive (Europäische Funkanlagenrichtlinie 2014/53/EU; regelt die Marktzulassung von Funkkomponenten).
- REST-API: Representational State Transfer Application Programming Interface (Schlanke Programmierschnittstelle; der einzige offene Netzwerk-Port zur sicheren Datenkommunikation).
- RTC: Real-Time Clock (Echtzeituhr; autarker, batteriegepufferter Uhrenbaustein zur exakten Zeithaltung).
- SPI: Serial Peripheral Interface (Serielle Peripherieschnittstelle; schneller, synchroner Datenbus zur hardwarenahen Ansteuerung des TFT-Displays und des PSRAMs).
- SPS: Samples Per Second (Messwerte pro Sekunde; Maßeinheit für die Abtastgeschwindigkeit der analogen Messstufen).
- SPIFFS: SPI Flash File System (Separiertes, geschütztes Dateisystem für benutzerdefinierte Konfigurationsdateien, Presets und Logos).
- SVG: Scalable Vector Graphics (Skalierbare Vektorgrafik; zweidimensionales Grafikformat zur gestochen scharfen, verlustfreien Darstellung der Messkurven auf dem Client-Bildschirm).
- TFT: Thin-Film Transistor (Flachbildschirmtechnologie; bezeichnet das integrierte 2,8"-Farbdisplay mit Touch-Funktion).
- THT: Through-Hole Technology (Durchsteckmontage; robuste Bauform für mechanisch stark beanspruchte Bauteile wie Stecker und Signalgeber).
- TVS: Transient Voltage Suppressor (Halbleiter-Schutzdiode zur schnellen Begrenzung gefährlicher Überspannungsspitzen).
- UX: User Experience (Benutzererfahrung bei der Bedienung des Geräts).
- UI: Benutzeroberfläche, also die sichtbare Bedienoberfläche am Gerät oder im Browser.
- WLAN: drahtlose Netzwerkverbindung.

### 1.4.2 Wichtige Fachbegriffe

- Browser-Oberfläche oder Web-App: zusätzliche Anzeige- und Bedienoberfläche, die im Browser auf Handy, Tablet oder Computer geöffnet wird.
- Client Mode: Das Gerät verbindet sich mit einem bereits vorhandenen WLAN.
- Access Point Mode: Das Gerät stellt selbst ein eigenes WLAN bereit.
- Start: Bezeichnung der Startseite in der Geräte-UI.
- Durchgang: gewollte elektrische Verbindung.
- Isolation: Trennung zwischen Leitungen, die nicht miteinander verbunden sein sollen.
- Grenzwert: eingestellte Grenze, ab der ein Wert als kritisch bewertet wird.
- Warnbereich: Bereich vor der Fehlergrenze.
- Hold Mode: Anzeige bleibt kurz sichtbar, auch wenn der Zustand schon wieder verschwunden ist.
- Fading: kurzes Ausblenden einer zuvor sichtbaren Anzeige.
- Plot, Chart, Diagramm: grafische Darstellung eines Messwerts oder Messverlaufs. Im Manual wird häufig Chart für die Verlaufsanzeige verwendet.
- Trigger: Schalt- oder Auslösepunkt eines Kontakts.
- Prellen: mehrfaches kurzes Umschalten eines Kontakts statt eines sauberen einmaligen Schaltvorgangs.
- Werkseinstellungen: Rücksetzen gespeicherter Einstellungen.
- Neustart: manueller Neustart des Geräts.

### 1.5 Über den Tester, das Projekt und den SVA

Der SVA-Fencing-Tester wurde als möglichst günstiges und einfach zu bedienendes Gerät zum Prüfen von Kabeln, Waffen und weiterer elektrischer Fechtausstattung entwickelt.

### 1.5.1 Entstehung und Ziel

- Ziel des Projekts ist eine praktische Hilfe für Vorbereitung, Wartung, Fehlersuche und vereinsnahe Prüfung im Fechtsport.
- Die Entwicklung, Fertigung, Programmierung und Wartung erfolgen ausschließlich privat und ehrenamtlich nach bestem Wissen und Gewissen.
- Firmware und Webapp sind proprietär und nicht quelloffen. Verwendete Drittanbieter-Komponenten und ihre Lizenzen sind separat dokumentiert.
- Der SVA-Fencing-Tester ist für private oder vereinsinterne Nutzung gedacht.
- Das Gerät ist nicht zertifiziert. Die Nutzung erfolgt eigenverantwortlich.

### 1.5.2 Bug-Reports, Anregungen und Diskussion

- Probleme, Fehlerberichte und Anregungen können per E-Mail gemeldet werden an: info@sva-oranienburg.de
- Für allgemeine Diskussionen steht das öffentliche Projektportal auf GitHub zur Verfügung: https://github.com/MiLasGeek/SVA-Fencing-Tester-Portal/discussions
- Das öffentliche Projektportal ist auf GitHub verfügbar: https://github.com/MiLasGeek/SVA-Fencing-Tester-Portal
- Fehlerberichte und Verbesserungsvorschläge können über den Bug-Report eingereicht werden:

https://github.com/MiLasGeek/SVA-Fencing-Tester-Portal/issues/new/choose

- Sicherheitsrelevante Hinweise bitte nicht öffentlich melden, sondern gemäß Security-Hinweis vertraulich übermitteln:

https://github.com/MiLasGeek/SVA-Fencing-Tester-Portal/blob/main/SECURITY.md

- Compliance-Dokumentation befindet sich in Vorbereitung. Freigegebene Nachweise und der aktuelle Status werden im öffentlichen Projektportal veröffentlicht:

https://github.com/MiLasGeek/SVA-Fencing-Tester-Portal/tree/main/docs/compliance

### 1.5.3 Über den SVA

- SVA-Oranienburg ist der Vereinsbezug des Projekts.
- Der SV Athletik Oranienburg ist ein Breitensportverein.
- Der SVA-Fencing-Tester ist im Umfeld der Abteilung Fechten entstanden.
- Informationen zum Verein sind verfügbar unter:
https://sva-oranienburg.de

Hinweis:
- Die Inhalte der Seite Über in der Browser-Oberfläche fassen diese Hintergrundinformationen ebenfalls zusammen und verweisen zusätzlich auf Dokumentation, Lizenz und weitere Projektinformationen.

### 2. Allgemeine Gerätebeschreibung

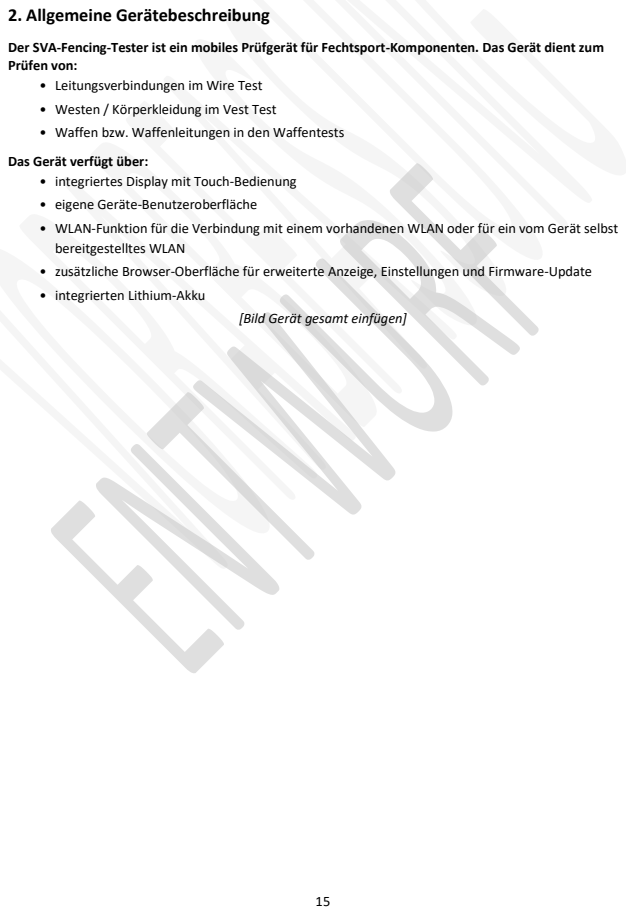
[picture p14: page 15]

Der SVA-Fencing-Tester ist ein mobiles Prüfgerät für Fechtsport-Komponenten. Das Gerät dient zum
Prüfen von:
• Leitungsverbindungen im Wire Test
• Westen / Körperkleidung im Vest Test
• Waffen bzw. Waffenleitungen in den Waffentests

Das Gerät verfügt über:
• integriertes Display mit Touch-Bedienung
• eigene Geräte-Benutzeroberfläche
• WLAN-Funktion für die Verbindung mit einem vorhandenen WLAN oder für ein vom Gerät selbst
bereitgestelltes WLAN
• zusätzliche Browser-Oberfläche für erweiterte Anzeige, Einstellungen und Firmware-Update
• integrierten Lithium-Akku

[Bild Gerät gesamt einfügen]

### 3. Bestimmungsgemäßer Gebrauch

Das Gerät ist ausschließlich für das Messen und Beurteilen von Fechtsport-bezogenen Verbindungen, Widerständen und Isolationen vorgesehen.

### 3.1 Zulässige Verwendungen

- Prüfen von Wire-Verbindungen
- Prüfen von Westen / leitfähiger Bekleidung
- Prüfen von Säbel-, Florett- und Degen-Komponenten bzw. deren Leitungswegen
- Parametrieren und Auswerten über die integrierte Bedienoberfläche oder die Web-App

### 3.2 Nicht zulässige Verwendungen

- Anschluss an Fremdspannungen
- Anschluss an Netzspannung
- Einsatz als allgemeines Multimeter oder Laborgerät
- Betrieb in explosionsgefährdeten Umgebungen
- Betrieb mit beschädigtem Gehäuse, Akku oder Anschlussleitungen
- Einsatz in sicherheitskritischen Anwendungen, in denen Fehlmessungen Personen oder Sachwerte gefährden können

### 3.3 Einschränkungen und Verantwortung des Anwenders

- Das Gerät ist kein zertifiziertes Sicherheitsgerät.
- Sofern nicht separat dokumentiert, besteht keine formale Kalibrier- oder Konformitätszusage.
- Messergebnisse sind stets im Kontext des Prüflings und der aktuellen Parametrierung zu bewerten.
- Vor jeder Freigabe eines Prüflings ist eine Plausibilitätsprüfung durch den Anwender sinnvoll.

### 4. Sicherheit und Warnhinweise

### 4.1 Allgemeine Sicherheitshinweise

- Das Gerät nur bestimmungsgemäß verwenden.
- Das Gerät vor jeder Benutzung auf sichtbare Beschädigungen prüfen.
- Beschädigte Geräte oder Leitungen nicht weiterverwenden.
- Das Gerät nicht öffnen, sofern dies nicht ausdrücklich für Servicezwecke vorgesehen ist.

### 4.2 Warnhinweis elektrische Sicherheit

Warnung:
- Keine Fremdspannung an die Anschlüsse anlegen.
- Das Gerät ist nicht zum Messen externer Spannungsquellen bestimmt.
- Das Anlegen unzulässiger Spannungen kann zu elektrischem Schlag, Beschädigung des Geräts oder Brand führen.

### 4.3 Warnhinweis Brandgefahr / Überhitzung / Beschädigung

- Das Gerät nicht in der Nähe von Wärmequellen betreiben oder lagern.
- Keine öffentlichen oder verdeckten Lüftungs- bzw. Wärmeabgabebereiche blockieren.
- Das Gerät während des Ladevorgangs nicht abdecken.
- Nur freigegebene oder geeignete Lade- und Versorgungskomponenten verwenden.

### 4.4 Warnhinweis Lithium-Akku

Das Gerät enthält einen 3.7V / 1800mAh Lithium-Polymer-Akku.

Hinweise:

- Allgemein: Akku nicht öffnen, zerlegen, quetschen oder verbrennen.
- Sicherheit: Gerät nicht weiterbetreiben, wenn sich der Akku aufbläht, ungewöhnlich warm wird oder mechanisch beschädigt ist.
- Laden: Das Gerät nicht unbeaufsichtigt in ungeeigneter Umgebung laden. Laden Sie den Akku niemals bei Umgebungstemperaturen unter 0 Grad C oder über 45 Grad C.
- Langzeitlagerung: Bei längerer Nichtbenutzung sollte der Akku idealerweise bei einem Ladestand von ca. 40–60 % gelagert werden. Um eine schädliche Tiefentladung zu vermeiden, sollte das Gerät spätestens alle 6 Monate kurz nachgeladen werden.
- Transport und Entsorgung: Die lokalen Vorschriften für Transport, Lagerung und Entsorgung von Lithium-Akkus beachten.
- Kurzschlussschutz: Halten Sie das Gerät fern von leitenden Flüssigkeiten oder Metallgegenständen, die die internen Kontakte überbrücken könnten.

### 4.5 Umgebungsbedingungen

- Gerät vor Feuchtigkeit, Kondenswasser und direktem Regen schützen.
- Nur innerhalb der zulässigen Temperaturbereiche betreiben.
- Starke mechanische Belastungen, Stürze und Schlagbeanspruchung vermeiden.
- Temperaturbereiche:
- Betrieb (Ladebetrieb): 0 Grad C bis +45 Grad C (begrenzt durch Akku-Sicherheit).
- Betrieb (reiner Entladebetrieb): -10 Grad C bis +60 Grad C (begrenzt durch Display-Spezifikation).
- Lagerung: -20 Grad C bis +50 Grad C (empfohlen: +15 Grad C bis +25 Grad C bei ca. 50 % Akkuladung).
- Schutz vor Strahlung: Setzen Sie das Gerät keiner dauerhaften direkten Sonneneinstrahlung aus. Die UV-Strahlung und die damit verbundene thermische Belastung können das TFT-Display dauerhaft schädigen (Kontrastverlust/Verfärbung) und den Akku überhitzen.
- Feuchtigkeit und Kondensation: Das Gerät ist vor Feuchtigkeit, Spritzwasser und Regen zu schützen. Der Betrieb ist nur in nicht-kondensierender Umgebung zulässig. Bei starken Temperaturwechseln (z. B. Transport aus der Kälte in warme Räume) muss das Gerät vor der Inbetriebnahme die Umgebungstemperatur annehmen, um Kurzschlüsse durch Kondenswasser zu vermeiden.
- Mechanische Einflüsse: Vermeiden Sie starke mechanische Belastungen, Stürze sowie Schlagbeanspruchungen, da diese insbesondere das Glas des TFT-Displays oder das Gehäuse des Lithium-Akkus beschädigen können.

### 4.6 Service und Eingriffe am Gerät

- Reparaturen, Umbauten oder Eingriffe im Inneren nur durch geeignete und eingewiesene Personen durchführen.
- Bei unsachgemäßen Eingriffen können Sicherheits- und Schutzfunktionen beeinträchtigt werden.
- Nach Gehäuseöffnung oder Reparatur sollte das Gerät vor dem weiteren Einsatz erneut geprüft werden.

### 4.7 Netzwerk- und Softwarehinweise

- Für die Verfügbarkeit von WLAN, Browsern, Endgeräten oder Netzwerkinfrastruktur kann keine Gewähr übernommen werden.
- Die Bedienung über Browser auf Handy, Tablet oder Computer ist eine Zusatzfunktion und keine Voraussetzung für die Grundbedienung am Gerät.
- Nach Firmware-Updates oder Konfigurationsänderungen kann ein erneutes Laden der Browser-Seite erforderlich sein.
- Das Firmware-Update über diese Browser-Oberfläche ist nur nach vorheriger Anmeldung zulässig.
- Der Updateweg für Firmware-Dateien ist ausschließlich für das vorgesehene Updateformat bestimmt.
- Ungeeignete oder unbefugte Updateversuche können zu Funktionsstörungen oder Beschädigungen führen.

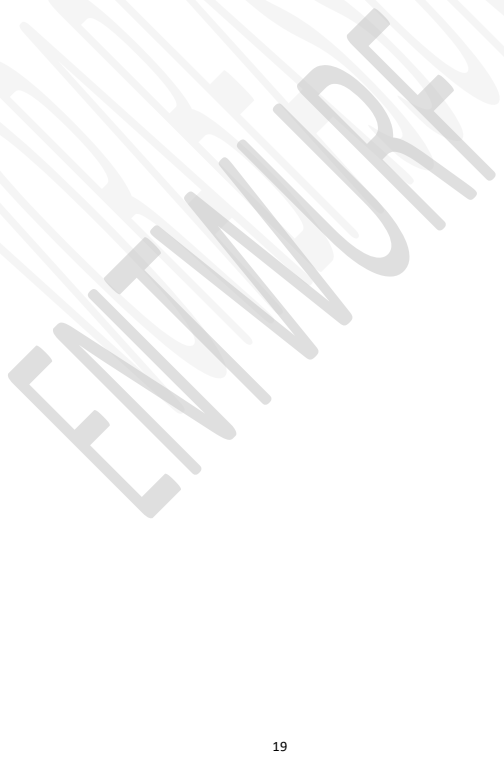
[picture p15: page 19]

### 5. Lieferumfang

- SVA-Fencing-Tester

Optionales Zubehör:
- Vesten-Prüfstift
- Erweiterung für die zweite Vest-Test-Variante
- Prüfkabel mit 4 mm-Stecker und Prüfspitze
Dieses Zubehör ist für Prüfungen über die Zusatzbuchse p erforderlich.
- Adapter 3-polig Stecker / 3-polig Stecker für die Rollenprüfung
Für die Rollenprüfung werden zwei dieser Adapter benötigt.
- Alternativ können für die Rollenprüfung auch zwei intakte Degen-Körperkabel verwendet werden.

Nicht im Lieferumfang:
- USB-C-Ladeadapter
- USB-C-Ladekabel

Hinweis zum Laden:
- Das Gerät ist mit handelsüblichem USB-C-Ladezubehör kompatibel.
- Besondere Anforderungen an das Ladezubehör bestehen nicht.
- Eine 5 V-Versorgung mit mindestens 400 mA ist ausreichend und wird durch übliches Zubehör in der Regel erfüllt.
- Bei gleichzeitigem Betrieb des Gerätes sind mindestens 1A Stromabgabe empfehlenswert.
- Den Akku nicht bei sehr niedrigen oder hohen Temperaturen laden.

### 6 Fechtausstattung und elektrischer Aufbau

Dieses Kapitel dient als kurze Einordnung der typischen elektrischen Fechtausstattung, die mit dem SVA-Fencing-Tester geprüft werden kann.

Hinweis:
- Die genaue Ausführung einzelner Komponenten kann je nach Hersteller, Verband, Altersklasse und Einsatzbereich abweichen.
- Für die verbindliche sportliche Bewertung gelten die jeweils maßgeblichen Regelwerke und Prüfvorschriften.

### 6.1 Körperkabel und Rollen

### 6.1.1 Maskenkabel

- Das Maskenkabel stellt die elektrische Verbindung zur leitfähigen Maske her.
- An beiden Enden befindet sich eine Krokodilklemme.
- Es wird vor allem im Zusammenhang mit Florett- und Säbelausstattung relevant.
- Typische Fehler sind Unterbrechungen, Wackelkontakte und beschädigte Isolation.

### 6.1.2 Körperkabel Florett

- Das Florett-Körperkabel verbindet Waffe und E-Veste mit der Rolle.
- Auf der einen Seite befindet sich ein dreipoliger Stecker mit 4mm Stiften. auf der anderen Seite ein zweipoliger Stecker mit 4mm und 3mm Stift plus mechanischer Verriegelung am Florett, sowie eine Krokodilklemme zur E-Weste.
- Relevante Fehlerbilder sind vertauschte Leitungen, Übergangswiderstände, Wackelkontakte und Kurzschlüsse zwischen eigentlich getrennten Adern.

### 6.1.3 Körperkabel Degen

- Das Degen-Körperkabel verbindet Waffe und Rolle.
- An beiden Seiten befindet sich ein dreipoliger Stecker mit 4mm Stiften.
- Für die Prüfung sind besonders stabile Durchgänge und saubere Isolation zwischen den Adern wichtig.

### 6.1.4 Körperkabel Säbel

- Das Säbel-Körperkabel überträgt die relevanten Signale zwischen Waffe, Rolle und leitfähiger Bekleidung.
- Auf der einen Seite befindet sich ein dreipoliger Stecker mit 4mm Stiften. auf der anderen Seite ein zweipoliger Stecker mit 4mm und 3mm Stift plus mechanischer Verriegelung am Florett, sowie eine Krokodilklemme zur E-Weste.
- Neben Unterbrechungen sind hier auch fehlerhafte Querverbindungen und mechanisch belastete Steckerhäuser typische Fehlerquellen.

### 6.1.5 Rolle

- Die Rolle dient als bewegliche Verbindungsstrecke zwischen Fechter und Anlage.
- Durch die mechanische Beanspruchung sind Kabelbruch, Wackelkontakt und wechselnde Übergangswiderstände besonders häufig.
- Deshalb ist die zeitliche Beobachtung im Chart hier besonders hilfreich.

### 6.2 Waffen: Säbel, Degen und Florett

### 6.2.1 Säbel

- Beim Säbel sind leitfähige Waffe und Zielsystem relevant.
- Typisch geprüft werden Leitungsverbindungen, unerwünschte Querverbindungen und die elektrische Einbindung in die restliche Ausrüstung.
- Zusätzlich sind über die Zusatzleitung p weitere ergänzende Prüfungen möglich.
- Dabei lässt sich auch beurteilen, ob die Klinge elektrisch gut durchgängig ist und ob durch Oxidation oder schlechte Kontaktstellen ein erhöhter Übergangswiderstand entsteht.

### 6.2.2 Florett

- Beim Florett spielt neben der Leitungsprüfung besonders die Spitze mit ihrer Kontaktauslösung eine Rolle.
- Zusätzlich sind die Verbindungen zur leitfähigen Weste und zur Maske relevant.
- Auch hier sind über die Zusatzleitung p weitere ergänzende Prüfungen möglich.
- Typisch geprüft werden die richtige Verdrahtung des Kontakts an der Spitze sowie der elektrische Kontakt der Spitze selbst.

### 6.2.3 Degen

- Beim Degen ist die Spitzenauslösung ein zentrales Prüfmerkmal.
- Neben Leitungs- und Isolationsprüfung ist deshalb auch die Beobachtung von Schaltverhalten, Prellen und Triggerpunkt wichtig.
- Zusätzlich sind über die Zusatzleitung p weitere ergänzende Prüfungen möglich.
- Typisch geprüft werden der Kontakt der Spitze sowie die richtige Verdrahtung zur Glocke.

### 6.3 Spitze bei Degen und Florett

### 6.3.1 Florettspitze

- Die Florettspitze muss sicher und reproduzierbar auslösen.
- Typische Fehler sind verschmutzte Kontakte, mechanisches Klemmen, Prellen oder eine zu schwache Feder.
- Für die sportliche Funktionsprüfung wird üblicherweise auch mit Prüfgewicht gearbeitet.
- Als typische Mindestkraft wird beim Florett 500 g genannt.

### 6.3.2 Degenspitze

- Die Degenspitze muss ebenfalls sicher und reproduzierbar auslösen.
- Neben einer ausreichenden Federkraft ist hier auch der korrekte Auslöseweg wichtig.
- Typische Fehler sind Prellen, unruhiger Umschaltpunkt, mechanisch schwergängige Spitze oder eine zu schwache Feder.
- Als typische Mindestkraft wird beim Degen 750 g genannt.
- Zusätzlich ist beim Degen die Einhaltung des vorgesehenen Auslösewegs wichtig.

### 6.4 Prüfgewicht und typische Fehler

- Ein Prüfgewicht dient dazu, die notwendige Mindestkraft für die Kontaktauslösung zu kontrollieren.
- Löst die Spitze bereits unterhalb der geforderten Kraft aus, ist die Feder möglicherweise zu schwach oder die Mechanik fehlerhaft eingestellt.
- Löst die Spitze trotz ausreichender Kraft nicht sauber aus, sind Verschmutzung, falscher Hub, schwergängige Mechanik oder Kontaktprobleme möglich.

### 6.5 Elektrische Weste

### 6.5.1 Elektrische Weste

- Die elektrische Weste stellt eine großflächige leitfähige Zielzone dar.
- Geprüft werden vor allem Leitfähigkeit, Übergangswiderstand und die Stabilität der Kontaktierung.
- Typische Fehler sind lokale Unterbrechungen, verschlissene Anschlussstellen, starke Widerstandserhöhung und ungleichmäßige Kontaktierung.
- Für die Prüfung sind zwei Varianten möglich.
- Variante 1: Anschluss an zwei beliebig gewählten Prüfpunkten der Weste.
- Variante 2: separater Vest-Anschluss mit zusätzlicher Farbanzeige und optionaler Vibrationsrückmeldung gemäß Konfiguration.

### 6.5.2 Prüfstift für elektrische Westen

- Für elektrische Westen wird in der Praxis auch mit einem Prüfstift gearbeitet.
- Dieser dient dazu, die leitfähige Fläche unter definierten Bedingungen zu prüfen.
- Als typische genormte Prüfkraft werden hier 500 g verwendet.
- Eine Weste kann dabei lokal unauffällig erscheinen, an anderer Stelle aber bereits deutliche Kontaktprobleme zeigen.

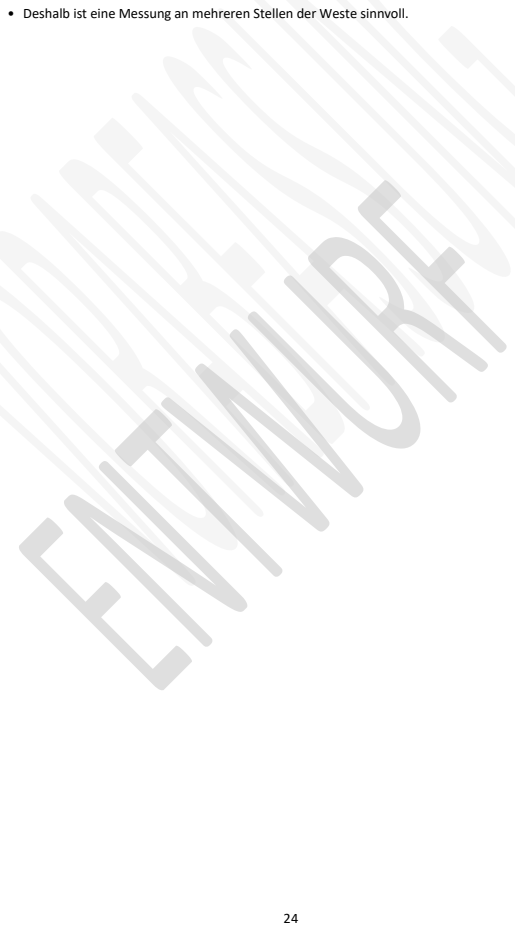
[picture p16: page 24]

• Deshalb ist eine Messung an mehreren Stellen der Weste sinnvoll.

### 7. Hinweis zu Normen und Grenzwerten

### 7.1 Hinweis zu FIE-Grenzwerten

- Für Fechtausstattung können je nach Einsatzbereich sportliche Vorgaben oder Grenzwerte nach Regelwerk relevant sein.
- Dazu können auch Anforderungen der FIE gehören. Das Gerät besitzt keine werkseitige FIE-Zertifizierung oder Konformitätserklärung.
- Eine technische Messung mit dem Gerät ersetzt nicht die formale Freigabe nach sportlichem Regelwerk.

### 7.2 Orientierung an typischen FIE-Vorgaben

- Bei Florett wird üblicherweise mit einer Mindestkraft von 500 g geprüft.
- Bei Degen wird üblicherweise mit einer Mindestkraft von 750 g geprüft.
- Als grobe Orientierung aus den FIE-Materialregeln gelten für den elektrischen Widerstand typischerweise maximal 2 Ω bei Florett und Degen sowie maximal 1 Ω bei Säbel.

### 7.3 Was das Gerät prüft

- Das Gerät prüft elektrische Durchgänge, Isolation, Übergangswiderstände, Kontaktverhalten und instabile Verbindungen.
- Es unterstützt Vorbereitung, Wartung, Fehlersuche und Vorprüfung der Fechtausstattung.
- Grenzwerte und Parameter müssen zum vorgesehenen Prüfzweck und dem aktuell geltenden Regelwerk passen.

### 7.4 Was das Gerät nicht ersetzt

- Das Gerät ersetzt keine offizielle Waffenabnahme auf Turnieren oder bei einer formalen Materialkontrolle.
- Für die verbindliche sportliche Zulassung sind die aktuelle Regelgrundlage, die offizielle Prüfung und die Entscheidungen der zuständigen Stellen maßgeblich.

### 7.5 Quelle der Orientierungswerte

- Die oben genannten Hinweise orientieren sich an den FIE-Materialregeln, Stand Dezember 2025.
- Maßgeblich ist immer die im Einsatzfall aktuell gültige Fassung des jeweiligen Regelwerks.
- Je nach Wettbewerb, Verband und Einsatzbereich können zusätzlich nationale Regelwerke, Materialvorschriften oder Ausschreibungen maßgeblich sein.
- Für Training, Vereinsbetrieb, nationale Turniere oder Verbandsabnahmen können daher andere oder ergänzende Anforderungen gelten als bei einer reinen Orientierung an der FIE.
- Offizielle FIE-Regelübersicht: https://fie.org/fie/documents/rules
- FIE Material Rules, Stand Dezember 2025: https://static.fie.org/uploads/38/190667-book%20m%20ang.pdf
- Weitere technische und ausrüstungsbezogene FIE-Dokumente: https://fie.org/fie/documents/equipment

### 8. Geräteübersicht und Anschlüsse

Dieser Abschnitt beschreibt die mechanischen und elektrischen Anschlüsse des Geräts.

### 8.1 Allgemeine Eigenschaften

- Das Gerät besitzt einen integrierten Touch-Bildschirm an der Vorderseite.

### 8.2 Vorderseite

- Display mit Touch-Bedienfläche
- Statusanzeigen / Symbole in der UI
- unterer Navigationsbereich für die Hauptseiten
- oberer Statusbereich mit Standby-Anzeige
- unterhalb des Displays die 1er- und 2er-Anschlüsse
- die Anordnung der Messanschlüsse ist an die Anzeige und die Verbindungsmatrix angelehnt

[Bild Vorderseite einfügen]

### 8.3 Rückseite / Seitenansichten

- USB-C-Buchse zum Laden/Betrieb
- Messanschlüsse für Leitungstest, Waffentest und Westentest
- SD-Kartenslot
- Ein-/Aus-Schalter
- vier Ladezustands-LEDs

[Bild Rückseite / Seitenansicht einfügen]

### 8.4 intern nur für Service und Entwicklung

- Service- und Programmieranschlüsse nur für Entwicklung / Service
- interner Reste Button, Boot Button (startet Screenshot zu SD-Karte), interner Button für Stromversorgungsmodul
- Debug-Schnittstelle

### 8.5 Ladezustands-LEDs

- Das Gerät besitzt vier LEDs zur Anzeige des Ladezustands, ähnlich wie bei einer Powerbank.
- Im Ruhezustand können die LEDs aus sein.
- Bei Aktivität zeigen die LEDs den Ladezustand stufenweise an.
- Während des Ladens blinkt die Anzeige entsprechend dem aktuellen Ladestand.

### 8.6 Ruhezustand

- Das Gerät besitzt einen Ein-/Aus-Schalter.
- Zusätzlich arbeitet das Gerät mit einem automatischen Ruhezustand.
- Wenn das Gerät in den Ruhezustand gewechselt hat, muss der Power-Schalter aus- und wieder eingeschaltet werden, um das Gerät erneut zu starten.

### 8.7 SD-Karte

- Das Gerät besitzt einen SD-Kartenslot.
- Screenshots können auf die SD-Karte geschrieben werden.
- Später können möglicherweise weitere Funktionen wie zusätzliche Update- oder Serviceabläufe über die SD-Karte ergänzt werden.

### 8.8 Messanschlüsse

### 8.8.1 Messkanäle

Die Firmware arbeitet intern mit acht Messkanälen:
- a1, b1, c1 (Kabeltest und Waffentest, kann bei Westentest genutzt werden)
- a2, b2, c2 (Kabeltest, kann bei Westentest genutzt werden)
- p (erweiterter Waffentest, kann bei Westentest genutzt werden)
- v (Westentest bei erweitertem Prüfstift)

### 8.8.2 Bedeutung der internen Kanalgruppen

- a1, b1, c1 und a2, b2, c2 bilden die sechs Hauptmesskanäle für Leitungstest und Waffentest, sowohl zu Durchgangsprüfungen als auch zu Isolationsprüfungen.
- p ist ein zusätzlicher Prüf- bzw. Hilfskanal, der in den Waffentests verwendet wird.
- v ist dem zusätzlichen Prüfstift-Anschluss für den Westen-Test zugeordnet und ist für die normale Benutzerbedienung nicht weiter relevant.
- Für den Westentest mit dem einfachen Prüfstift können zwei frei wählbare Anschlüsse genutzt werden.

### 8.8.3 Physischer Aufbau der Anschlüsse

- a1: eine 4 mm-Buchse
- b1: eine 4 mm-Buchse
- c1: eine 4 mm-Buchse und zusätzlich ein Terminal für eine Klemme
- a1, b1 und c1 sind so angeordnet, dass ein 3-poliger Stecker passt
- a2: zwei 4 mm-Buchsen
- b2: eine 4 mm-Buchse und eine 3 mm-Buchse
- c2: eine 4 mm-Buchse und zusätzlich ein Terminal für eine Klemme
- a2, b2 und c2 sind so angeordnet, dass entweder ein 3-poliger Stecker oder ein 2-poliger Waffenstecker mit Aussparung für die mechanische Verriegelung passt
- p: separate 4 mm-Buchse

### 8.8.4 Benutzerorientierte Zuordnung nach Messfunktion

- Wire Test: nutzt in erster Linie die drei Kanalpaare a1-a2, b1-b2 und c1-c2.
- Sabre Test: nutzt die Kanäle a1, b1, c1, c2 sowie den Zusatzkanal p.
- Foil Test: nutzt die Kanäle a1, b1, c1, c2 sowie den Zusatzkanal p.
- Epee Test: nutzt die Kanäle a1, b1, c1 sowie den Zusatzkanal p.
- Vest Test: prüft die Verbindung mit mehreren möglichen Kanalpaaren und kann dadurch unterschiedliche Anschlussbilder erkennen.

### 8.8.5 Praktische Anschlussregel

- Generell wird das Kabel an die 1er-Seite angeschlossen.
- Bei Waffentests erfolgt der Anschluss des Prüflings bzw. der Waffe auf der Gegenseite passend zum Testaufbau.
- Bei Kabeltests erfolgt der Gegenanschluss auf der 2er-Seite.

### 8.8.6 Typische Anschlussbilder

- Maskenkabel: Prüfung an den beiden c-Terminals, also zwischen c1 und c2
- Körperkabel 3-polig auf 3-polig: Anschluss auf 1er-Seite zu 2er-Seite
- Körperkabel 3-polig auf 2-polig: Anschluss 3-polig auf der einen Seite und 2-polig auf der anderen Seite; für die Westenverbindung wird zusätzlich das c2-Terminal mit Klemme verwendet

### 8.8.7 Zuordnung im Wire Test

- a1-a2, b1-b2, c1-c2 werden als eigentliche Leitungsverbindungen bewertet.
- Zwischen denselben Kanälen sowie zwischen gemischten Paaren werden zusätzlich Isolations- und Fehlverbindungen geprüft.
- Im erweiterten Drahttest können einzelne Kanäle oder gültige Kanalpaare gezielt ausgewählt werden.

### 8.8.8 Zuordnung in den Waffentests

- Sabre bewertet primär eine Hauptverbindung zwischen a1-b1, eine weitere Leitungsverbindung auf c1-c2 sowie Isolationen gegen andere Kanäle.
- Foil bewertet primär die Hauptverbindung a1-b1, die Leitungsverbindung c1-c2, mehrere Isolationspfade und den Zusatzkanal p.
- Epee bewertet primär die Hauptverbindung b1-c1, zusätzliche Isolationspfade sowie den Zusatzkanal p.
- Bei Foil und Epee existiert zusätzlich ein Trigger-Untermodus für die Auslösebetrachtung.

### 8.8.9 Zuordnung im Vest Test

- Der Vest-Test versucht nicht nur ein einziges festes Kanalpaar, sondern prüft mehrere mögliche Kombinationen.
- Dadurch kann die Firmware verschiedene gültige Anschlussvarianten erkennen.
- Bevorzugt werden Verbindungen über v-p, danach folgen weitere Kombinationen unter Einbeziehung von c1, c2, a1, b1, a2, b2 und p.

### 9. Stromversorgung

### 9.1 Allgemeines

- Die Stromversorgung kann über einen internen Lithium Akku erfolgen.
- Die Akkulaufzeit beträgt ca. 3 bis 4 Stunden und kann je nach Messaufgabe variieren. Der Betrieb mit aktivem WLAN kann die Akkulaufzeit je nach Nutzung und Empfangssituation auch deutlich verringern.
- Das Laden des internen Akkus erfolgt über eine USB-C-Buchse, die Ladezeit beträgt dabei bis zu 5 Stunden, 15 bis 80% in ca. 3 Stunden.
- Die Aufladung des internen Akkus erfolgt auch im Schalterzustand Aus.
- Über die USB-C Buchse kann das Gerät sowohl geladen als auch betrieben werden.
- Die USB-C-Buchse dient nur der 5V Versorgung zum Laden. Die Stromaufnahme des Gerätes bis zu 600mA Betrieb (Spitzenwert mit aktivem WLAN) und 400mA beim Laden.
- Wird die USB-Versorgung abgeschaltet, geht das Gerät kurz aus und startet anschließend neu, intern wird von externer Versorgung mit Akku Laden auf interne Versorgung gewechselt.
- USB-C Spezification: 5V / 1A
- Es besteht kein Support für USB-Datenübertragung.
- USB Power Delivery wird nicht unterstützt.
- Es kann kein anderes Gerät mit Strom versorgt werden.

### 9.2 Laden

[Ladeanschluss und zulässige Ladespezifikation ergänzen]

Hinweise:
- Nur mit geeigneter Stromquelle laden.
- Ladegerät und Kabel auf Beschädigungen prüfen.
- Ladegeräte die an das Stromnetz angeschlossen werden, z.B. über Steckdose, müssen Schutzisoliert sein.
- USB-C Versorgung wird nur mit 5V unterstützt, Power Delivery mit mehr als 5V kann das Gerät beschädigen oder zu Überhitzung und Brand führen.
- Bei ungewöhnlicher Erwärmung den Ladevorgang sofort abbrechen.
- Integrierter Lithium-Akku 3.7V/1800mAh.
- Maximaler Ladestrom ca. 400 mA.
- Das Gerät kann nicht als Stromversorgung für andere Geräte genutzt werden.

### 9.3 Akkubetrieb

- Akkustand vor langen Messreihen prüfen.
- Bei niedrigem Akkustand kann die Messdauer eingeschränkt sein.
- Zur Erhöhung der Laufzeit kann eine externe handelsübliche Powerbank genutzt werden.
- Gerät bei längerer Nichtbenutzung gemäß Wartungs- und Lagerhinweisen aufbewahren.

### 9.4 Lagerung und Transport des Akkus

- Das Gerät nicht in heißer Umgebung oder in direkter Sonneneinstrahlung im Fahrzeug lagern.
- Für längere Lagerung ist ein moderater Ladezustand des Akkus sinnvoll.
- Beim Versand oder Transport sind die geltenden Vorschriften für Lithium-Akkus zu beachten.

### 10. Inbetriebnahme

### 10.1 Erstinbetriebnahme

1. Gerät auf äußere Beschädigungen prüfen.
2. Gerät ggf. vollständig laden.
3. Gerät einschalten.
4. Das Gerät zeigt einen Startbildschirm und wechselt zu Grundansicht.
5. Grundfunktionen am Display prüfen.
6. Messanschlüsse immer nur im spannungsfreien und vorgesehenen Zustand verbinden. Niemals Fremdspannung anschließen.

### 10.2 Startverhalten

Nach dem Einschalten startet das Gerät die Firmware, initialisiert Display, Touch, Messlogik und die konfigurierten Schnittstellen.

Typischer Ablauf:
1. Startanzeige mit Gerätename und Logo.
2. Initialisierung der internen Funktionen.
3. Wechsel zur Hauptoberfläche.
4. Anzeige der Startseite mit Uhr.

Hinweise:
- Während eines aktiven Firmware-Updates ist die normale Touch-Bedienung gesperrt.
- WLAN-Funktionen stehen erst nach abgeschlossener Initialisierung und gemäß eingestelltem WLAN-Modus zur Verfügung.
- Nach einem Neustart infolge von OTA, Konfigurationsimport oder Werksreset muss das Gerät erst wieder vollständig hochfahren, bevor Messung und Browser Oberfläche verfügbar sind.

### 11. Geräte-UI und Bedienung

Die Bedienung erfolgt grundsätzlich über das integrierte Display mit Touch-Funktion.

### 11.1 Startbildschirm / Start

- Uhrdarstellung in digitaler oder analoger Form, einfacher Wechsel durch Antippen auf die Uhrzeit
- halb Transparente Standby-Anzeige als Fortschrittsbalken in der Zeile am oberen Bildschirmrand
- direkte Navigation zu allen Hauptmodi über die untere Buttonleiste oder Wischen nach links oder rechts, dabei wird zyklisch entsprechend der Slide Richtung der entsprechende Modus aufgerufen
- Zugang zu den Parametern (Touch auf Schaltfläche, Wischen nach unten auf der linken Bildschirmhälfte)
- Wechsel zur Infoseite (Button, Wischen nach unten auf der rechten Bildschirmhälfte)
- Wechsel zum WLAN (Touch auf WLAN-Symbole in der Zeile am oberen Bildschirmrand)
- schneller Wechsel zur Zeiteinstellung (Wischen nach oben) oder langes Antippen der Uhrzeit

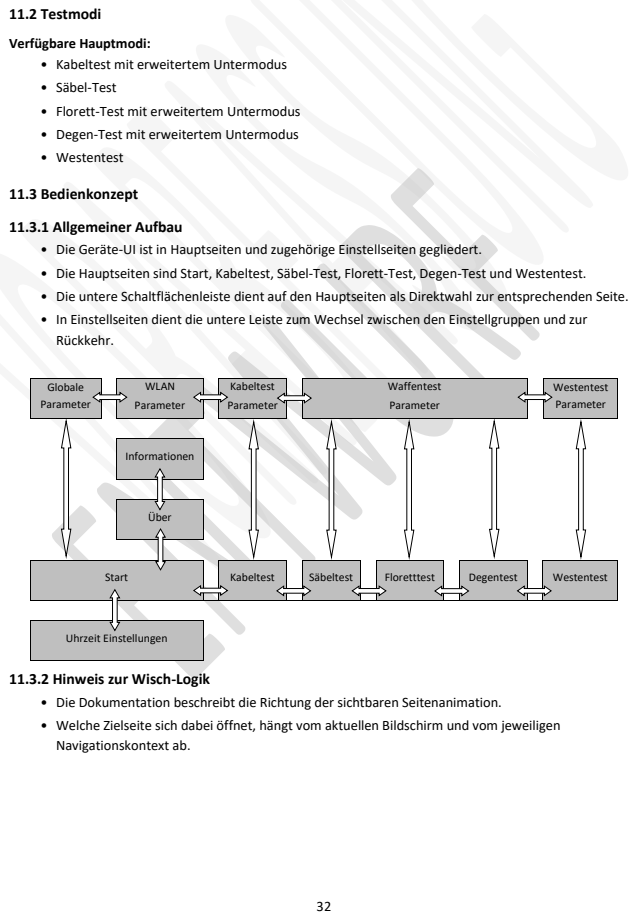
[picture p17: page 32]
11.2 Testmodi; 11.3 Bedienkonzept; Globale Parameter; WLAN; Parameter; Kabeltest; Waffentest; Westentest Parameter; Informationen; Über; Start; Säbeltest; Floretttest; Degentest; Westentest; Uhrzeit Einstellungen

Verfügbare Hauptmodi:
• Kabeltest mit erweitertem Untermodus
• Säbel-Test
• Florett-Test mit erweitertem Untermodus
• Degen-Test mit erweitertem Untermodus
• Westentest

11.3.1 Allgemeiner Aufbau
• Die Geräte-UI ist in Hauptseiten und zugehörige Einstellseiten gegliedert.
• Die Hauptseiten sind Start, Kabeltest, Säbel-Test, Florett-Test, Degen-Test und Westentest.
• Die untere Schaltflächenleiste dient auf den Hauptseiten als Direktwahl zur entsprechenden Seite.
• In Einstellseiten dient die untere Leiste zum Wechsel zwischen den Einstellgruppen und zur
Rückkehr.

11.3.2 Hinweis zur Wisch-Logik
• Die Dokumentation beschreibt die Richtung der sichtbaren Seitenanimation.
• Welche Zielseite sich dabei öffnet, hängt vom aktuellen Bildschirm und vom jeweiligen
Navigationskontext ab.

### 11.3.3 Navigation am Gerät

- Wischen nach links oder Wischen nach rechts wechselt zwischen den Seiten einer Ebene.
- Auf den Hauptseiten wechselt die horizontale Wischgeste zwischen Start, Kabel, Säbel, Florett, Degen und Westen.
- Auf den Einstellseiten wechselt die horizontale Wischgeste zwischen Globale, WLAN, Kabel, Waffen und Westen.
- Wischen nach unten oder oben wechselt vertikal zwischen logisch übereinanderliegenden Seiten.
- Auf der Startseite öffnet Wischen nach unten auf der rechten Bildschirmseite die allgemeinen Parameter oder WLAN, wenn von der obersten Zeile aus gewischt wurde und die Information auf der linken Bildschirmseite.
- Auf der Startseite öffnet Wischen nach oben die Zeiteinstellung.
- Die Wischrichtung beschreibt dabei die sichtbare Animationsrichtung der eingeblendeten Zielseite.
- Entsprechend bedeutet Wischen nach unten, dass die neu geöffnete Seite mit einer Bewegung nach unten eingeblendet wird.
- Gleiches gilt für Wischen nach links oder rechts: Die Zielseite bewegt sich sichtbar in diese Richtung.
- Der Seitenwechsel ist zyklisch aufgebaut. Damit ist auch ein direkter Wechsel vom letzten zum ersten Eintrag bzw. vom ersten zum letzten Eintrag möglich.

### 11.3.4 Schaltflächen und Schnellbereiche

- Die untere Schaltflächenleiste dient als sichtbare Direktnavigation.
- Ein Antippen des aktuell bereits aktiven Modus kann einen Untermodus öffnen oder umschalten.
- Der kleine Bereich oben links bei den WLAN-Symbolen dient als Schnellzugriff auf die WLAN-Seite.
- In den Testseiten öffnet ein langes Antippen der Testseite die passende Einstellseite.

### 11.3.5 Sprachwechsel

- Die Sprache kann direkt am Gerät in den allgemeinen Einstellungen geändert werden.
- Der Sprachwechsel schaltet die UI zyklisch durch die verfügbaren Sprachen.
- Parallel kann die Sprache auch über die Web-App umgestellt und auf das Gerät übernommen werden.

### 11.3.6 Zeitbedienung

- Auf der Startseite kann zwischen analoger und digitaler Uhr umgeschaltet werden.
- Die Zeiteinstellung ist sowohl über die Geräte-UI als auch über die Web-App erreichbar.

### 11.3.7 Abschalt-Indikator am Gerät

- Am oberen Bildschirmrand zeigt ein transparenter horizontaler Balken die verbleibende Zeit bis zum Abschalten (Standby).
- Ist Standby = „Nie“ eingestellt, so ist der Balken nicht sichtbar.
- Ist die Zeit ohne Bedienung oder Prüfung abgelaufen, schaltet sich das Gerät ab.
- Das Gerät wacht danach nicht durch Berührung oder andere Aktivität wieder auf.
- Für den erneuten Betrieb muss das Gerät am Power-Schalter aus- und wieder eingeschaltet werden.

### 12. Messabläufe

### 12.1 Grundlagen zum Verständnis der Messanzeigen

Die folgenden Grundlagen helfen beim Verstehen aller Messmodi. Sie gelten für die Anzeige am Gerät und sinngemäß auch für die Browser Oberfläche.

### 12.1.1 Was sagt der Ohm-Wert aus

- Ohm ist die Einheit für elektrischen Widerstand.
- Ein kleiner Ohm-Wert bedeutet: Strom kann gut fließen, die Verbindung ist leitfähig.
- Ein großer Ohm-Wert bedeutet: Strom kann schlecht oder praktisch gar nicht fließen.
- Für gewollte Verbindungen ist deshalb ein kleiner Wert gut.
- Für unerwünschte Verbindungen ist ein großer Wert gut.
- Ω ist das Symbol für Ohm

### 12.1.2 Ohm, kOhm und was der Wert bedeutet

Ohm und kOhm für technische Laien:
- 1 Ohm oder 1Ω ist ein kleiner Widerstand.
- 1000Ω sind 1 kΩ oder 1kOhm.
- 1000000Ω oder 1000kΩ sind ein MΩ
- Wenn das Gerät bei einem Soll-Durchgang wenige Ω anzeigt, ist das meistens gut.
- Wenn das Gerät bei einer Isolationsmessung sehr große Werte oder Werte im kΩ - bis MΩ-Bereich zeigt, ist das meistens gut.
- Anders gesagt: Bei Durchgang will man klein, bei Isolation will man groß.

### 12.2 Durchgang und Isolation

Der SVA-Fencing-Tester beurteilt Leitungen und Kontakte im Wesentlichen mit zwei Grundaufgaben:
- Durchgangsprüfung: Es wird geprüft, ob zwei Punkte elektrisch verbunden sein sollen und ob diese gewollte Verbindung gut ist.
- Isolationsprüfung: Es wird geprüft, ob zwei Punkte elektrisch gerade nicht verbunden sein sollen und ob trotzdem eine ungewünschte Verbindung besteht.

### 12.2.1 Durchgangsprüfung

- Eine gewollte Verbindung soll möglichst wenig elektrischen Widerstand haben.
- Ein kleiner Widerstandswert ist hier gut.
- Typische Ursachen für zu hohe Werte sind verschmutzte Kontakte, lockere Stecker, gealterte Verbindungen oder ein beginnender Kabelbruch.

### 12.2.2 Isolationsprüfung

- Eine ungewünschte Verbindung soll möglichst hochohmig sein.
- Ein großer Widerstandwert ist hier gut.
- Ein kleiner oder schwankender Wert ist kritisch, weil er auf beschädigte oder durchgescheuerte

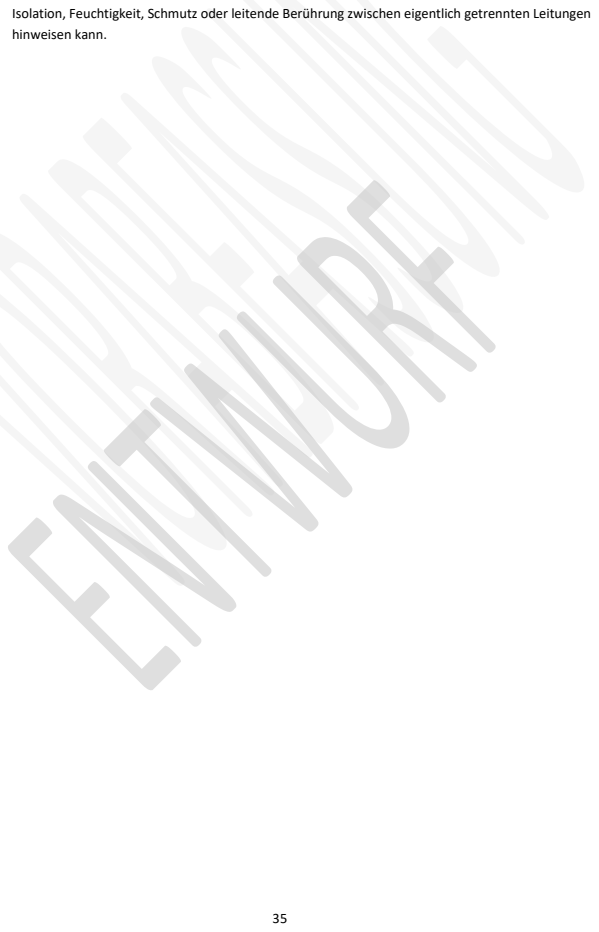
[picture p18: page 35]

Isolation, Feuchtigkeit, Schmutz oder leitende Berührung zwischen eigentlich getrennten Leitungen
hinweisen kann.

### 12.3 Typische Fehlerbilder

- Wackelkontakt: Der Wert springt beim Bewegen des Kabels oder Steckers. Ursache kann ein Kabelbruch, ein loser Kontakt oder ein verschlissener Anschluss sein.
- Beginnender Kabelbruch: Im Ruhezustand scheint die Verbindung noch „Gut“, beim Bewegen steigt der Wert in den Warnbereich oder auf „Schlecht“.
- Lose Verbindung: Der Wert ist nicht dauerhaft schlecht, aber unruhig oder nahe an der Grenzlinie.
- Beschädigte Isolation: Eigentlich getrennte Leitungen zeigen plötzlich kleine oder mittlere Widerstände.
- Sporadische unerwünschte Verbindung: Im Chart tauchen kurze Einbrüche oder Spitzen auf, obwohl die Leitungen normalerweise getrennt sein sollten.

### 12.4 Anzeigeelemente: Balken, Chart und Hilfslinien

### 12.4.1 Wie helfen Balken und Chart allgemein

- Der Balken zeigt den aktuellen Messwert sofort und direkt.
- Das Chart zeigt den Verlauf über die Zeit.
- Der Balken ist gut für den schnellen Blick auf den Momentanwert.
- Das Chart ist gut für das Erkennen von Wackelkontakten, Prellen oder sporadischen Fehlern.

### 12.4.2 Grenzlinie

- Die Grenzlinie zeigt den eingestellten Grenzwert für die Bewertung.
- Bei Durchgang bedeutet die Grenzlinie: oberhalb davon wird die Verbindung kritisch oder „Schlecht“.
- Bei Isolation bedeutet die Grenzlinie: unterhalb davon wird eine unerwünschte Verbindung kritisch oder „Schlecht“.

### 12.4.3 Hold-Linie

- Die Hold-Linie bzw. Hold-Anzeige merkt sich je nach Modus einen auffälligen Extremwert noch kurz.
- Dadurch verschwinden kurze Fehler nicht sofort aus der Anzeige.
- Das hilft besonders bei Wackelkontakten und sporadischen Fehlern.

### 12.4.4 Hilfslinien

- Hilfslinien im Chart erleichtern das Abschätzen der Wertgröße.
- Sie helfen dabei zu sehen, ob ein Wert stabil bleibt oder sich nur kurz verändert.
- Bei Durchgangsmessungen orientieren sich die Hilfslinien an ganzen Ohmwerten.
- Bei Isolationsmessungen orientieren sich die Hilfslinien an Zehnerpotenzen, also z. B. 1, 10, 100, 1000 usw.

### 12.5 Skalierung und Anzeigerichtung

### 12.5.1 Anzeigerichtung

- Bei normalen Durchgangsbalken bedeutet ein weiter ansteigender Wert in Richtung Grenzlinie meist eine Verschlechterung.
- Bei Isolationsmessungen ist die Interpretation umgekehrt: große Werte sind gut, kleine Werte sind kritisch.

### 12.5.2 Lineare und logarithmische Darstellung

- Eine lineare Skala zeigt gleiche Wertabstände immer mit gleichem optischem Abstand.
- Eine logarithmische Skala ist hilfreich, wenn sehr kleine und sehr große Werte gleichzeitig sinnvoll dargestellt werden müssen.
- Bei Durchgang werden Balken und Chart linear dargestellt.
- Bei Isolation werden Balken und Chart logarithmisch dargestellt.

### 12.6 Farbbereiche und schnelle Bewertung

Farbbereiche in der Web-App:
- Die Web-App verwendet zusätzlich farbige Bereiche zur schnellen Orientierung.
- Typisch ist: „Gut“ im guten Bereich, Warnbereich als Vorwarnung und „Schlecht“ im kritischen Bereich.
- Dadurch kann auch ohne exaktes Ablesen schnell erkannt werden, ob ein Wert stabil gut ist oder sich in einen kritischen Bereich bewegt.

### 12.7 Kabeltest

### 12.7.1 Zweck

- Prüfen von Leitungsverbindungen und Isolationen im Leitungsbaum

### 12.7.2 Anschluss

- Den Prüfling so anschließen, dass das Kabel auf der 1er-Seite und der Gegenanschluss auf der 2er-Seite liegt.
- Im regulären Wire Test werden die drei Verbindungspaare a1-a2, b1-b2 und c1-c2 ausgewertet.
- Im Modus Maskenkabel wird nur das Paar c1-c2 bewertet.
- Ein 3-poliges Körperkabel wird typischerweise von 1er-Seite auf 2er-Seite geprüft.
- Bei 3-polig auf 2-polig wird die Gegenseite passend am Waffenstecker aufgenommen; für die Westenverbindung wird zusätzlich das c2-Terminal mit Klemme verwendet.
- Das Maskenkabel wird zwischen den beiden c-Anschlüssen bzw. c-Terminals geprüft.
- Vor dem Start sicherstellen, dass keine Fremdspannung anliegt und alle Kontakte sauber sitzen.

### 12.7.3 Untermodi

- Roll: Prüfung der Rolle / Leitungsrolle mit eigenem Grenzwert und eigenem Plot-Maximum.
- Body: Prüfung der Körperleitung mit den Wire-Grenzwerten für Body/Mask.
- Mask: Prüfung der Maskenleitung mit denselben Grundparametern wie Body.
- Extended Wire Test: Auswahl einzelner Kanäle bzw. Kanalpaare für gezielte Widerstands- oder Isolationsprüfungen.

### 12.7.4 Unterschiede der regulären Untermodi

- Roll und Body prüfen dieselben Grundverbindungen a1-a2, b1-b2 und c1-c2.
- Der Unterschied zwischen Roll und Body liegt in den verwendeten Grenzwerten und im Plot-Maximum.
- Mask ist auf das Maskenkabel reduziert und bewertet nur c1-c2.

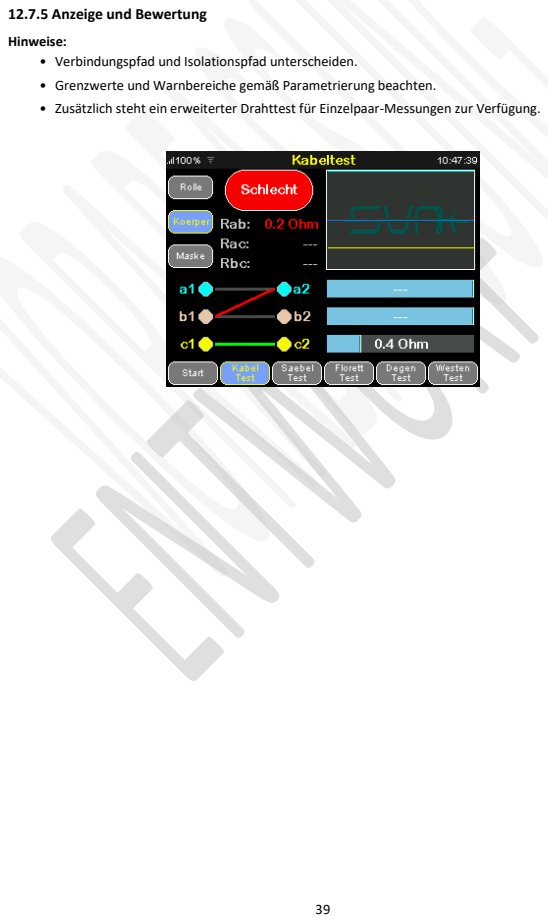
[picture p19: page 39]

12.7.5 Anzeige und Bewertung

Hinweise:
• Verbindungspfad und Isolationspfad unterscheiden.
• Grenzwerte und Warnbereiche gemäß Parametrierung beachten.
• Zusätzlich steht ein erweiterter Drahttest für Einzelpaar-Messungen zur Verfügung.

### 12.7.6 Bedienhinweise zum erweiterten Drahttest

- Einstieg über den aktiven Kabeltest-Modus, über die zugehörige Schaltfläche oder über denselben unteren Modus-Button.
- Im erweiterten Modus werden Kanäle einzeln ausgewählt.
- Bei einem gültigen Paar wird der Widerstand direkt für dieses Paar dargestellt.
- Ein erneutes Verlassen des erweiterten Modus erfolgt über die Rückfläche oder durch Rückgeste.

### 12.7.7 Gezielte Fehlersuche mit dem erweiterten Modus

- Der erweiterte Modus eignet sich für die gezielte Suche nach Einzeldefekten.
- Werden zwei zusammengehörende Leitungsenden ausgewählt, erfolgt eine Durchgangsprüfung.
- Werden zwei nicht zusammengehörende Kanäle ausgewählt, erfolgt eine Isolationsprüfung.
- Damit kann gezielt unterschieden werden, ob ein Problem durch Unterbrechung, Übergangswiderstand oder Kurzschluss / Isolationseinbruch verursacht wird.

### 12.7.8 Anschlussmatrix und Bewertung

- a1-a2, b1-b2, c1-c2 sollen im regulären Wire Test niederohmig sein.
- Verbindungen zwischen nicht zusammengehörenden Leitungen sollen hochohmig bleiben.
- OK bedeutet: Soll-Durchgänge liegen unterhalb des Verbindungsgrenzwerts und unerwünschte Querverbindungen bleiben oberhalb der Isolationsgrenze.
- Warnbereich bedeutet: Ein Wert bewegt sich noch nicht eindeutig in Richtung „Schlecht“, liegt aber bereits im eingestellten Warnfenster.
- „Schlecht“ bedeutet: Ein Soll-Durchgang ist zu hochohmig oder eine unerwünschte Verbindung ist zu niederohmig.
- In der grafischen Matrix werden gute Leitungsverbindungen und fehlerhafte Isolationspfade getrennt dargestellt.
- Die Balkenanzeige zeigt zusätzlich die drei Hauptdurchgänge als Einzelwerte.

### 12.7.9 Was sehe ich im Balken

- Der Balken zeigt den aktuellen Messwert relativ zum eingestellten Plot-Maximum.
- Die Grenzmarke zeigt den jeweils relevanten Connection Threshold.
- Bei einem Durchgang ist ein kleiner Wert gewünscht.
- Bei einer Isolationsmessung ist ein möglichst großer Wert gewünscht.
- Der farbige Verlauf zeigt auf einen Blick, ob sich der aktuelle Messwert im „Gut“ Bereich, im Warnbereich oder in Richtung „Schlecht“ bewegt.

### 12.7.10 Was sehe ich im Chart

- Das Chart zeigt die zeitliche Historie der letzten Messwerte.
- Dadurch werden kurze Kontaktprobleme, Wackler und reproduzierbare Fehler sichtbar.
- Ein ruhiger Verlauf spricht für einen stabilen Zustand.
- Sprünge, Zacken oder stark schwankende Verläufe sprechen für Kontaktprobleme oder bewegungsabhängige Fehler.
- Die Grenzlinie im Chart zeigt, ab wann ein Durchgang nicht mehr sicher OK ist.

### 12.7.11 Worauf muss ich beim Durchgang achten

- Der Zahlenwert soll klar unterhalb des Connection Threshold liegen.
- Im Balken bedeutet das: der Messwert bleibt sicher im OK-Bereich.
- Im Chart bedeutet das: die Kurve bleibt stabil und springt nicht an die Grenzlinie heran.
- Werte im Warnbereich deuten auf Übergangswiderstand, Verschmutzung oder einen beginnenden Defekt hin.
- „Schlecht“ bedeutet, dass der Soll-Durchgang nicht mehr sicher gegeben ist.

### 12.7.12 Worauf muss ich bei der Isolation achten

- Unerwünschte Verbindungen sollen deutlich oberhalb der Isolationsgrenze liegen.
- Kritisch sind niedrige oder schwankende Werte zwischen eigentlich getrennten Kanälen.
- In der Matrix werden solche Pfade als fehlerhafte Isolationsverbindung sichtbar.
- Im Chart weisen wiederkehrende Einbrüche oder kurze Spitzen nach unten auf einen intermittierenden Kurzschluss oder Verschmutzung hin.

### 12.7.13 Typisch gut

- Die Soll-Verbindungen a1-a2, b1-b2 und c1-c2 bleiben stabil im OK-Bereich.
- Die Matrix zeigt keine unerwarteten Querverbindungen.
- Im Chart verläuft die Kurve ruhig und ohne Sprünge an die Grenzlinie.

### 12.7.14 Typische Fehlerbilder

- Ein einzelner Pfad wird nur bei Bewegung „Schlecht“: typischer Hinweis auf Wackelkontakt oder Kabelbruch.
- Zwei Leitungen sind vertauscht: erwartete „Gut“ Verbindungen fehlen, während an anderer Stelle unerwartete Verbindungen erscheinen.
- Mehrere nicht zusammengehörende Kanäle zeigen geringe Isolation: typischer Hinweis auf beschädigte Isolation, Feuchtigkeit oder Schmutz.
- Ein Durchgang liegt dauerhaft im Warnbereich: typischer Hinweis auf verschlissene Stecker, Oxidation oder erhöhten Übergangswiderstand.

### 12.7.15 Hold, Fading und Historie

Verzögertes „Gut“ / „Schlecht“ durch Hold und Fading:
- Die UI zeigt Zustandswechsel nicht immer nur als harten Sofortwechsel.
- Je nach Hold Mode bleiben erkannte „Gut“ oder „Schlecht“ Zustände noch kurz sichtbar.
- Positive Verbindungen und fehlerhafte Isolationspfade können dadurch verzögert ausblenden.
- Das hilft besonders bei kurzen Kontaktfehlern oder beim Bewegen des Prüflings, weil der relevante Zustand nicht sofort verschwindet.

Wie hilft der Farbergebnis-Balken:
- Der Farbergebnis-Balken verbindet den aktuellen Messwert mit seiner jüngeren Historie.
- Dadurch ist nicht nur der Momentanwert sichtbar, sondern auch, ob ein Wert gerade stabil ist oder aus einem früheren „Schlecht“ bzw. Warnbereich herauskommt.
- Bei aktiver Hold-/Fading-Logik bleibt eine auffällige Phase noch kurz nachvollziehbar.
- Das erleichtert die Fehlersuche bei kurzen Unterbrechungen, Prellern oder bewegungsabhängigen Kontaktfehlern.

Typische Verbindungsfehler und einfache Diagnose:
- Werden zwei Leitungen gegeneinander vertauscht, erscheinen die erwarteten OK-Verbindungen nicht an der richtigen Stelle.
- Stattdessen werden in der Verbindungsmatrix andere Pfade auffällig.
- Ein Beispiel ist ein Vertauschen von a und b: Dann bleibt z. B. a1-a2 nicht OK, während an anderer Stelle eine unerwartete Verbindung sichtbar wird.
- Die Verbindungsmatrix hilft hier besonders, weil sie nicht nur sagt, dass ein Fehler vorliegt, sondern auch, zwischen welchen Leitungen dieser sichtbar wird.
- Dadurch lässt sich oft schnell erkennen, ob eher eine Unterbrechung, eine Vertauschung oder eine unerwünschte Querverbindung vorliegt.

### 12.7.16 Prüfablauf

Empfohlener Prüfablauf:
1. Passenden Untermodus Roll, Body oder Mask wählen.
2. Hauptverbindungen auf OK prüfen.
3. Bei Auffälligkeiten Matrix und Einzelbalken vergleichen.
4. Bei unklaren Fehlern in den erweiterten Modus wechseln.
5. Dort gezielt Kanalpaare für Durchgang oder Isolation prüfen.
6. Nach Reparatur oder Neuanschluss den regulären Modus erneut zur Gesamtbewertung verwenden.

### 12.8 Vest Test

### 12.8.1 Zweck

- Prüfen des Übergangswiderstands bzw. der Leitfähigkeit der Weste

### 12.8.2 Anschluss

- Die Weste bzw. der zu prüfende leitfähige Bereich wird an die dafür vorgesehene Westentest -Verbindung angeschlossen.
- Die Firmware kann mehrere mögliche Kontaktkombinationen erkennen und prüft deshalb verschiedene gültige Kanalpaare automatisch.
- Kontakte müssen sauber anliegen, damit keine falsche Unterbrechung erkannt wird.
- Es gibt zwei praktische Varianten:
- Variante 1: Anschluss an zwei beliebig gewählten Prüfpunkten der Weste.
- Variante 2: separater Vest-Anschluss mit zusätzlicher Farbanzeige und optionaler Vibrationsrückmeldung.

### 12.8.3 Verhalten bei Anschlusswechsel und Prüfpause

Der Vest-Test arbeitet vollautomatisch. Der Nutzer muss keine Betriebsart auswählen.

### 12.8.4 Verhalten der Anzeige

- Nach dem Anlegen der Prüfpunkte kann der erste gültige Messpunkt leicht verzögert erscheinen.
- Diese erste Verzögerung liegt typischerweise nur im Bereich von etwa 100ms.
- Wird der Anschluss gewechselt, erscheint die neue Bewertung nicht sofort.
- Die neutrale Anzeige erscheint nur während der automatischen Suche nach einem gültigen Anschlusspaar.
- Solange eine aktive Bewertung vorhanden ist, bleibt die Ergebnisanzeige sichtbar.
- Fällt ein zuvor gültiger Durchgang weg, bleibt die Anzeige zunächst auf Rot.
- Erst wenn für eine gewisse Zeit kein gültiger Durchgang mehr erkannt wird, wechselt das Gerät zurück in die automatische Suche.
- Dann erscheint die neutrale Anzeige.
- Wird in dieser Phase sofort ein neues gültiges Anschlusspaar gefunden, wechselt die Anzeige direkt in das neue Prüfergebnis.
- Wird kein neues gültiges Paar gefunden, bleibt die Anzeige neutral, bis wieder eine gültige Verbindung erkannt wird.
- Dieses Verhalten ist normal und dient einer stabilen Bewertung nach Anschlusswechsel oder kurzer Prüfunterbrechung.

### 12.8.5 Anzeige und Bewertung

- Der Hauptwert wird als Widerstandsbar und Verlaufsgrafik angezeigt.
- Die Darstellung unterscheidet zwischen „Gut“, Warnbereich, „Schlecht“ und getrennt.
- Zusätzlich kann die Rückmeldung akustisch, per Vibration und über die externe LED-Anzeige erfolgen.
- Beim Suchen eines gültigen Anschlusspaars bleibt die Anzeige neutral.
- Sobald eine stabile Bewertung möglich ist, zeigt die Anzeige den Zustand farblich entsprechend dem Ergebnis.

### 12.8.6 Was sehe ich im Balken und im Chart

- Der Hauptbalken zeigt den aktuellen Widerstand relativ zu Grenzwert und Plot-Maximum.
- Die Farbzonen helfen beim schnellen Erkennen von „Gut“, Warnbereich und „Schlecht“.
- Das Chart zeigt den zeitlichen Verlauf und damit auch kurze Aussetzer oder Kontaktbewegungen.
- Mit aktivem Hold Mode bleiben auffällige Zustände noch kurz sichtbar und blenden erst danach wieder aus.

### 12.8.7 Typisch gut

- Die Anzeige wechselt nach kurzer Erkennung stabil in grün.
- Der Widerstand bleibt ruhig im OK-Bereich.
- Auch bei leichtem Bewegen der Prüfpunkte bleibt die Bewertung stabil.

### 12.8.8 Typische Fehlerbilder

- Die Anzeige springt bei Bewegung zwischen grün, gelb und rot: typischer Hinweis auf verschlissene Kontaktflächen oder lokale Unterbrechungen.
- Die Anzeige bleibt oft neutral: typischer Hinweis auf fehlenden oder instabilen Kontakt zum Prüfling.
- Die Anzeige wird schnell rot: typischer Hinweis auf zu hohen Übergangswiderstand, verschmutzte Fläche oder defekte Anschlussstelle.

### 12.8.9 Prüfablauf

Empfohlener Prüfablauf:
1. Weste sicher anschließen.
2. Kurz abwarten, bis eine stabile Verbindung erkannt wurde.
3. Den Prüfstift systematisch über die Weste führen.
4. Den Prüfstift nicht zusätzlich aufdrücken, sondern nur mit der vorgesehenen Prüfkraft bzw. mit dem Eigengewicht arbeiten.
5. Vorder- und Rückseite der Weste prüfen.
6. Darauf achten, dass über die gesamte Fläche ein guter Durchgang vorhanden ist.
7. Bereiche mit Beschriftung oder Bedruckung sowie den Maskenlatz besonders sorgfältig prüfen, da hier erhöhter Verschleiß auftreten kann.
8. An Nähten achtsam prüfen.
9. Wenn die Prüfspitze beim Überfahren einer Naht kurz darüber springt, kann dadurch ungewollt kurz eine Unterbrechung entstehen.
10. Deshalb an Nähten möglichst nicht quer mit springender Spitze darüberfahren, sondern links und rechts entlang der Naht prüfen.
11. Hauptwert und Verlaufsanzeige beobachten.
12. Bei getrennt zuerst Anschluss und Kontaktfläche prüfen.
13. Bei Warnbereich oder „Schlecht“ Anschluss wiederholen und danach den Prüfling bewerten.

### 12.9 Säbel Test

### 12.9.1 Zweck und Besonderheiten

- Prüfen der relevanten Leitungs- und Kontaktpfade vom Säbel
- Darstellung der relevanten Leitungs- und Isolationspfade für den Säbeltest.
- Bewertung über Messbalken, Statusfarben und Ergebnisfeld.
- Zugang zu den Weapon-Test-Einstellungen per Geste oder Antippen.

### 12.9.2 Allgemeiner Ablauf

1. Waffe / Waffenleitung korrekt anschließen.
2. Passenden Waffentest wählen.
3. Messpfade, Verbindungen, Kurzschlüsse und Zusatzpfade beurteilen.
4. Ergebnisanzeige „Gut“ / „Schlecht“ / --- beachten.

### 12.9.3 Anschluss

- Die Säbel-Komponente bzw. der zugehörige Leitungsweg wird an die dafür vorgesehene Waffenverbindung angeschlossen.
- Für die Auswertung werden die Kanäle a1, b1, c1, c2 sowie der Zusatzkanal p verwendet.
- Generell liegt das Kabel auf der 1er-Seite; der Waffenanschluss bzw. die zusätzliche Prüfmöglichkeit wird passend auf der Gegenseite bzw. über p eingebunden.

### 12.9.4 Anzeige und Bewertung

### 12.9.5 Was sehe ich im Balken und im Chart:

- Die Balken zeigen die relevanten Haupt- und Zusatzwerte als Momentanwerte.
- Das Chart zeigt die zeitliche Entwicklung und hilft beim Erkennen instabiler Kontakte.
- Mit Hold Mode und Fading bleiben kurze „Schlecht“-Phasen noch sichtbar, auch wenn der Kontakt sich sofort wieder erholt.

### 12.9.6 Typisch gut

- Hauptpfade und Zusatzpfade bleiben stabil im erwarteten Zustand.
- Die Klinge zeigt einen guten elektrischen Kontakt ohne auffällige Schwankungen.
- Oxidation oder lose Kontakte machen sich weder im Balken noch im Chart bemerkbar.

### 12.9.7 Typische Fehlerbilder

- Schlechter Kontakt zur Klinge oder oxidierte Kontaktstellen führen zu erhöhtem Widerstand oder instabiler Anzeige.
- Unerwartete Querverbindungen deuten auf Verdrahtungsfehler oder fehlerhafte Isolation hin.
- Ein nur bei Bewegung auftretendes „Schlecht“ spricht oft für einen Wackelkontakt im Kabel- oder Waffenanschluss.

### 12.9.8 Prüfablauf

1. Prüfling korrekt anschließen.
2. Sabre Test aufrufen.
3. Hauptverbindung und Zusatzpfade beobachten.
4. Isolationspfade und eventuelle Fehlverbindungen anhand der Anzeige bewerten.
5. Ergebnis „Gut“ oder „Schlecht“ für die Gesamtbeurteilung heranziehen.

### 12.10 Florett Test

### 12.10.1 Zweck und Besonderheiten

- Prüfen der relevanten Leitungs- und Kontaktpfade des Floretts
- Neben dem regulären Messbild existiert ein Trigger-Untermodus.
- Der Trigger-Untermodus kann über den aktiven Seitenbutton oder die Bedienlogik des Modus aktiviert werden.
- Der Trigger Wert wird relativ zur eingestellten Trigger-Position bewertet.
- Die Trigger Anzeige eignet sich für das Beobachten des Auslöseverhaltens.

### 12.10.2 Allgemeiner Ablauf

1. Waffe / Waffenleitung korrekt anschließen.
2. Passenden Waffentest wählen.
3. Messpfade, Verbindungen, Kurzschlüsse und Zusatzpfade beurteilen.
4. Ergebnisanzeige „Gut“ / „Schlecht“ / --- beachten.

### 12.10.3 Anschluss

- Die Florett-Komponente bzw. der zugehörige Leitungsweg wird an die vorgesehene Waffenverbindung angeschlossen.
- Für die Auswertung werden die Kanäle a1, b1, c1, c2 und p verwendet.
- Generell liegt das Kabel auf der 1er-Seite; die Waffe bzw. die zusätzliche Prüfmöglichkeit wird passend auf der Gegenseite bzw. über p eingebunden.

### 12.10.4 Anzeige und Bewertung

### 12.10.5 Was sehe ich im Balken und im Chart

- Die Balken zeigen die aktuellen Messwerte für Hauptkontakt und Zusatzpfade.
- Das Chart zeigt, ob die Werte stabil OK bleiben oder kurzzeitig in Warnbereich oder „Schlecht“ springen.
- Bei aktiver Hold-/Fading-Logik bleiben kurze Auffälligkeiten noch kurz sichtbar.

### 12.10.6 Typisch gut

- Die Verdrahtung der Spitze ist korrekt und die Anzeige bleibt im Ruhezustand stabil.
- Beim Auslösen schaltet der Kontakt klar und reproduzierbar um.
- Im erweiterten Modus ist kein unruhiges Mehrfachschalten sichtbar.

### 12.10.7 Typische Fehlerbilder

- Die Spitze löst elektrisch nicht sauber aus: möglicher Hinweis auf verschmutzte Spitze, Kontaktproblem oder fehlerhafte Verdrahtung.
- Die Anzeige springt beim Betätigen mehrfach: typischer Hinweis auf Prellen oder mechanisch instabile Kontaktteile.
- Zusatzpfade über p zeigen kein erwartetes Verhalten: möglicher Hinweis auf Verdrahtungsfehler in der zusätzlichen Prüfmöglichkeit.

### 12.10.8 Erweiterter Modus

- Zusätzlich steht ein erweiterter Modus für die Kontaktauslösung zur Verfügung.
- Dieser Modus dient zum Beobachten des Umschaltverhaltens des Kontakts.
- Damit lässt sich auch prüfen, ob der Kontakt sauber auslöst oder prellt.
- Es wird mit erhöhter Abtastrate gearbeitet, bei einen Signalwechsel Gut zu Schlecht oder Schlecht zu Gut bleibt dieses Ereignis an der Triggerposition stehen. Es ist somit sehr gut möglich das Auslöseereignis kurz vor und nach der Auslösung zu begutachten.
- Eine Berührung des Chart Bereiches setzt die gestoppte Messung wieder fort.

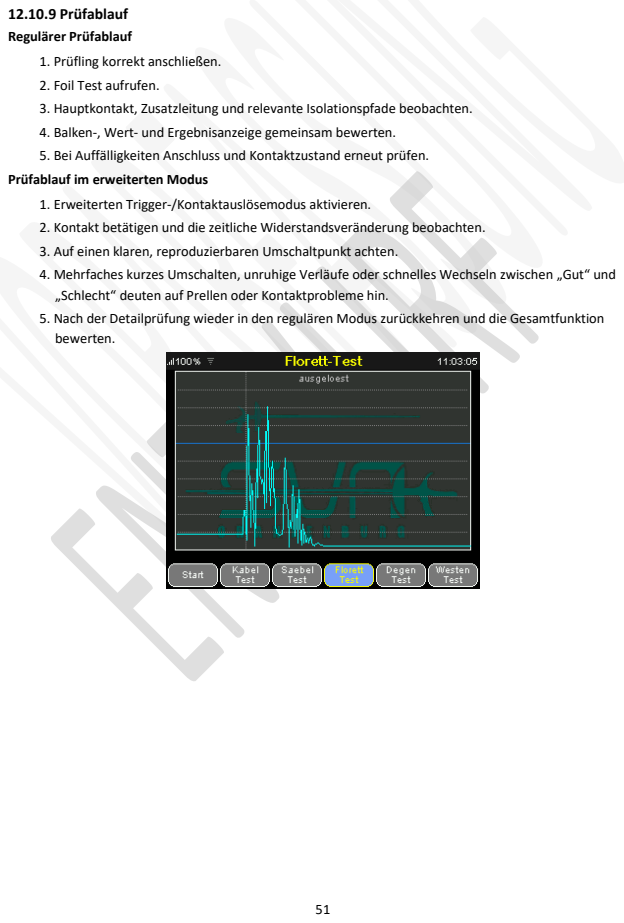
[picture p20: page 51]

12.10.9 Prüfablauf
Regulärer Prüfablauf
1. Prüfling korrekt anschließen.
2. Foil Test aufrufen.
3. Hauptkontakt, Zusatzleitung und relevante Isolationspfade beobachten.
4. Balken-, Wert- und Ergebnisanzeige gemeinsam bewerten.
5. Bei Auffälligkeiten Anschluss und Kontaktzustand erneut prüfen.
Prüfablauf im erweiterten Modus
1. Erweiterten Trigger-/Kontaktauslösemodus aktivieren.
2. Kontakt betätigen und die zeitliche Widerstandsveränderung beobachten.
3. Auf einen klaren, reproduzierbaren Umschaltpunkt achten.
4. Mehrfaches kurzes Umschalten, unruhige Verläufe oder schnelles Wechseln zwischen „Gut“ und
„Schlecht“ deuten auf Prellen oder Kontaktprobleme hin.
5. Nach der Detailprüfung wieder in den regulären Modus zurückkehren und die Gesamtfunktion
bewerten.

### 12.11 Degen Test

### 12.11.1 Zweck und Besonderheiten

- Prüfen der relevanten Leitungs- und Kontaktpfade vom Degen
- Entspricht grundsätzlich dem Foil-Ablauf mit eigener Trigger-Beurteilung.
- Auch hier ist ein Trigger-Untermodus verfügbar.
- Die Parameter für Grenzwert, Plot und Trigger-Position stammen aus den gemeinsamen Weapon-Test-Einstellungen.

### 12.11.2 Allgemeiner Ablauf

1. Waffe / Waffenleitung korrekt anschließen.
2. Passenden Waffentest wählen.
3. Messpfade, Verbindungen, Kurzschlüsse und Zusatzpfade beurteilen.
4. Ergebnisanzeige „Gut“ / „Schlecht“ / --- beachten.

### 12.11.3 Anschluss

- Die Degen-Komponente bzw. der zugehörige Leitungsweg wird an die vorgesehene Waffenverbindung angeschlossen.
- Für die Auswertung werden die Kanäle a1, b1, c1 und p verwendet.
- Generell liegt das Kabel auf der 1er-Seite; die Waffe bzw. die zusätzliche Prüfmöglichkeit wird passend auf der Gegenseite bzw. über p eingebunden.

### 12.11.4 Anzeige und Bewertung

### 12.11.5 Was sehe ich im Balken und im Chart

- Die Balken zeigen die aktuellen Haupt- und Zusatzwerte.
- Das Chart zeigt stabile Verläufe ebenso wie kurze Kontaktstörungen.
- Hold Mode und Fading helfen dabei, auch sehr kurze „Schlecht“- oder Warnbereich-Phasen noch zu erkennen.

### 12.11.6 Typisch gut

- Der Hauptkontakt bleibt im Ruhezustand stabil und schaltet bei Betätigung eindeutig.
- Die Verdrahtung zur Glocke und zum Kontaktpfad zeigt das erwartete Verhalten.
- Im erweiterten Modus erscheint ein klarer Umschaltpunkt ohne unruhige Mehrfachereignisse.

### 12.11.7 Typische Fehlerbilder

- Falsche Verdrahtung zur Glocke führt zu unerwarteten Zuständen oder fehlendem Schalten.
- Eine verschmutzte oder mechanisch verschlissene Spitze zeigt unruhige oder verzögerte Umschaltungen.
- Wiederholte kurze Wechsel zwischen „Gut“ und „Schlecht“ sprechen für Prellen oder einen instabilen Kontaktweg.

### 12.11.8 Erweiterter Modus

- Auch im Degen-Test steht ein erweiterter Modus für die Kontaktauslösung zur Verfügung.
- Dieser Modus eignet sich für die Beurteilung von Schaltpunkt, Kontaktstabilität und Prellen.
- Es wird mit erhöhter Abtastrate gearbeitet, bei einen Signalwechsel Gut zu Schlecht oder Schlecht zu Gut bleibt dieses Ereignis an der Trigger Position stehen. Es ist somit sehr gut möglich das Auslöseereignis kurz vor und nach der Auslösung zu begutachten.
- Eine Berührung des Chart Bereiches setzt die gestoppte Messung wieder fort.

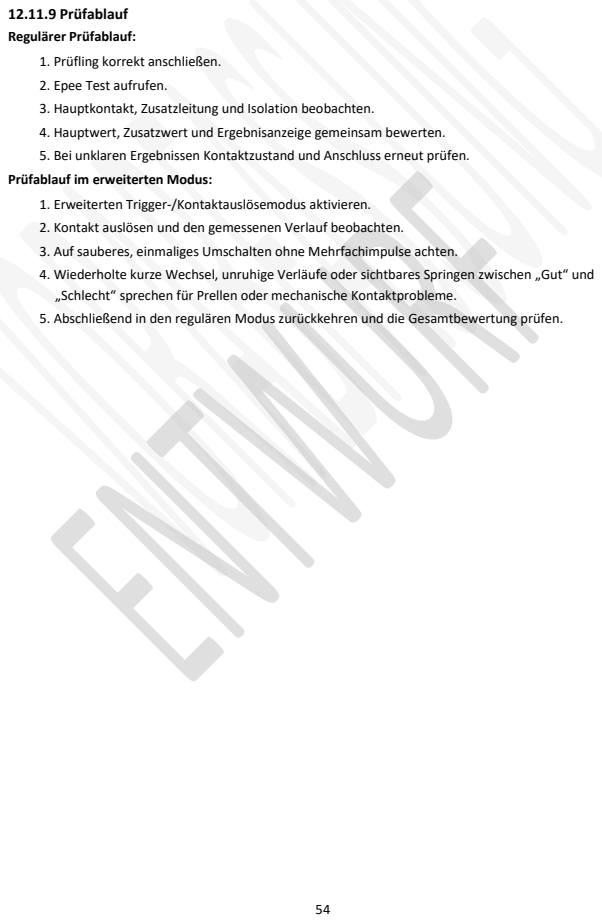
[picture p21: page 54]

12.11.9 Prüfablauf
Regulärer Prüfablauf:
1. Prüfling korrekt anschließen.
2. Epee Test aufrufen.
3. Hauptkontakt, Zusatzleitung und Isolation beobachten.
4. Hauptwert, Zusatzwert und Ergebnisanzeige gemeinsam bewerten.
5. Bei unklaren Ergebnissen Kontaktzustand und Anschluss erneut prüfen.
Prüfablauf im erweiterten Modus:
1. Erweiterten Trigger-/Kontaktauslösemodus aktivieren.
2. Kontakt auslösen und den gemessenen Verlauf beobachten.
3. Auf sauberes, einmaliges Umschalten ohne Mehrfachimpulse achten.
4. Wiederholte kurze Wechsel, unruhige Verläufe oder sichtbares Springen zwischen „Gut“ und
„Schlecht“ sprechen für Prellen oder mechanische Kontaktprobleme.
5. Abschließend in den regulären Modus zurückkehren und die Gesamtbewertung prüfen.

### 13. Parameter

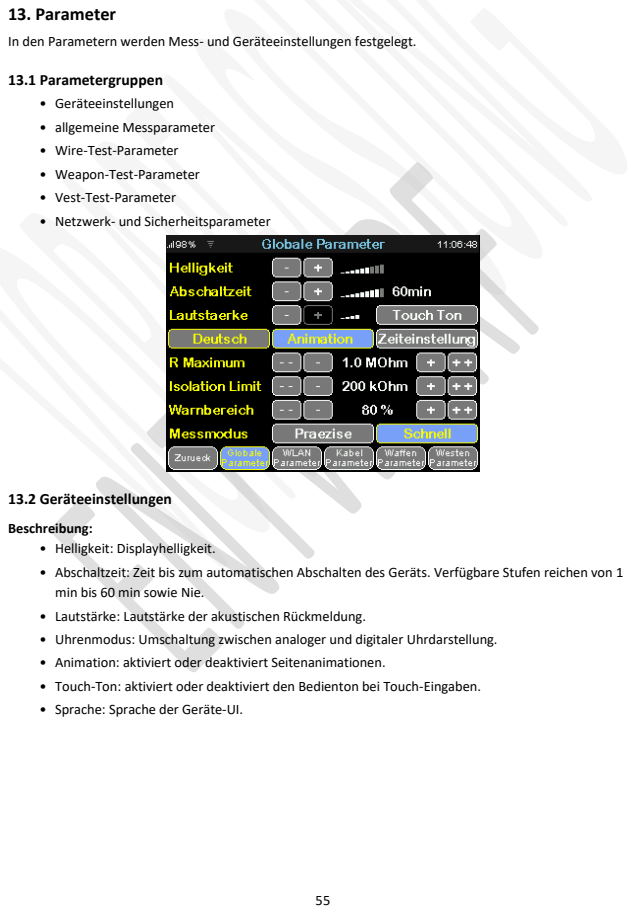
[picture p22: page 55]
13.2 Geräteeinstellungen

In den Parametern werden Mess- und Geräteeinstellungen festgelegt.

13.1 Parametergruppen
• Geräteeinstellungen
• allgemeine Messparameter
• Wire-Test-Parameter
• Weapon-Test-Parameter
• Vest-Test-Parameter
• Netzwerk- und Sicherheitsparameter

Beschreibung:
• Helligkeit: Displayhelligkeit.
• Abschaltzeit: Zeit bis zum automatischen Abschalten des Geräts. Verfügbare Stufen reichen von 1
min bis 60 min sowie Nie.
• Lautstärke: Lautstärke der akustischen Rückmeldung.
• Uhrenmodus: Umschaltung zwischen analoger und digitaler Uhrdarstellung.
• Animation: aktiviert oder deaktiviert Seitenanimationen.
• Touch-Ton: aktiviert oder deaktiviert den Bedienton bei Touch-Eingaben.
• Sprache: Sprache der Geräte-UI.

### 13.3 Allgemeine Messparameter

### 13.3.1 Beschreibung

- R Maximum: Obergrenze, bis zu der der Messbereich dargestellt wird.
- Isolation Limit: Untergrenze für die Bewertung einer unerwünschten Isolation / eines Fehlpfads.
- Warnbereich: Bereich vor der Fehlergrenze, in dem eine Warnanzeige erfolgt.
- Messmodus: Umschaltung zwischen Schnell und Präzise.

### 13.3.2 Einfach erklärt

- R Maximum bestimmt die obere Darstellungsgrenze der Anzeige.
- Isolation Limit legt fest, ab wann eine eigentlich unerwünschte Verbindung kritisch wird.
- Warnbereich ist der Vorwarnbereich vor „Schlecht“.
- Ein eingestellter Wert von 80 % bedeutet: Bis 80 % des Weges zur Fehlergrenze gilt der Wert noch als unbedenklich.
- Ab diesem Punkt beginnt der farbliche Warnbereich als Übergang von grün zu gelb.
- Messmodus bestimmt, ob eher schnell oder eher besonders ruhig und genau bewertet wird.

### 13.4 Kabel-Test-Parameter

### 13.4.1 Beschreibung

- Ton Modus: akustische Rückmeldung im Kabeltest.
- Hold Modus: Nachhalteverhalten der Anzeige für Kabeltest-Ergebnisse. Je nach Einstellung bleiben positive oder fehlerhafte Anzeigen noch eine Zeit sichtbar und klingen dann über die Fading-Logik wieder aus.
- Körper- / Maskenkabel: Parametergruppe für Körper- und Maskenkabel.
- Rolle: Parametergruppe für den Rollen-Untermodus.
- Schwellwert: Grenzwert für die jeweilige Messung.
- Graph Limit: oberes Plot-Ende für die jeweilige Darstellung.

### 13.4.2 Einfach erklärt

- Ton Modus steuert die Tonausgabe.
- Hold Modus sorgt dafür, dass „Gut“ oder „Schlecht“ nicht sofort verschwinden.
- Schwellwert ist die Grenze zwischen noch gutem und zu hohem Widerstand.
- Graph Limit bestimmt, bis zu welchem Maximalwert Balken und Verlauf skaliert werden.

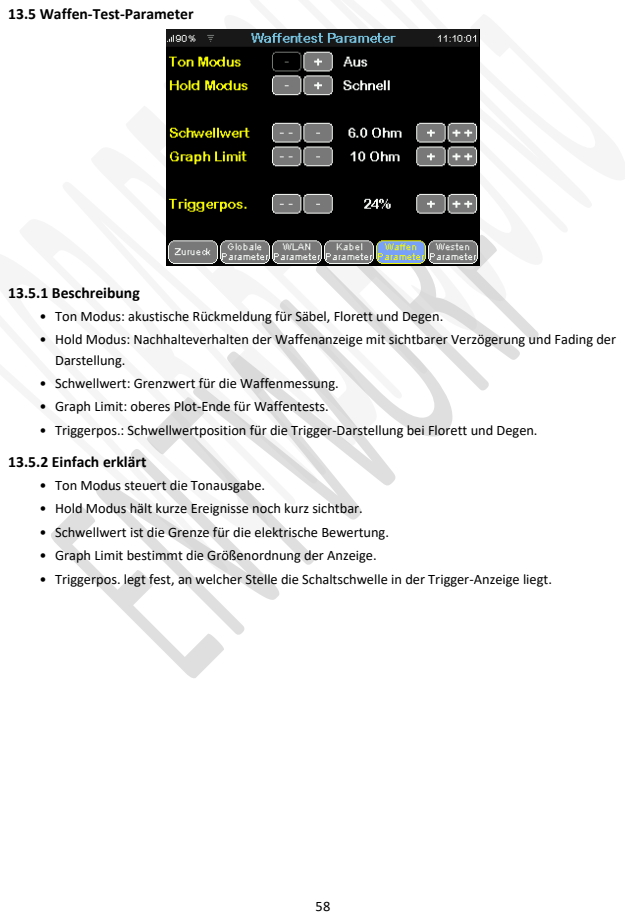
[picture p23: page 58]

13.5 Waffen-Test-Parameter

13.5.1 Beschreibung
• Ton Modus: akustische Rückmeldung für Säbel, Florett und Degen.
• Hold Modus: Nachhalteverhalten der Waffenanzeige mit sichtbarer Verzögerung und Fading der
Darstellung.
• Schwellwert: Grenzwert für die Waffenmessung.
• Graph Limit: oberes Plot-Ende für Waffentests.
• Triggerpos.: Schwellwertposition für die Trigger-Darstellung bei Florett und Degen.

13.5.2 Einfach erklärt
• Ton Modus steuert die Tonausgabe.
• Hold Modus hält kurze Ereignisse noch kurz sichtbar.
• Schwellwert ist die Grenze für die elektrische Bewertung.
• Graph Limit bestimmt die Größenordnung der Anzeige.
• Triggerpos. legt fest, an welcher Stelle die Schaltschwelle in der Trigger-Anzeige liegt.

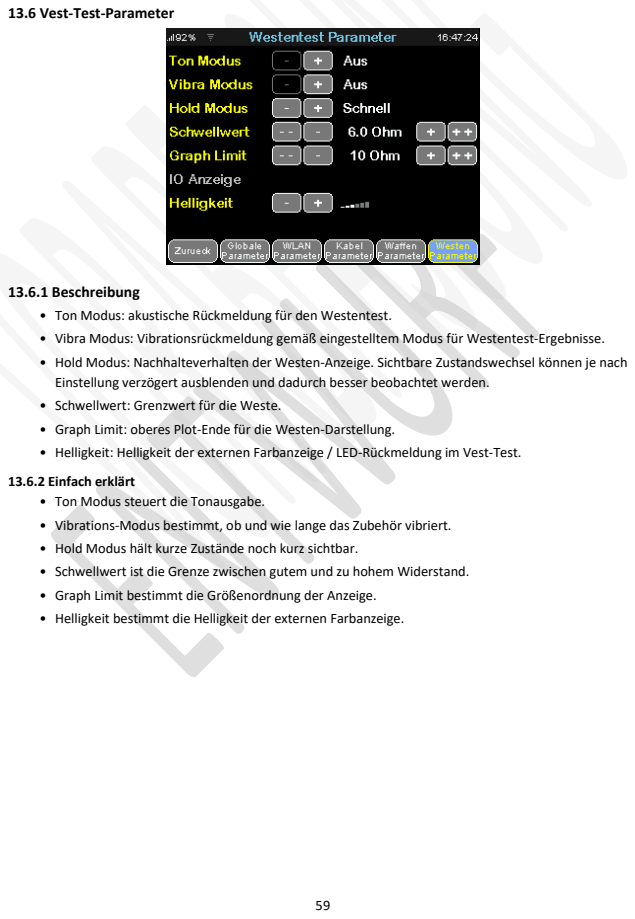
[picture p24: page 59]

13.6 Vest-Test-Parameter

13.6.1 Beschreibung
• Ton Modus: akustische Rückmeldung für den Westentest.
• Vibra Modus: Vibrationsrückmeldung gemäß eingestelltem Modus für Westentest-Ergebnisse.
• Hold Modus: Nachhalteverhalten der Westen-Anzeige. Sichtbare Zustandswechsel können je nach
Einstellung verzögert ausblenden und dadurch besser beobachtet werden.
• Schwellwert: Grenzwert für die Weste.
• Graph Limit: oberes Plot-Ende für die Westen-Darstellung.
• Helligkeit: Helligkeit der externen Farbanzeige / LED-Rückmeldung im Vest-Test.

13.6.2 Einfach erklärt
• Ton Modus steuert die Tonausgabe.
• Vibrations-Modus bestimmt, ob und wie lange das Zubehör vibriert.
• Hold Modus hält kurze Zustände noch kurz sichtbar.
• Schwellwert ist die Grenze zwischen gutem und zu hohem Widerstand.
• Graph Limit bestimmt die Größenordnung der Anzeige.
• Helligkeit bestimmt die Helligkeit der externen Farbanzeige.

### 13.7 Netzwerk- und Sicherheitsparameter

### 13.7.1 Beschreibung

- WLAN-Modus: Off, Client oder Access Point.
- WLAN-Zugänge: mehrere speicherbare WLAN-Slots für bekannte Netze.*
- Gerätename: gemeinsamer Basisname für WLAN-Clientname, AP-Name und mDNS-Host.*
- DHCP oder statische Netzwerkkonfiguration.*
- mDNS: erleichterter Netzwerkzugriff über Namen statt IP-Adresse.
- FTP: optionaler Netzwerkdienst.
- Administrator-Passwort: Freischaltung geschützter Verwaltungsfunktionen.*
- Nur-Lese-Zugriff: erlaubt bei Bedarf nur eingeschränkten Zugriff ohne Administrator-Änderungen.*

### 13.7.2 Einfach erklärt

- WLAN-Modus bestimmt, ob WLAN aus ist, ob das Gerät sich in ein vorhandenes WLAN einwählt oder selbst ein WLAN bereitstellt.
- WLAN-Zugänge sind gespeicherte bekannte WLAN-Zugänge.*
- Gerätename ist der Name, unter dem das Gerät im Netzwerk erscheint.*
- DHCP bedeutet automatische Vergabe der Netzwerkadresse.*
- statisch bedeutet: Adresse und weitere Netzwerkdaten werden fest eingetragen.*
- mDNS bedeutet: das Gerät kann oft über einen Namen statt über eine Zahlenadresse aufgerufen werden.
- FTP ist ein optionaler Dateizugriff über das Netzwerk.
- Administrator-Passwort schützt wichtige Einstellungen.*
- Nur-Lese-Zugriff erlaubt nur Lesen, aber keine Änderungen.*

Hinweis:
- Parameter nur von eingewiesenen Anwendern ändern.
- Parameter beeinflussen Messbeurteilung, Bedienverhalten, Netzwerkverbindung und Wartungsfunktionen.

* nur in Browser Oberfläche änderbar

### 14. WLAN-Verbindung herstellen

Das Gerät unterstützt je nach Konfiguration:
- Client Mode
- Access Point (AP) Mode

Einfach erklärt:
- Client Mode bedeutet: das Gerät verbindet sich mit einem bereits vorhandenen WLAN.
- Access Point oder AP Mode bedeutet: das Gerät eröffnet selbst ein eigenes WLAN, mit dem sich Handy, Tablet oder Computer direkt verbinden können.

### 14.1 Client Mode

Im Client Mode verbindet sich das Gerät mit einem vorhandenen WLAN.

Bei erstmaliger Verbindung muss man sich per AP-Mode verbinden und der WLAN Zugangspunkt muss parametriert werden. Der Tester kann bis zu vier WLAN Zugänge nutzen, wobei er sich mit dem besten verbindet und bei Verbindungsverlust automatisch zum nächstbesten WLAN wechselt.

Allgemeiner Ablauf:
1. WLAN-Zugangsdaten am Gerät einstellen. Dies geht nur über Browser Oberfläche bei bestehender WLAN Verbindung, ggf. vorher per AP – Mode verbinden.
2. Verbindung starten.
3. Zugewiesene IP-Adresse ermitteln.
4. Web-App im Browser über die angezeigte Adresse aufrufen.

### 14.2 Access Point Mode

Im AP Mode stellt das Gerät selbst ein WLAN bereit.

Allgemeiner Ablauf:
1. AP Mode aktivieren.
2. Mit dem vom Gerät bereitgestellten WLAN verbinden.
3. Browser öffnen und die Web-App über die lokale Adresse aufrufen.

Hinweise:
- Reichweite und Stabilität hängen von der Umgebung ab.
- Beim Einsatz in störbehafteter Umgebung können Verbindungsabbrüche auftreten.
- WLAN ist nur für den bedarfsweisen Betrieb vorgesehen und in der Regel nicht dauerhaft aktiv.

### 15. Browser-Oberfläche aufrufen

Zusätzlich zur Bedienung am Gerät kann eine Browser-Oberfläche auf Handy, Tablet oder Computer verwendet werden.

### 15.1 Aufruf

- über IP-Adresse im Client Mode
- über lokale Adresse im AP Mode, z.B. http://192.168.4.1

### 15.2 Empfehlungen

- aktuellen Browser verwenden
- nach Firmware-Update die Seite neu laden
- bei Verbindungsproblemen Netzwerk und Browser-Cache prüfen
- für ändernde Verwaltungsfunktionen vorher anmelden
- beachten, dass für die Live-Steuerung immer nur ein verbundenes Bediengerät gleichzeitig vorgesehen ist

### 16. Web-App Bedienung

Die Browser-Oberfläche dient zusätzlich zur Anzeige, Einstellung und Wartung.

### 16.1 Allgemeiner Aufbau

- obere Navigationsleiste (Navbar) mit Direktzugriff auf Live-Test, Einstellungen, Info, Über, Sprachumschaltung, Theme-Umschaltung und Anmelden / Abmelden
- Standby-Indikator in der Navbar
- seitenweise gegliederte Konfigurations- und Informationsansichten
- geschützte Verwaltungsseiten für Konfiguration, Sicherheit, Neustart und OTA

### 16.2 Standby-Indikator in der Web-App

- In der Navbar wird die verbleibende Standby-Zeit des Geräts als kreisförmiger Fortschrittsindikator angezeigt.
- Bei Verbindungsverlust wird der Indikator in einen Offline-Zustand gesetzt.
- Relevante Benutzerinteraktionen in der Web-App senden Aktivität an das Gerät, damit der Standby-Timer zurückgesetzt werden kann.

### 16.3 Login und Rollen

- Ohne Anmeldung sind nicht alle Verwaltungsfunktionen verfügbar.
- Für sicherheitsrelevante oder ändernde Funktionen wie OTA, Netzwerkeinstellungen, Admin-Passwort, Import/Export oder Werksreset ist die Anmeldung erforderlich.

### 16.4 Live-Test

- Die Startseite der Browser-Oberfläche ist die Live-Ansicht Live-Test.
- Dort werden die aktuell aktiven Gerätemodi visualisiert.
- Verfügbar sind die Ansichten für Home, Kabel, Säbel, Florett, Degen und Westen.
- Der Wire-Test bietet auch in der Web-App den erweiterten Einzelpaar-Modus.
- Bei Foil und Epee wird der Trigger-Untermodus mit eigener Darstellung unterstützt.
- Die untere Modus Leiste der Live-Ansicht erlaubt den Seitenwechsel analog zur Geräte-UI.
- Zwischen analoger und digitaler Uhrdarstellung kann in der Home-Ansicht umgeschaltet werden.

### 16.5 Nur ein aktiver Client

- Für die aktive Live-Steuerung ist immer nur ein verbundenes Bediengerät gleichzeitig vorgesehen.
- Belegt ein anderer Browser bereits den Live-Zugriff, erscheint der Hinweis Gerät wird bereits verwendet.
- Nach Freigabe oder erneutem Laden kann der Zugriff erneut angefordert werden.

### 16.6 Settings-Seiten

- Gerät: Geräteeinstellungen wie Helligkeit, Abschaltzeit, Lautstärke, Uhr Modus, Animation und Touch-Ton.
- Messparameter: Messeinstellungen, also alle allgemeinen Messparameter sowie kabel-, waffen-und westenspezifische Parameter.
- Netzwerk: Netzwerkeinstellungen wie WLAN-Modus, gespeicherte WLAN-Zugänge, DHCP/statische IP, mDNS, FTP und Gerätename.
- Zeiteinstellungen: Zeiteinstellungen und Übernahme der lokalen Browser-Zeit.
- Sicherheit: Sicherheitseinstellungen wie Administrator-Passwort und optionaler Nur-Lese-Zugriff.
- Konfigurationsverwaltung: Verwaltung gespeicherter Einstellungen mit Export, Backup, Import und Werkseinstellungen.
- Firmware-Aktualisierung: Übertragen einer OTA-Datei und Anwenden des Updates.
- Neustart: manueller Neustart, falls gezielt benötigt.

### 16.7 Info-Seiten

- System: Firmware-, Hardware-, Speicher- und Laufzeitinformationen.
- Netzwerk: WLAN- und Schnittstellenstatus für Betrieb im vorhandenen WLAN oder im eigenen Geräte-WLAN.
- Konsole: Diagnose- bzw. Konsolenausgaben.
- Über: Hintergrundinformationen zum Projekt, zur Entstehung des Testers, zum Vereinsbezug, zur Dokumentation sowie zu Fehlerberichten und Diskussion.
- zusätzlich Zugriff auf Device-UI Screenshot anzeigen bzw. Device-UI Screenshot herunterladen zum Öffnen oder Herunterladen eines aktuellen Display-Screenshots im BMP-Format.

### 16.8 Parameter Handling Import/Export:

- Aktuelle Konfiguration herunterladen exportiert die aktuelle Konfiguration als JSON-Datei.
- Backup auf dem Gerät erstellen speichert eine Sicherungskopie auf dem Gerät.
- Gespeicherte Backup-Dateien können gelistet, heruntergeladen, gelöscht oder wieder eingespielt werden.
- Beim Import einer JSON-Datei werden Import-Kategorien ausgewählt, z. B. Gerät, Testparameter, WLAN und Admin.
- Der Import schreibt die gewählten Werte in die dauerhafte Konfiguration und startet das Gerät anschließend neu.
- Werkseinstellungen setzt die gespeicherte Konfiguration auf Werkseinstellungen zurück und führt ebenfalls einen Neustart aus.

Hinweis:
- Die hauptsächliche Bedienung erfolgt weiterhin über das Gerät.
- Die Browser Oberfläche ergänzt die Bedienung, ersetzt sie aber nicht in allen Situationen.

### 17. Firmware-Update

Firmware-Updates können über die Browser-Oberfläche eingespielt werden. Das Gerät benötigt dafür keinen eigenen Internetzugang; ein verbundenes Smartphone oder ein Computer übernimmt bei Bedarf den Download aus dem öffentlichen Projektportal.

Allgemeiner Ablauf:
1. An der Browser-Oberfläche anmelden.
2. Seite Firmware-Aktualisierung öffnen.
3. Für die aktuelle Freigabe "Neueste Version laden" wählen. Die Web-App lädt das vollständige Bundle über den Client, prüft dessen SHA-256-Prüfsumme und stellt es für die lokale Übertragung bereit.
4. Alternativ eine bereits gespeicherte OTA-Datei im Format .ota oder .ota.gz auswählen.
5. Update starten sowie Rückfragen und OTA-Optionen bestätigen.
6. Upload-Fortschritt abwarten.
7. Apply-Phase und automatische Prüfung / Übernahme abwarten.
8. Automatischen Neustart abwarten.
9. Nach dem Neustart Funktion prüfen.

Wichtige Hinweise:
- OTA-Updates sind nur nach erfolgreicher Anmeldung zulässig.
- Nur freigegebene Update-Dateien verwenden.
- Während des Updates keine Spannungsversorgung unterbrechen.
- Nach dem Update ggf. Browser neu laden.
- Das OTA-Format ist gerätespezifisch. Andere oder fremde Updateformate dürfen nicht verwendet werden.

Einfach erklärt:
- OTA bedeutet hier: die neue Firmware wird über WLAN und Browser an das Gerät übertragen, ohne das Gerät zu öffnen.

### 17.1 Rückfragen vor dem OTA-Start

Vor dem eigentlichen Update kann die Web-App zusätzliche Rückfragen stellen:
- Wenn die ausgewählte Datei bereits derselben Firmware-Version entspricht, wird eine Sicherheitsabfrage angezeigt.
- Wenn die ausgewählte Datei älter als die aktuell installierte Version erscheint, wird eine Downgrade-Bestätigung angezeigt.

### 17.2 OTA-Optionen

Verfügbare Option:
- Format webapp filesystem before update

Bedeutung:
- Bei aktivierter Option werden vorhandene LittleFS-Webapp-Dateien vor dem Einspielen gelöscht.
- Anschließend werden die im OTA-Paket enthaltenen Webapp-Dateien neu installiert.
- Diese Option ist sinnvoll, wenn Webapp-Dateien vollständig ersetzt oder Inkonsistenzen bereinigt werden sollen.

### 17.3 Verhalten während des OTA

Typischer Ablauf in der Web-App:
- Datei-Upload mit Prozentanzeige
- anschließende Apply-Phase ohne weitere Bedienung
- Hinweis, dass das Gerät währenddessen nicht ausgeschaltet oder zurückgesetzt werden darf
- automatischer Neustart nach erfolgreicher Übernahme
- erneutes Laden der Web-App, sobald das Gerät wieder erreichbar ist

### 17.4 Lokaler Service- und Programmierzugriff

Hinweise:
- Ein direkter lokaler Firmware-Zugriff ist nur bei geöffnetem Gerät möglich.
- Dieser Zugriff ist nicht für Benutzer vorgesehen.
- Beim ersten Prototyp ist der lokale Zugriff über USB nur bei geöffnetem Gerät und physischem Zugriff möglich.
- Bei zukünftigen Geräten ist ein lokaler Service- oder Programmierzugriff nur über einen Pico-Flex-Connector mit geeignetem Spezialadapter vorgesehen.
- Der lokale Zugriff ist ausschließlich für Entwicklung, Service oder autorisierte Eingriffe gedacht.
- Das Öffnen des Geräts darf nur durch geeignete und eingewiesene Personen erfolgen.

### 17.5 SD-OTA und Recovery

Mit einer SD-Karte kann ein vollständiges OTA-Bundle ohne Netzwerk eingespielt werden. Der Ablauf eignet sich für Upgrade, Downgrade und die Wiederherstellung einer unvollständigen Webapp.

SD-Karte vorbereiten:

- SD- oder SDHC-Karte mit FAT/FAT32 formatieren; für Service und OTA sind 4 bis 32 GB empfohlen.
- SDXC-Karten ab 64 GB funktionieren nur nach Formatierung als FAT32. Das übliche exFAT wird nicht unterstützt.
- Das vollständige .ota-Bundle in das Stammverzeichnis der Karte kopieren und die Karte vor dem Einschalten einstecken.
- Bei mehreren gültigen Bundles wählt das Gerät die höchste gefundene Version.

Startdialog:

- Nach dem Start erscheint bei einer passenden Datei für zehn Sekunden ein Dialog. „Start device“ setzt den normalen Start fort; die zweite Schaltfläche führt je nach Versionsstand Upgrade, Downgrade oder Recover aus.
- Während des Updates das Gerät nicht ausschalten und die SD-Karte nicht entfernen.

Downgrade-Sperre und Recovery:

- Nach drei übersprungenen Downgrades wird dasselbe Bundle bei gesunder Webapp nicht mehr angeboten. Zum erneuten Anbieten die Datei /SVA_OTA_DISMISSED.txt im SD-Stammverzeichnis löschen.
- /SVA_OTA_APPLIED.txt wird nach erfolgreicher Installation angelegt und verhindert erneute Angebote für dieselbe oder eine ältere Version auf demselben Gerät.
- Die leere Datei /SVA_OTA_FORCE.txt erzwingt einmalig die Anwendung eines gültigen Bundles ohne Dialog. Sie wird vor dem Updateversuch gelöscht.

Ausführliche Service- und Recovery-Hinweise stehen im öffentlichen Projektportal unter docs/manuals/sd_ota_recovery.md.

### 18. Pflege, Reinigung, Wartung und Lagerung

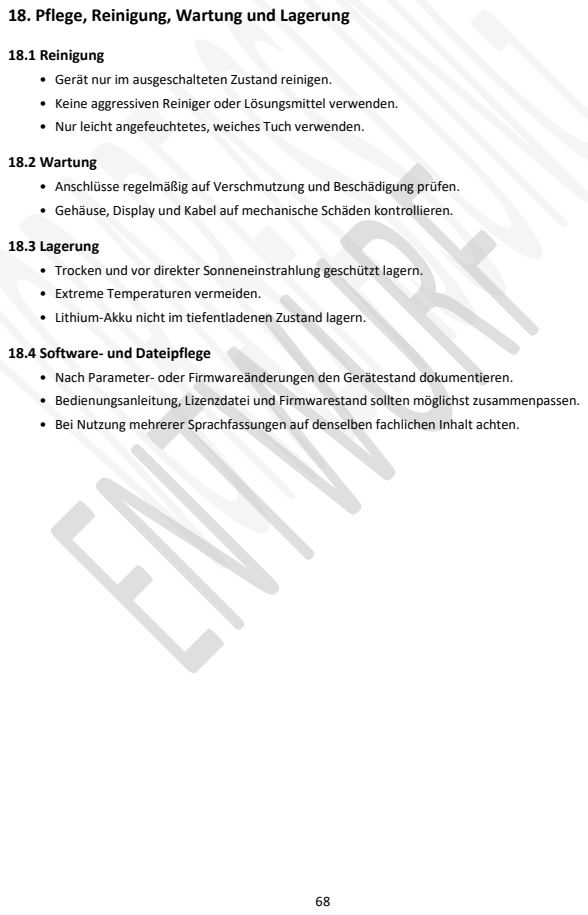
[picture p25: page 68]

18.1 Reinigung
• Gerät nur im ausgeschalteten Zustand reinigen.
• Keine aggressiven Reiniger oder Lösungsmittel verwenden.
• Nur leicht angefeuchtetes, weiches Tuch verwenden.

18.2 Wartung
• Anschlüsse regelmäßig auf Verschmutzung und Beschädigung prüfen.
• Gehäuse, Display und Kabel auf mechanische Schäden kontrollieren.

18.3 Lagerung
• Trocken und vor direkter Sonneneinstrahlung geschützt lagern.
• Extreme Temperaturen vermeiden.
• Lithium-Akku nicht im tiefentladenen Zustand lagern.

18.4 Software- und Dateipflege
• Nach Parameter- oder Firmwareänderungen den Gerätestand dokumentieren.
• Bedienungsanleitung, Lizenzdatei und Firmwarestand sollten möglichst zusammenpassen.
• Bei Nutzung mehrerer Sprachfassungen auf denselben fachlichen Inhalt achten.

### 19. Fehlersuche

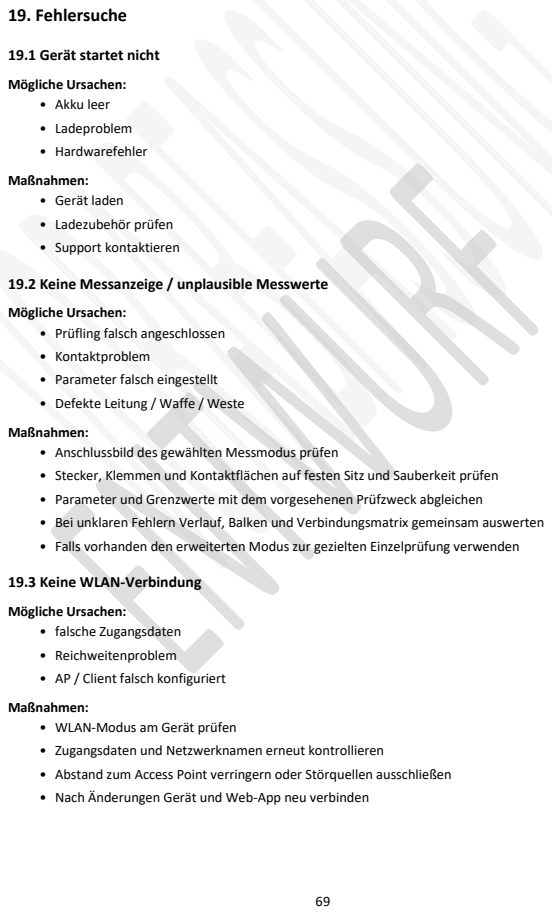
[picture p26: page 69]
Mögliche Ursachen: • Akku leer; • Ladeproblem; • Hardwarefehler; Maßnahmen: • Gerät laden; • Ladezubehör prüfen; • Support kontaktieren

19.1 Gerät startet nicht

19.2 Keine Messanzeige / unplausible Messwerte

Mögliche Ursachen:
• Prüfling falsch angeschlossen
• Kontaktproblem
• Parameter falsch eingestellt
• Defekte Leitung / Waffe / Weste

Maßnahmen:
• Anschlussbild des gewählten Messmodus prüfen
• Stecker, Klemmen und Kontaktflächen auf festen Sitz und Sauberkeit prüfen
• Parameter und Grenzwerte mit dem vorgesehenen Prüfzweck abgleichen
• Bei unklaren Fehlern Verlauf, Balken und Verbindungsmatrix gemeinsam auswerten
• Falls vorhanden den erweiterten Modus zur gezielten Einzelprüfung verwenden

19.3 Keine WLAN-Verbindung

• falsche Zugangsdaten
• Reichweitenproblem
• AP / Client falsch konfiguriert

• WLAN-Modus am Gerät prüfen
• Zugangsdaten und Netzwerknamen erneut kontrollieren
• Abstand zum Access Point verringern oder Störquellen ausschließen
• Nach Änderungen Gerät und Web-App neu verbinden

### 19.4 Web-App nicht erreichbar

Mögliche Ursachen:
- falsche IP-Adresse
- Browser-Cache
- Gerät noch nicht verbunden
- Netzwerkproblem

Maßnahmen:
- IP-Adresse oder Gerätenamen erneut prüfen
- Browser-Seite neu laden
- Bei Bedarf Browser-Cache leeren
- Prüfen, ob bereits ein anderer Client verbunden ist
- Netzwerkverbindung zwischen Gerät und Endgerät kontrollieren

### 20 FAQ und typische Praxisfragen

Warum zeigt ein Kabeltest nur beim Bewegen kurz „Schlecht“?

- Das ist ein typischer Hinweis auf Wackelkontakt, Kabelbruch, lockeren Stecker oder eine beschädigte Leitung.
- Im Chart zeigen sich solche Fehler meist als kurze Sprünge oder Aussetzer.
Warum bleibt die Vest-Anzeige nach dem Umsetzen kurz rot oder wird erst später neutral?
- Das gehört zum normalen automatischen Ablauf.
- Bei Verlust eines gültigen Kontakts bleibt das letzte fehlerhafte Ergebnis zunächst sichtbar.
- Erst nach einer kurzen Zeit ohne gültigen Durchgang wechselt die Anzeige in die neutrale Suchphase.
Wann ist ein kleiner Wert gut?
- Bei Durchgangsprüfungen ist ein kleiner Widerstand gut.
- Das bedeutet: die gewollte Verbindung leitet gut und hat nur wenig Übergangswiderstand. Wann ist ein großer Wert gut?
- Bei Isolationsprüfungen ist ein großer Widerstand gut.
- Das bedeutet: zwischen zwei eigentlich getrennten Leitungen besteht keine unerwünschte Verbindung.
Wie erkenne ich vertauschte Leitungen?
- Die erwarteten OK-Verbindungen erscheinen nicht an der vorgesehenen Stelle.
- In der Verbindungsmatrix tauchen stattdessen andere oder unerwartete Pfade auf.
- So lässt sich häufig schon ohne Öffnen des Kabels erkennen, dass Adern vertauscht wurden.

Was bedeutet Warnbereich?

- Der Messwert ist noch nicht eindeutig „Schlecht“, liegt aber nicht mehr sicher im guten Bereich.
- Bei einer Einstellung von z. B. 80 % gilt der Bereich bis 80 % der Fehlergrenze noch als unbedenklich.
- Ab dort beginnt der farbliche Übergang von grün zu gelb als Warnbereich.
- Das ist oft ein frühes Zeichen für Verschleiß, Oxidation, Schmutz oder beginnende Kontaktprobleme.
Ersetzt das Gerät eine offizielle Waffenabnahme?
- Nein.
- Das Gerät ist für technische Prüfung, Vorbereitung und Fehlersuche gedacht.
- Die formale sportliche Freigabe richtet sich immer nach dem gültigen Regelwerk und der offiziellen Kontrolle.
Wofür ist die Zusatzbuchse p gedacht?
- Über p können je nach Modus zusätzliche oder ergänzende Prüfungen erfolgen.
- Dazu gehören zum Beispiel zusätzliche Kontaktprüfungen an der Waffe oder ergänzende Prüfungen des Kontaktwegs.
Warum erscheint manchmal erst nach kurzer Zeit ein erstes Ergebnis?
- Besonders beim Vest-Test kann der erste gültige Messpunkt leicht verzögert erscheinen.
- Diese kurze Verzögerung dient der stabilen automatischen Erkennung eines gültigen Anschlusspaars.

Kapitel 20.1: Messverfahren und Strombegrenzung
Der SVA Fencing Tester arbeitet nach dem Prinzip der voll-ratiometrischen Synchronmessung über ein hochohmiges, digitales ADC-Frontend. Der exakte Widerstandswert der Fechtausrüstung (\(R_{x}\) wird rein mathematisch über das Spannungsverhältnis zu einem internen, temperaturstabilen Präzisions-Referenzwiderstand ermittelt. Durch dieses ratiometrische Verfahren kürzen sich bauteilbedingte Toleranzen, Halbleiter-Drifts und Schwankungen der Versorgungsspannung mathematisch vollständig aus, wodurch das Gerät dauerhaft kalibrierungsfrei operiert.

Zur optimalen und materialschonenden Simulation der realen Fechtbahn verfügt das Gerät über eine fest integrierte, hardwareseitige Begrenzung des Prüfstroms. Je nach Hardware-Revision und ausgewähltem Prüfprofil gelten folgende Parameter:

Der maximale Prüfstrom bei Kurzschluss (0 Ω) ist starr auf maximal 10 mA (40mA) begrenzt.

Hinweis: Die schaltungstechnische Implementierung der Strombegrenzung und die Filterung der internen Spannungsdomänen sind proprietär und verbleiben zum Schutz des geistigen Eigentums Closed Source.

### 21. Technische Daten

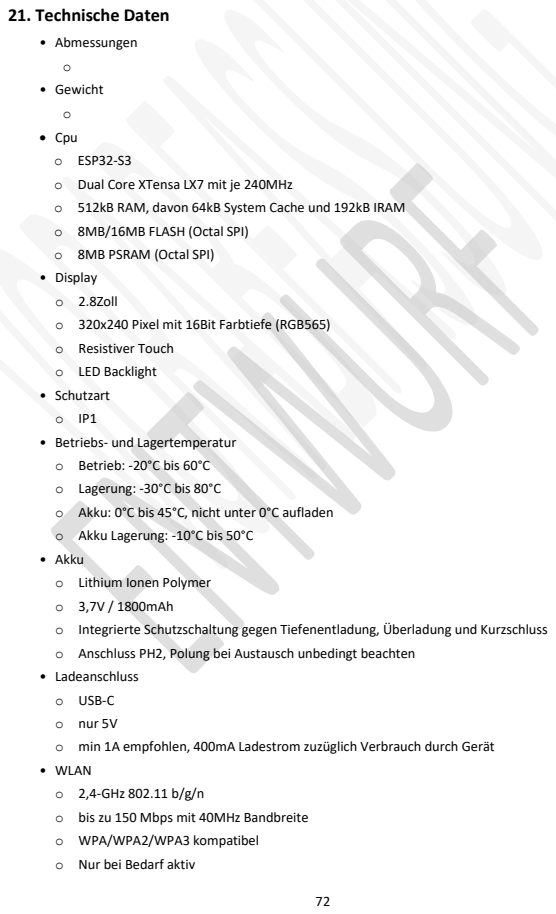
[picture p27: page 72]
• Abmessungen; o • Gewicht

• Cpu
• ESP32-S3
• Dual Core XTensa LX7 mit je 240MHz
• 512kB RAM, davon 64kB System Cache und 192kB IRAM
• 8MB/16MB FLASH (Octal SPI)
• 8MB PSRAM (Octal SPI)
• Display
• 2.8Zoll
• 320x240 Pixel mit 16Bit Farbtiefe (RGB565)
• Resistiver Touch
• LED Backlight
• Schutzart
• Betriebs- und Lagertemperatur
• Betrieb: -20°C bis 60°C
• Lagerung: -30°C bis 80°C
• Akku: 0°C bis 45°C, nicht unter 0°C aufladen
• Akku Lagerung: -10°C bis 50°C
• Akku
• Lithium Ionen Polymer
• 3,7V / 1800mAh
• Integrierte Schutzschaltung gegen Tiefenentladung, Überladung und Kurzschluss
• Anschluss PH2, Polung bei Austausch unbedingt beachten
• Ladeanschluss
• USB-C
• nur 5V
• min 1A empfohlen, 400mA Ladestrom zuzüglich Verbrauch durch Gerät
• WLAN
• 2,4-GHz 802.11 b/g/n
• bis zu 150 Mbps mit 40MHz Bandbreite
• WPA/WPA2/WPA3 kompatibel
• Nur bei Bedarf aktiv
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

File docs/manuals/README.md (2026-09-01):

# Handbücher

In diesem Ordner liegen ergänzende Anleitungen für Betrieb, Wiederherstellung und Versionsverwaltung.

- [Bedienungsanleitung (DE, Markdown)](./SVA-Fencing-Tester_manual_de.md) – aktuelle, öffentlich kommentierbare Vorabfassung.
- [Bedienungsanleitung (DE, PDF)](./SVA-Fencing-Tester_manual_de.pdf) – druckbare Vorabfassung; bis zur Finalisierung sichtbar als „VORABFASSUNG“ markiert.
- [SD-OTA-Recovery](./sd_ota_recovery.md) – Offline-Recovery und Update per SD-Karte.
- [Versionskonvention](./version_convention.md) – Aufbau der Firmware- und Build-Nummern.

Die reguläre Aktualisierung über die lokale Geräte-Webapp wird in der [Firmware-Update-Anleitung](../../bin/README.md) beschrieben.

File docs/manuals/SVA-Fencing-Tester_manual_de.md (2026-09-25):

# Bedienungsanleitung SVA-Fencing-Tester

> **VORABFASSUNG** – Diese Dokumentation befindet sich in Arbeit. Angaben zu Gehäuse, Bildern, Screenshots, finalem FIE-Preset und Compliance-Nachweisen werden mit den jeweiligen Freigaben ergänzt.

> Die Firmware und gerätespezifische Webapp sind proprietär. Verwendete Drittanbieter-Komponenten und ihre Lizenzen sind separat dokumentiert.

## 1. Über dieses Dokument

Diese Bedienungsanleitung beschreibt die sichere Inbetriebnahme, Bedienung und bestimmungsgemäße Verwendung des SVA-Fencing-Testers. Im Mittelpunkt steht die Bedienung direkt am Gerät. Zusätzlich wird beschrieben, wie das Gerät über eine Weboberfläche im Browser auf dem Smartphone, Tablet oder Computer angezeigt und bedient werden kann.

Zielgruppe:

- Anwender im Bereich Fechtsport, Service, Wartung und Prüftechnik
- Personen, die im Verein Leitungen (Körperkabel, Maskenkabel, Rollen), Waffen oder Westen prüfen.
### 1.1 Rechtlicher und organisatorischer Hinweis

Der SVA-Fencing-Tester ist ein privat und ehrenamtlich entwickeltes Non-Profit-Projekt zur gezielten Unterstützung des Fechtsports. Firmware und gerätespezifische Webapp sind urheberrechtlich geschützt und Closed Source; dieses öffentliche Portal veröffentlicht ausschließlich OTA-Updates, Handbücher, technische Hinweise und signierte Prüfparameter.

**Konformitätsstatus und beschränkte Überlassung:** Das Gerät ist derzeit nicht CE-gekennzeichnet. Für das fertige Endgerät liegen noch keine abgeschlossene RED-Konformitätsbewertung und kein abschließender EMV-Laborbericht vor. Nichtkommerzieller Zweck, geringe Stückzahl oder die Überlassung an Vereine begründen für sich allein keine pauschale Ausnahme von den geltenden Anforderungen.

Eine Überlassung erfolgt ausschließlich als kundenspezifisches Evaluierungskit an benannte Vereine mit sachkundiger, benannter Projektleitung. Der Verein führt die Endmontage selbst durch, einschließlich der eigenständigen Beschaffung und des Anschlusses eines geeigneten Akkus über den vorgesehenen Steckverbinder, und nutzt das Kit ausschließlich in einer dokumentierten Forschungs- und Entwicklungsumgebung zur Materialprüfung. Das Projekt kann eine technische Akkuempfehlung bereitstellen; der Akku ist nicht Bestandteil des Evaluierungskits. Das vermeidet Gefahrgutversand und hilft, die Bereitstellungs- und Beschaffungskosten für Vereine niedrig zu halten. Er darf nur unbeschädigt, ohne Gewalt und gemäß der Kit-Anleitung angeschlossen werden. Die Übergabe erfolgt in der Regel persönlich, sodass keine Versandverpackung anfällt. Diese Endmontage und Übergabeform ändern für sich allein weder die rechtliche Einordnung des Kits noch ersetzen sie die später erforderliche Konformitätsbewertung. Private Fechter erhalten keine Einheiten direkt, sondern ausschließlich über ihren Verein im Rahmen dieses dokumentierten Projekts. Das Kit ist nicht für Verbraucher, eine allgemeine Marktbereitstellung oder den regulären Vereinsbetrieb bestimmt. Erst nach Abschluss der erforderlichen Laborprüfungen und der Konformitätsbewertung kann eine andere Bereitstellung geprüft werden. Die technische Vorbereitung für die Laborprüfung ist abgeschlossen; bei kleiner Stückzahl liegen deren Kosten voraussichtlich etwa beim Vier- bis Fünffachen der Kosten von zehn Geräten. Eingehende Spenden oder Fördermittel werden vorrangig für diese EMV- und Funkprüfungen durch ein geeignetes Labor eingesetzt.

Hinweise zum Urheberrecht und Eigentumsschutz:

Die integrierte Firmware sowie die gerätespezifische Webapp sind geistiges Eigentum des Entwicklers und strikt Closed-Source.

Jede Form der unbefugten Vervielfältigung, Modifikation, Dekompilierung (Reverse Engineering) oder des unerlaubten Kopierens der Programmdaten ist ausdrücklich untersagt.

Das Produkt ist kein industriell seriengefertigtes Messgerät, sondern ein im privaten Ehrenamt entstandenes Werkzeug für die vereinsinterne Praxis.

Es wird nach bestem Wissen und Gewissen auf Basis jahrelanger praktischer Erfahrungen an der Planche bereitgestellt.

Die Nutzung des Geräts sowie die daraus abgeleiteten Reparaturentscheidungen erfolgen vollständig eigenverantwortlich durch den Anwender.

### 1.2 Hinweis zu Regelwerken und Grenzwerten

Der Tester unterstützt mit einem nicht am Gerät veränderbaren FIE-Preset die elektrische Materialprüfung anhand der vorgesehenen Prüfparameter. Aktualisierungen des Presets erfolgen kontrolliert über die Webapp; bei aktivem Preset zeigt das Gerät das FIE-Logo. Der Tester ist ein Materialtester, keine Meldeanlage und keine Trefferanzeige. Eine formale Aussage zur FIE-Konformität wird erst nach abgeschlossenem, separat dokumentiertem Nachweis veröffentlicht.

### 1.3 Garantie, Gewährleistung und Haftung

Sofern nicht zwingende gesetzliche Vorschriften etwas anderes verlangen, gilt:

- Es wird keine Garantie für bestimmte Eigenschaften, Verfügbarkeit oder Eignung für einen bestimmten Zweck übernommen.
- Es wird keine darüberhinausgehende Gewährleistungszusage abgegeben.
- Für direkte oder indirekte Schäden, Folgeschäden, Datenverlust, Fehlmessungen oder daraus abgeleitete Entscheidungen wird keine Haftung übernommen, soweit gesetzlich zulässig.
> **Wichtig:**

- Der Anwender bleibt für den sachgerechten Einsatz und die Bewertung der Messergebnisse verantwortlich.
- Das Gerät unterstützt die Prüfung, ersetzt aber nicht die fachliche Beurteilung des Anwenders.
### 1.4 Abkürzungen und Fachbegriffe

Dieses Kapitel erklärt wichtige Begriffe aus dem weiteren Verlauf der Bedienungsanleitung.

#### 1.4.1 Wichtige Abkürzungen

- ADC: Analog-to-Digital Converter (Analog-Digital-Wandler; integrierter Schaltkreis zur Umsetzung analoger Messspannungen in digitale Zahlenwerte).
- AP: Abkürzung für Access Point. Das Gerät stellt dabei selbst ein WLAN bereit.
- BMP: einfaches Bilddateiformat, hier genutzt für Bildschirmfotos von Geräteoberfläche.
- BOM: Bill of Materials (Stückliste; Verzeichnis aller elektronischen und mechanischen Bauteile, die für die Bestückung der Platine benötigt werden).
- CRA: Cyber Resilience Act (Europäische Cyberresilienz-Verordnung für Produkte mit digitalen Elementen).
- DHCP: automatische Vergabe der Netzwerkadresse.
- DSO: Daylight Saving Time (Sommerzeit; Status-Flag zur kosmetischen Zeitumstellung im Benutzerinterface, synchronisiert über den Browser).
- DST: automatische Vergabe der Netzwerkadresse.
- EMV: Elektromagnetische Verträglichkeit (Fähigkeit eines Apparates, in seiner elektromagnetischen Umwelt zufriedenstellend zu arbeiten, ohne selbst unzulässige Störungen zu verursachen).
- ESD: Electrostatic Discharge (Elektrostatische Entladung; hochenergetische Spannungsdurchschläge, die durch Schutzdioden direkt an den Buchsen abgefangen werden).
- FIE: Internationaler Fechtverband.
- FPU: Floating Point Unit (Gleitkommaeinheit; dedizierter mathematischer Co-Prozessor im Hauptchip zur schnellen Berechnung ratiometrischer Messwerte in Echtzeit).
- FRAM: Ferroelectric Random Access Memory (Ferroelektrischer Zufallsspeicher; extrem langlebiger, magnetischer Datenspeicher für verschleißfreie Sicherung der Live-Parameter).
- GND: Ground (Masse; das gemeinsame Bezugspotenzial der elektrischen Schaltung).
- Heap: Dynamischer Speicherbereich (Teil des RAMs, aus dem die Software zur Laufzeit flexibel Speicher für JSON-Objekte, Web-Clients oder temporäre Puffer anfordert).
- IP-Adresse: Zahlenadresse, unter der ein Gerät im Netzwerk erreichbar ist.
- I²C: Inter-Integrated Circuit (Serieller Datenbus zur internen Kommunikation zwischen dem Hauptprozessor, den Messwandlern und der Echtzeituhr).
- JSON: Dateiformat für gespeicherte Einstellungen und Konfigurationen.
- LittleFS: Little File System (Robustes, stromausfallsicheres Dateisystem im internen Speicher; dient zur Verwaltung der geräteunabhängigen Webapp-Dateien).
- mDNS: Aufruf eines Geräts über einen Namen statt über eine Zahlenadresse.
- MUX: Multiplexer (Elektronischer Umschalter, der die lastfreien Messspannungen hochohmig an die Wandlerstufen leitet).
- NOK: Not OK (Nicht in Ordnung; Fehlerzustand bei Grenzwertüberschreitung oder Signalabriss).
- NTP: Network Time Protocol (Netzwerkzeitprotokoll; wird in diesem System aufgrund der bewussten Offline-Architektur nicht verwendet).
- OTA: Firmware-Update über WLAN und Browser, ohne das Gerät zu öffnen.
- PCB: Printed Circuit Board (Leiterplatte / Platine; der mechanische Träger und elektrische Verbinder der elektronischen Bauteile).
- PGA: Programmable Gain Amplifier (Programmierbarer Signalverstärker; sorgt im ADC für die automatische, feinstufige Bereichsanpassung bei kleinsten Spannungen).
- PWM: Pulsweitenmodulation (Digitales Modulationsverfahren; steuert hier die stufenlose Lautstärke des Signalgebers sowie die Helligkeit des Bildschirms).
- PSRAM: Pseudo-Static Random Access Memory (Pseudostatischer Arbeitsspeicher; externer, über die SPI-Schnittstelle angebundener RAM-Speicher zur Bereitstellung des großen Display-Framebuffers).
- RAM: Random Access Memory (Flüchtiger Arbeitsspeicher; schneller Hauptspeicher des Mikrocontrollers für Programmdaten und Variablen, aufgeteilt in schnellen internen SRAM und externen PSRAM).
- RED: Radio Equipment Directive (Europäische Funkanlagenrichtlinie 2014/53/EU; regelt die Marktzulassung von Funkkomponenten).
- REST-API: Representational State Transfer Application Programming Interface (Schlanke Programmierschnittstelle; der einzige offene Netzwerk-Port zur sicheren Datenkommunikation).
- RTC: Real-Time Clock (Echtzeituhr; autarker, batteriegepufferter Uhrenbaustein zur exakten Zeithaltung).
- SPI: Serial Peripheral Interface (Serielle Peripherieschnittstelle; schneller, synchroner Datenbus zur hardwarenahen Ansteuerung des TFT-Displays und des PSRAMs).
- SPS: Samples Per Second (Messwerte pro Sekunde; Maßeinheit für die Abtastgeschwindigkeit der analogen Messstufen).
- SPIFFS: SPI Flash File System (Separiertes, geschütztes Dateisystem für benutzerdefinierte Konfigurationsdateien, Presets und Logos).
- SVG: Scalable Vector Graphics (Skalierbare Vektorgrafik; zweidimensionales Grafikformat zur gestochen scharfen, verlustfreien Darstellung der Messkurven auf dem Client-Bildschirm).
- TFT: Thin-Film Transistor (Flachbildschirmtechnologie; bezeichnet das integrierte 2,8"-Farbdisplay mit Touch-Funktion).
- THT: Through-Hole Technology (Durchsteckmontage; robuste Bauform für mechanisch stark beanspruchte Bauteile wie Stecker und Signalgeber).
- TVS: Transient Voltage Suppressor (Halbleiter-Schutzdiode zur schnellen Begrenzung gefährlicher Überspannungsspitzen).
- UX: User Experience (Benutzererfahrung bei der Bedienung des Geräts).
- UI: Benutzeroberfläche, also die sichtbare Bedienoberfläche am Gerät oder im Browser.
- WLAN: drahtlose Netzwerkverbindung.
#### 1.4.2 Wichtige Fachbegriffe

- Browser-Oberfläche oder Web-App: zusätzliche Anzeige- und Bedienoberfläche, die im Browser auf Handy, Tablet oder Computer geöffnet wird.
- Client Mode: Das Gerät verbindet sich mit einem bereits vorhandenen WLAN.
- Access Point Mode: Das Gerät stellt selbst ein eigenes WLAN bereit.
- Start: Bezeichnung der Startseite in der Geräte-UI.
- Durchgang: gewollte elektrische Verbindung.
- Isolation: Trennung zwischen Leitungen, die nicht miteinander verbunden sein sollen.
- Grenzwert: eingestellte Grenze, ab der ein Wert als kritisch bewertet wird.
- Warnbereich: Bereich vor der Fehlergrenze.
- Hold Mode: Anzeige bleibt kurz sichtbar, auch wenn der Zustand schon wieder verschwunden ist.
- Fading: kurzes Ausblenden einer zuvor sichtbaren Anzeige.
- Plot, Chart, Diagramm: grafische Darstellung eines Messwerts oder Messverlaufs. Im Manual wird häufig Chart für die Verlaufsanzeige verwendet.
- Trigger: Schalt- oder Auslösepunkt eines Kontakts.
- Prellen: mehrfaches kurzes Umschalten eines Kontakts statt eines sauberen einmaligen Schaltvorgangs.
- Werkseinstellungen: Rücksetzen gespeicherter Einstellungen.
- Neustart: manueller Neustart des Geräts.
### 1.5 Über den Tester, das Projekt und den SVA

Der SVA-Fencing-Tester wurde als möglichst günstiges und einfach zu bedienendes Gerät zum Prüfen von Kabeln, Waffen und weiterer elektrischer Fechtausstattung entwickelt.

#### 1.5.1 Entstehung und Ziel

- Ziel des Projekts ist eine praktische Hilfe für Vorbereitung, Wartung, Fehlersuche und vereinsnahe Prüfung im Fechtsport.
- Die Entwicklung, Fertigung, Programmierung und Wartung erfolgen ausschließlich privat und ehrenamtlich nach bestem Wissen und Gewissen.
- Firmware und Webapp sind proprietär und nicht quelloffen. Verwendete Drittanbieter-Komponenten und ihre Lizenzen sind separat dokumentiert.
- Der SVA-Fencing-Tester ist für private oder vereinsinterne Nutzung gedacht.
- Das Gerät ist nicht zertifiziert. Die Nutzung erfolgt eigenverantwortlich.
#### 1.5.2 Bug-Reports, Anregungen und Diskussion

- Probleme, Fehlerberichte und Anregungen können per E-Mail gemeldet werden an: info@sva-oranienburg.de
- Für allgemeine Diskussionen steht das öffentliche Projektportal auf GitHub zur Verfügung:
https://github.com/MiLasGeek/SVA-Fencing-Tester-Portal/discussions

- Das öffentliche Projektportal ist auf GitHub verfügbar:
https://github.com/MiLasGeek/SVA-Fencing-Tester-Portal

- Fehlerberichte und Verbesserungsvorschläge können über den Bug-Report eingereicht werden:
https://github.com/MiLasGeek/SVA-Fencing-Tester-Portal/issues/new/choose

- Sicherheitsrelevante Hinweise bitte nicht öffentlich melden, sondern gemäß Security-Hinweis vertraulich übermitteln:
https://github.com/MiLasGeek/SVA-Fencing-Tester-Portal/blob/main/SECURITY.md

- Compliance-Dokumentation befindet sich in Vorbereitung. Freigegebene Nachweise und der aktuelle Status werden im öffentlichen Projektportal veröffentlicht:
https://github.com/MiLasGeek/SVA-Fencing-Tester-Portal/tree/main/docs/compliance

#### 1.5.3 Über den SVA

- SVA-Oranienburg ist der Vereinsbezug des Projekts.
- Der SV Athletik Oranienburg ist ein Breitensportverein.
- Der SVA-Fencing-Tester ist im Umfeld der Abteilung Fechten entstanden.
- Informationen zum Verein sind verfügbar unter:
https://sva-oranienburg.de

> **Hinweis:**

- Die Inhalte der Seite Über in der Browser-Oberfläche fassen diese Hintergrundinformationen ebenfalls zusammen und verweisen zusätzlich auf Dokumentation, Lizenz und weitere Projektinformationen.
## 2. Allgemeine Gerätebeschreibung

Der SVA-Fencing-Tester ist ein mobiles Prüfgerät für Fechtsport-Komponenten. Das Gerät dient zum Prüfen von:

- Leitungsverbindungen im Wire Test
- Westen / Körperkleidung im Vest Test
- Waffen bzw. Waffenleitungen in den Waffentests
Das Gerät verfügt über:

- integriertes Display mit Touch-Bedienung
- eigene Geräte-Benutzeroberfläche
- WLAN-Funktion für die Verbindung mit einem vorhandenen WLAN oder für ein vom Gerät selbst bereitgestelltes WLAN
- zusätzliche Browser-Oberfläche für erweiterte Anzeige, Einstellungen und Firmware-Update
- integrierten Lithium-Akku
[Bild Gerät gesamt einfügen]

## 3. Bestimmungsgemäßer Gebrauch

Das Gerät ist ausschließlich für das Messen und Beurteilen von Fechtsport-bezogenen Verbindungen, Widerständen und Isolationen vorgesehen.

### 3.1 Zulässige Verwendungen

- Prüfen von Wire-Verbindungen
- Prüfen von Westen / leitfähiger Bekleidung
- Prüfen von Säbel-, Florett- und Degen-Komponenten bzw. deren Leitungswegen
- Parametrieren und Auswerten über die integrierte Bedienoberfläche oder die Web-App
### 3.2 Nicht zulässige Verwendungen

- Anschluss an Fremdspannungen
- Anschluss an Netzspannung
- Einsatz als allgemeines Multimeter oder Laborgerät
- Betrieb in explosionsgefährdeten Umgebungen
- Betrieb mit beschädigtem Gehäuse, Akku oder Anschlussleitungen
- Einsatz in sicherheitskritischen Anwendungen, in denen Fehlmessungen Personen oder Sachwerte gefährden können
### 3.3 Einschränkungen und Verantwortung des Anwenders

- Das Gerät ist kein zertifiziertes Sicherheitsgerät.
- Sofern nicht separat dokumentiert, besteht keine formale Kalibrier- oder Konformitätszusage.
- Messergebnisse sind stets im Kontext des Prüflings und der aktuellen Parametrierung zu bewerten.
- Vor jeder Freigabe eines Prüflings ist eine Plausibilitätsprüfung durch den Anwender sinnvoll.
## 4. Sicherheit und Warnhinweise

### 4.1 Allgemeine Sicherheitshinweise

- Das Gerät nur bestimmungsgemäß verwenden.
- Das Gerät vor jeder Benutzung auf sichtbare Beschädigungen prüfen.
- Beschädigte Geräte oder Leitungen nicht weiterverwenden.
- Das Gerät nicht öffnen, sofern dies nicht ausdrücklich für Servicezwecke vorgesehen ist.
### 4.2 Warnhinweis elektrische Sicherheit

> **Warnung:**

- Keine Fremdspannung an die Anschlüsse anlegen.
- Das Gerät ist nicht zum Messen externer Spannungsquellen bestimmt.
- Das Anlegen unzulässiger Spannungen kann zu elektrischem Schlag, Beschädigung des Geräts oder Brand führen.
### 4.3 Warnhinweis Brandgefahr / Überhitzung / Beschädigung

- Das Gerät nicht in der Nähe von Wärmequellen betreiben oder lagern.
- Keine öffentlichen oder verdeckten Lüftungs- bzw. Wärmeabgabebereiche blockieren.
- Das Gerät während des Ladevorgangs nicht abdecken.
- Nur freigegebene oder geeignete Lade- und Versorgungskomponenten verwenden.
### 4.4 Warnhinweis Lithium-Akku

Das Gerät enthält einen 3.7V / 1800mAh Lithium-Polymer-Akku.

Hinweise:

Allgemein: Akku nicht öffnen, zerlegen, quetschen oder verbrennen.

Sicherheit: Gerät nicht weiterbetreiben, wenn sich der Akku aufbläht, ungewöhnlich warm wird oder mechanisch beschädigt ist.

Laden: Das Gerät nicht unbeaufsichtigt in ungeeigneter Umgebung laden. Laden Sie den Akku niemals bei Umgebungstemperaturen unter 0 Grad C oder über 45 Grad C.

Langzeitlagerung: Bei längerer Nichtbenutzung sollte der Akku idealerweise bei einem Ladestand von ca. 40–60 % gelagert werden. Um eine schädliche Tiefentladung zu vermeiden, sollte das Gerät spätestens alle 6 Monate kurz nachgeladen werden.

Transport und Entsorgung: Die lokalen Vorschriften für Transport, Lagerung und Entsorgung von Lithium-Akkus beachten.

Kurzschlussschutz: Halten Sie das Gerät fern von leitenden Flüssigkeiten oder Metallgegenständen, die die internen Kontakte überbrücken könnten.

### 4.5 Umgebungsbedingungen

- Gerät vor Feuchtigkeit, Kondenswasser und direktem Regen schützen.
- Nur innerhalb der zulässigen Temperaturbereiche betreiben.
- Starke mechanische Belastungen, Stürze und Schlagbeanspruchung vermeiden.
Temperaturbereiche:

Betrieb (Ladebetrieb): 0 Grad C bis +45 Grad C (begrenzt durch Akku-Sicherheit).

Betrieb (reiner Entladebetrieb): -10 Grad C bis +60 Grad C (begrenzt durch Display-Spezifikation).

Lagerung: -20 Grad C bis +50 Grad C (empfohlen: +15 Grad C bis +25 Grad C bei ca. 50 % Akkuladung).

Schutz vor Strahlung: Setzen Sie das Gerät keiner dauerhaften direkten Sonneneinstrahlung aus. Die UV-Strahlung und die damit verbundene thermische Belastung können das TFT-Display dauerhaft schädigen (Kontrastverlust/Verfärbung) und den Akku überhitzen.

Feuchtigkeit und Kondensation: Das Gerät ist vor Feuchtigkeit, Spritzwasser und Regen zu schützen. Der Betrieb ist nur in nicht-kondensierender Umgebung zulässig. Bei starken Temperaturwechseln (z. B. Transport aus der Kälte in warme Räume) muss das Gerät vor der Inbetriebnahme die Umgebungstemperatur annehmen, um Kurzschlüsse durch Kondenswasser zu vermeiden.

Mechanische Einflüsse: Vermeiden Sie starke mechanische Belastungen, Stürze sowie Schlagbeanspruchungen, da diese insbesondere das Glas des TFT-Displays oder das Gehäuse des Lithium-Akkus beschädigen können.

### 4.6 Service und Eingriffe am Gerät

- Reparaturen, Umbauten oder Eingriffe im Inneren nur durch geeignete und eingewiesene Personen durchführen.
- Bei unsachgemäßen Eingriffen können Sicherheits- und Schutzfunktionen beeinträchtigt werden.
- Nach Gehäuseöffnung oder Reparatur sollte das Gerät vor dem weiteren Einsatz erneut geprüft werden.
### 4.7 Netzwerk- und Softwarehinweise

- Für die Verfügbarkeit von WLAN, Browsern, Endgeräten oder Netzwerkinfrastruktur kann keine Gewähr übernommen werden.
- Die Bedienung über Browser auf Handy, Tablet oder Computer ist eine Zusatzfunktion und keine Voraussetzung für die Grundbedienung am Gerät.
- Nach Firmware-Updates oder Konfigurationsänderungen kann ein erneutes Laden der Browser-Seite erforderlich sein.
- Das Firmware-Update über diese Browser-Oberfläche ist nur nach vorheriger Anmeldung zulässig.
- Der Updateweg für Firmware-Dateien ist ausschließlich für das vorgesehene Updateformat bestimmt.
- Ungeeignete oder unbefugte Updateversuche können zu Funktionsstörungen oder Beschädigungen führen.
## 5. Lieferumfang

- SVA-Fencing-Tester
Optionales Zubehör:

- Vesten-Prüfstift
- Erweiterung für die zweite Vest-Test-Variante
- Prüfkabel mit 4 mm-Stecker und Prüfspitze
Dieses Zubehör ist für Prüfungen über die Zusatzbuchse p erforderlich.

- Adapter 3-polig Stecker / 3-polig Stecker für die Rollenprüfung
Für die Rollenprüfung werden zwei dieser Adapter benötigt.

- Alternativ können für die Rollenprüfung auch zwei intakte Degen-Körperkabel verwendet werden.
Nicht im Lieferumfang:

- USB-C-Ladeadapter
- USB-C-Ladekabel
Hinweis zum Laden:

- Das Gerät ist mit handelsüblichem USB-C-Ladezubehör kompatibel.
- Besondere Anforderungen an das Ladezubehör bestehen nicht.
- Eine 5 V-Versorgung mit mindestens 400 mA ist ausreichend und wird durch übliches Zubehör in der Regel erfüllt.
Bei gleichzeitigem Betrieb des Gerätes sind mindestens 1A Stromabgabe empfehlenswert.

Den Akku nicht bei sehr niedrigen oder hohen Temperaturen laden.

## 6 Fechtausstattung und elektrischer Aufbau

Dieses Kapitel dient als kurze Einordnung der typischen elektrischen Fechtausstattung, die mit dem SVA-Fencing-Tester geprüft werden kann.

> **Hinweis:**

- Die genaue Ausführung einzelner Komponenten kann je nach Hersteller, Verband, Altersklasse und Einsatzbereich abweichen.
- Für die verbindliche sportliche Bewertung gelten die jeweils maßgeblichen Regelwerke und Prüfvorschriften.
### 6.1 Körperkabel und Rollen

#### 6.1.1 Maskenkabel

- Das Maskenkabel stellt die elektrische Verbindung zur leitfähigen Maske her.
An beiden Enden befindet sich eine Krokodilklemme.

- Es wird vor allem im Zusammenhang mit Florett- und Säbelausstattung relevant.
- Typische Fehler sind Unterbrechungen, Wackelkontakte und beschädigte Isolation.
#### 6.1.2 Körperkabel Florett

- Das Florett-Körperkabel verbindet Waffe und E-Veste mit der Rolle.
Auf der einen Seite befindet sich ein dreipoliger Stecker mit 4mm Stiften. auf der anderen Seite ein zweipoliger Stecker mit 4mm und 3mm Stift plus mechanischer Verriegelung am Florett, sowie eine Krokodilklemme zur E-Weste.

- Relevante Fehlerbilder sind vertauschte Leitungen, Übergangswiderstände, Wackelkontakte und Kurzschlüsse zwischen eigentlich getrennten Adern.
#### 6.1.3 Körperkabel Degen

- Das Degen-Körperkabel verbindet Waffe und Rolle.
An beiden Seiten befindet sich ein dreipoliger Stecker mit 4mm Stiften.

- Für die Prüfung sind besonders stabile Durchgänge und saubere Isolation zwischen den Adern wichtig.
#### 6.1.4 Körperkabel Säbel

- Das Säbel-Körperkabel überträgt die relevanten Signale zwischen Waffe, Rolle und leitfähiger Bekleidung.
Auf der einen Seite befindet sich ein dreipoliger Stecker mit 4mm Stiften. auf der anderen Seite ein zweipoliger Stecker mit 4mm und 3mm Stift plus mechanischer Verriegelung am Florett, sowie eine Krokodilklemme zur E-Weste.

- Neben Unterbrechungen sind hier auch fehlerhafte Querverbindungen und mechanisch belastete Steckerhäuser typische Fehlerquellen.
#### 6.1.5 Rolle

- Die Rolle dient als bewegliche Verbindungsstrecke zwischen Fechter und Anlage.
- Durch die mechanische Beanspruchung sind Kabelbruch, Wackelkontakt und wechselnde Übergangswiderstände besonders häufig.
- Deshalb ist die zeitliche Beobachtung im Chart hier besonders hilfreich.
### 6.2 Waffen: Säbel, Degen und Florett

#### 6.2.1 Säbel

- Beim Säbel sind leitfähige Waffe und Zielsystem relevant.
- Typisch geprüft werden Leitungsverbindungen, unerwünschte Querverbindungen und die elektrische Einbindung in die restliche Ausrüstung.
- Zusätzlich sind über die Zusatzleitung p weitere ergänzende Prüfungen möglich.
- Dabei lässt sich auch beurteilen, ob die Klinge elektrisch gut durchgängig ist und ob durch Oxidation oder schlechte Kontaktstellen ein erhöhter Übergangswiderstand entsteht.
#### 6.2.2 Florett

- Beim Florett spielt neben der Leitungsprüfung besonders die Spitze mit ihrer Kontaktauslösung eine Rolle.
- Zusätzlich sind die Verbindungen zur leitfähigen Weste und zur Maske relevant.
- Auch hier sind über die Zusatzleitung p weitere ergänzende Prüfungen möglich.
- Typisch geprüft werden die richtige Verdrahtung des Kontakts an der Spitze sowie der elektrische Kontakt der Spitze selbst.
#### 6.2.3 Degen

- Beim Degen ist die Spitzenauslösung ein zentrales Prüfmerkmal.
- Neben Leitungs- und Isolationsprüfung ist deshalb auch die Beobachtung von Schaltverhalten, Prellen und Triggerpunkt wichtig.
- Zusätzlich sind über die Zusatzleitung p weitere ergänzende Prüfungen möglich.
- Typisch geprüft werden der Kontakt der Spitze sowie die richtige Verdrahtung zur Glocke.
### 6.3 Spitze bei Degen und Florett

#### 6.3.1 Florettspitze

- Die Florettspitze muss sicher und reproduzierbar auslösen.
- Typische Fehler sind verschmutzte Kontakte, mechanisches Klemmen, Prellen oder eine zu schwache Feder.
- Für die sportliche Funktionsprüfung wird üblicherweise auch mit Prüfgewicht gearbeitet.
- Als typische Mindestkraft wird beim Florett 500 g genannt.
#### 6.3.2 Degenspitze

- Die Degenspitze muss ebenfalls sicher und reproduzierbar auslösen.
- Neben einer ausreichenden Federkraft ist hier auch der korrekte Auslöseweg wichtig.
- Typische Fehler sind Prellen, unruhiger Umschaltpunkt, mechanisch schwergängige Spitze oder eine zu schwache Feder.
- Als typische Mindestkraft wird beim Degen 750 g genannt.
- Zusätzlich ist beim Degen die Einhaltung des vorgesehenen Auslösewegs wichtig.
### 6.4 Prüfgewicht und typische Fehler

- Ein Prüfgewicht dient dazu, die notwendige Mindestkraft für die Kontaktauslösung zu kontrollieren.
- Löst die Spitze bereits unterhalb der geforderten Kraft aus, ist die Feder möglicherweise zu schwach oder die Mechanik fehlerhaft eingestellt.
- Löst die Spitze trotz ausreichender Kraft nicht sauber aus, sind Verschmutzung, falscher Hub, schwergängige Mechanik oder Kontaktprobleme möglich.
### 6.5 Elektrische Weste

#### 6.5.1 Elektrische Weste

- Die elektrische Weste stellt eine großflächige leitfähige Zielzone dar.
- Geprüft werden vor allem Leitfähigkeit, Übergangswiderstand und die Stabilität der Kontaktierung.
- Typische Fehler sind lokale Unterbrechungen, verschlissene Anschlussstellen, starke Widerstandserhöhung und ungleichmäßige Kontaktierung.
- Für die Prüfung sind zwei Varianten möglich.
- Variante 1: Anschluss an zwei beliebig gewählten Prüfpunkten der Weste.
- Variante 2: separater Vest-Anschluss mit zusätzlicher Farbanzeige und optionaler Vibrationsrückmeldung gemäß Konfiguration.
#### 6.5.2 Prüfstift für elektrische Westen

- Für elektrische Westen wird in der Praxis auch mit einem Prüfstift gearbeitet.
- Dieser dient dazu, die leitfähige Fläche unter definierten Bedingungen zu prüfen.
- Als typische genormte Prüfkraft werden hier 500 g verwendet.
- Eine Weste kann dabei lokal unauffällig erscheinen, an anderer Stelle aber bereits deutliche Kontaktprobleme zeigen.
- Deshalb ist eine Messung an mehreren Stellen der Weste sinnvoll.
## 7. Hinweis zu Normen und Grenzwerten

### 7.1 Hinweis zu FIE-Grenzwerten

- Für Fechtausstattung können je nach Einsatzbereich sportliche Vorgaben oder Grenzwerte nach Regelwerk relevant sein.
- Dazu können auch Anforderungen der FIE gehören. Das Gerät besitzt keine werkseitige FIE-Zertifizierung oder Konformitätserklärung.
- Eine technische Messung mit dem Gerät ersetzt nicht die formale Freigabe nach sportlichem Regelwerk.
### 7.2 Orientierung an typischen FIE-Vorgaben

- Bei Florett wird üblicherweise mit einer Mindestkraft von 500 g geprüft.
- Bei Degen wird üblicherweise mit einer Mindestkraft von 750 g geprüft.
- Als grobe Orientierung aus den FIE-Materialregeln gelten für den elektrischen Widerstand typischerweise maximal 2 Ω bei Florett und Degen sowie maximal 1 Ω bei Säbel.
7.3 Was das Gerät prüft

- Das Gerät prüft elektrische Durchgänge, Isolation, Übergangswiderstände, Kontaktverhalten und instabile Verbindungen.
- Es unterstützt Vorbereitung, Wartung, Fehlersuche und Vorprüfung der Fechtausstattung.
- Grenzwerte und Parameter müssen zum vorgesehenen Prüfzweck und dem aktuell geltenden Regelwerk passen.
### 7.4 Was das Gerät nicht ersetzt

- Das Gerät ersetzt keine offizielle Waffenabnahme auf Turnieren oder bei einer formalen Materialkontrolle.
- Für die verbindliche sportliche Zulassung sind die aktuelle Regelgrundlage, die offizielle Prüfung und die Entscheidungen der zuständigen Stellen maßgeblich.
### 7.5 Quelle der Orientierungswerte

- Die oben genannten Hinweise orientieren sich an den FIE-Materialregeln, Stand Dezember 2025.
- Maßgeblich ist immer die im Einsatzfall aktuell gültige Fassung des jeweiligen Regelwerks.
- Je nach Wettbewerb, Verband und Einsatzbereich können zusätzlich nationale Regelwerke, Materialvorschriften oder Ausschreibungen maßgeblich sein.
- Für Training, Vereinsbetrieb, nationale Turniere oder Verbandsabnahmen können daher andere oder ergänzende Anforderungen gelten als bei einer reinen Orientierung an der FIE.
- Offizielle FIE-Regelübersicht: https://fie.org/fie/documents/rules
- FIE Material Rules, Stand Dezember 2025: https://static.fie.org/uploads/38/190667-book%20m%20ang.pdf
- Weitere technische und ausrüstungsbezogene FIE-Dokumente: https://fie.org/fie/documents/equipment
## 8. Geräteübersicht und Anschlüsse

Dieser Abschnitt beschreibt die mechanischen und elektrischen Anschlüsse des Geräts.

8.1 Allgemeine Eigenschaften

- Das Gerät besitzt einen integrierten Touch-Bildschirm an der Vorderseite.
### 8.2 Vorderseite

- Display mit Touch-Bedienfläche
- Statusanzeigen / Symbole in der UI
- unterer Navigationsbereich für die Hauptseiten
- oberer Statusbereich mit Standby-Anzeige
- unterhalb des Displays die 1er- und 2er-Anschlüsse
- die Anordnung der Messanschlüsse ist an die Anzeige und die Verbindungsmatrix angelehnt
[Bild Vorderseite einfügen]

### 8.3 Rückseite / Seitenansichten

- USB-C-Buchse zum Laden/Betrieb
- Messanschlüsse für Leitungstest, Waffentest und Westentest
- SD-Kartenslot
- Ein-/Aus-Schalter
- vier Ladezustands-LEDs
[Bild Rückseite / Seitenansicht einfügen]

### 8.4 intern nur für Service und Entwicklung

- Service- und Programmieranschlüsse nur für Entwicklung / Service
- interner Reste Button, Boot Button (startet Screenshot zu SD-Karte), interner Button für Stromversorgungsmodul
Debug-Schnittstelle

### 8.5 Ladezustands-LEDs

- Das Gerät besitzt vier LEDs zur Anzeige des Ladezustands, ähnlich wie bei einer Powerbank.
- Im Ruhezustand können die LEDs aus sein.
- Bei Aktivität zeigen die LEDs den Ladezustand stufenweise an.
- Während des Ladens blinkt die Anzeige entsprechend dem aktuellen Ladestand.
### 8.6 Ruhezustand

- Das Gerät besitzt einen Ein-/Aus-Schalter.
- Zusätzlich arbeitet das Gerät mit einem automatischen Ruhezustand.
- Wenn das Gerät in den Ruhezustand gewechselt hat, muss der Power-Schalter aus- und wieder eingeschaltet werden, um das Gerät erneut zu starten.
### 8.7 SD-Karte

- Das Gerät besitzt einen SD-Kartenslot.
- Screenshots können auf die SD-Karte geschrieben werden.
- Später können möglicherweise weitere Funktionen wie zusätzliche Update- oder Serviceabläufe über die SD-Karte ergänzt werden.
### 8.8 Messanschlüsse

#### 8.8.1 Messkanäle

Die Firmware arbeitet intern mit acht Messkanälen:

- a1, b1, c1 (Kabeltest und Waffentest, kann bei Westentest genutzt werden)
- a2, b2, c2 (Kabeltest, kann bei Westentest genutzt werden)
- p (erweiterter Waffentest, kann bei Westentest genutzt werden)
- v (Westentest bei erweitertem Prüfstift)
#### 8.8.2 Bedeutung der internen Kanalgruppen

- a1, b1, c1 und a2, b2, c2 bilden die sechs Hauptmesskanäle für Leitungstest und Waffentest, sowohl zu Durchgangsprüfungen als auch zu Isolationsprüfungen.
- p ist ein zusätzlicher Prüf- bzw. Hilfskanal, der in den Waffentests verwendet wird.
- v ist dem zusätzlichen Prüfstift-Anschluss für den Westen-Test zugeordnet und ist für die normale Benutzerbedienung nicht weiter relevant.
Für den Westentest mit dem einfachen Prüfstift können zwei frei wählbare Anschlüsse genutzt werden.

#### 8.8.3 Physischer Aufbau der Anschlüsse

- a1: eine 4 mm-Buchse
- b1: eine 4 mm-Buchse
- c1: eine 4 mm-Buchse und zusätzlich ein Terminal für eine Klemme
- a1, b1 und c1 sind so angeordnet, dass ein 3-poliger Stecker passt
- a2: zwei 4 mm-Buchsen
- b2: eine 4 mm-Buchse und eine 3 mm-Buchse
- c2: eine 4 mm-Buchse und zusätzlich ein Terminal für eine Klemme
- a2, b2 und c2 sind so angeordnet, dass entweder ein 3-poliger Stecker oder ein 2-poliger Waffenstecker mit Aussparung für die mechanische Verriegelung passt
- p: separate 4 mm-Buchse
#### 8.8.4 Benutzerorientierte Zuordnung nach Messfunktion

- Wire Test: nutzt in erster Linie die drei Kanalpaare a1-a2, b1-b2 und c1-c2.
- Sabre Test: nutzt die Kanäle a1, b1, c1, c2 sowie den Zusatzkanal p.
- Foil Test: nutzt die Kanäle a1, b1, c1, c2 sowie den Zusatzkanal p.
- Epee Test: nutzt die Kanäle a1, b1, c1 sowie den Zusatzkanal p.
- Vest Test: prüft die Verbindung mit mehreren möglichen Kanalpaaren und kann dadurch unterschiedliche Anschlussbilder erkennen.
#### 8.8.5 Praktische Anschlussregel

- Generell wird das Kabel an die 1er-Seite angeschlossen.
- Bei Waffentests erfolgt der Anschluss des Prüflings bzw. der Waffe auf der Gegenseite passend zum Testaufbau.
- Bei Kabeltests erfolgt der Gegenanschluss auf der 2er-Seite.
#### 8.8.6 Typische Anschlussbilder

- Maskenkabel: Prüfung an den beiden c-Terminals, also zwischen c1 und c2
- Körperkabel 3-polig auf 3-polig: Anschluss auf 1er-Seite zu 2er-Seite
- Körperkabel 3-polig auf 2-polig: Anschluss 3-polig auf der einen Seite und 2-polig auf der anderen Seite; für die Westenverbindung wird zusätzlich das c2-Terminal mit Klemme verwendet
#### 8.8.7 Zuordnung im Wire Test

- a1-a2, b1-b2, c1-c2 werden als eigentliche Leitungsverbindungen bewertet.
- Zwischen denselben Kanälen sowie zwischen gemischten Paaren werden zusätzlich Isolations- und Fehlverbindungen geprüft.
- Im erweiterten Drahttest können einzelne Kanäle oder gültige Kanalpaare gezielt ausgewählt werden.
#### 8.8.8 Zuordnung in den Waffentests

- Sabre bewertet primär eine Hauptverbindung zwischen a1-b1, eine weitere Leitungsverbindung auf c1-c2 sowie Isolationen gegen andere Kanäle.
- Foil bewertet primär die Hauptverbindung a1-b1, die Leitungsverbindung c1-c2, mehrere Isolationspfade und den Zusatzkanal p.
- Epee bewertet primär die Hauptverbindung b1-c1, zusätzliche Isolationspfade sowie den Zusatzkanal p.
- Bei Foil und Epee existiert zusätzlich ein Trigger-Untermodus für die Auslösebetrachtung.
#### 8.8.9 Zuordnung im Vest Test

- Der Vest-Test versucht nicht nur ein einziges festes Kanalpaar, sondern prüft mehrere mögliche Kombinationen.
- Dadurch kann die Firmware verschiedene gültige Anschlussvarianten erkennen.
- Bevorzugt werden Verbindungen über v-p, danach folgen weitere Kombinationen unter Einbeziehung von c1, c2, a1, b1, a2, b2 und p.
## 9. Stromversorgung

### 9.1 Allgemeines

- Die Stromversorgung kann über einen internen Lithium Akku erfolgen.
Die Akkulaufzeit beträgt ca. 3 bis 4 Stunden und kann je nach Messaufgabe variieren. Der Betrieb mit aktivem WLAN kann die Akkulaufzeit je nach Nutzung und Empfangssituation auch deutlich verringern.

- Das Laden des internen Akkus erfolgt über eine USB-C-Buchse, die Ladezeit beträgt dabei bis zu 5 Stunden, 15 bis 80% in ca. 3 Stunden.
Die Aufladung des internen Akkus erfolgt auch im Schalterzustand Aus.

Über die USB-C Buchse kann das Gerät sowohl geladen als auch betrieben werden.

- Die USB-C-Buchse dient nur der 5V Versorgung zum Laden. Die Stromaufnahme des Gerätes bis zu 600mA Betrieb (Spitzenwert mit aktivem WLAN) und 400mA beim Laden.
Wird die USB-Versorgung abgeschaltet, geht das Gerät kurz aus und startet anschließend neu, intern wird von externer Versorgung mit Akku Laden auf interne Versorgung gewechselt.

USB-C Spezification: 5V / 1A

- Es besteht kein Support für USB-Datenübertragung.
- USB Power Delivery wird nicht unterstützt.
Es kann kein anderes Gerät mit Strom versorgt werden.

### 9.2 Laden

[Ladeanschluss und zulässige Ladespezifikation ergänzen]

Hinweise:

- Nur mit geeigneter Stromquelle laden.
- Ladegerät und Kabel auf Beschädigungen prüfen.
Ladegeräte die an das Stromnetz angeschlossen werden, z.B. über Steckdose, müssen Schutzisoliert sein.

USB-C Versorgung wird nur mit 5V unterstützt, Power Delivery mit mehr als 5V kann das Gerät beschädigen oder zu Überhitzung und Brand führen.

- Bei ungewöhnlicher Erwärmung den Ladevorgang sofort abbrechen.
- Integrierter Lithium-Akku 3.7V/1800mAh.
- Maximaler Ladestrom ca. 400 mA.
Das Gerät kann nicht als Stromversorgung für andere Geräte genutzt werden.

### 9.3 Akkubetrieb

- Akkustand vor langen Messreihen prüfen.
- Bei niedrigem Akkustand kann die Messdauer eingeschränkt sein.
Zur Erhöhung der Laufzeit kann eine externe handelsübliche Powerbank genutzt werden.

- Gerät bei längerer Nichtbenutzung gemäß Wartungs- und Lagerhinweisen aufbewahren.
### 9.4 Lagerung und Transport des Akkus

- Das Gerät nicht in heißer Umgebung oder in direkter Sonneneinstrahlung im Fahrzeug lagern.
- Für längere Lagerung ist ein moderater Ladezustand des Akkus sinnvoll.
- Beim Versand oder Transport sind die geltenden Vorschriften für Lithium-Akkus zu beachten.
## 10. Inbetriebnahme

### 10.1 Erstinbetriebnahme

1. Gerät auf äußere Beschädigungen prüfen.

2. Gerät ggf. vollständig laden.

3. Gerät einschalten.

4. Das Gerät zeigt einen Startbildschirm und wechselt zu Grundansicht.

5. Grundfunktionen am Display prüfen.

6. Messanschlüsse immer nur im spannungsfreien und vorgesehenen Zustand verbinden. Niemals Fremdspannung anschließen.

### 10.2 Startverhalten

Nach dem Einschalten startet das Gerät die Firmware, initialisiert Display, Touch, Messlogik und die konfigurierten Schnittstellen.

Typischer Ablauf:

1. Startanzeige mit Gerätename und Logo.

2. Initialisierung der internen Funktionen.

3. Wechsel zur Hauptoberfläche.

4. Anzeige der Startseite mit Uhr.

Hinweise:

- Während eines aktiven Firmware-Updates ist die normale Touch-Bedienung gesperrt.
- WLAN-Funktionen stehen erst nach abgeschlossener Initialisierung und gemäß eingestelltem WLAN-Modus zur Verfügung.
- Nach einem Neustart infolge von OTA, Konfigurationsimport oder Werksreset muss das Gerät erst wieder vollständig hochfahren, bevor Messung und Browser Oberfläche verfügbar sind.
## 11. Geräte-UI und Bedienung

Die Bedienung erfolgt grundsätzlich über das integrierte Display mit Touch-Funktion.

### 11.1 Startbildschirm / Start

- Uhrdarstellung in digitaler oder analoger Form, einfacher Wechsel durch Antippen auf die Uhrzeit
- halb Transparente Standby-Anzeige als Fortschrittsbalken in der Zeile am oberen Bildschirmrand
- direkte Navigation zu allen Hauptmodi über die untere Buttonleiste oder Wischen nach links oder rechts, dabei wird zyklisch entsprechend der Slide Richtung der entsprechende Modus aufgerufen
- Zugang zu den Parametern (Touch auf Schaltfläche, Wischen nach unten auf der linken Bildschirmhälfte)
Wechsel zur Infoseite (Button, Wischen nach unten auf der rechten Bildschirmhälfte)

Wechsel zum WLAN (Touch auf WLAN-Symbole in der Zeile am oberen Bildschirmrand)

- schneller Wechsel zur Zeiteinstellung (Wischen nach oben) oder langes Antippen der Uhrzeit

<p align="center">
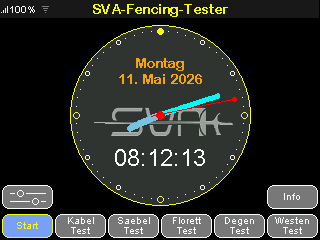
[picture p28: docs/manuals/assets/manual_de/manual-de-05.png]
  
</p>

<p align="center">
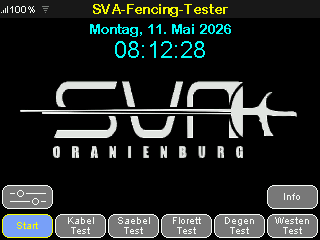
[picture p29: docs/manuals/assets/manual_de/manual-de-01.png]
  
</p>

### 11.2 Testmodi

Verfügbare Hauptmodi:

- Kabeltest mit erweitertem Untermodus
- Säbel-Test
- Florett-Test mit erweitertem Untermodus
- Degen-Test mit erweitertem Untermodus
- Westentest
### 11.3 Bedienkonzept

#### 11.3.1 Allgemeiner Aufbau

- Die Geräte-UI ist in Hauptseiten und zugehörige Einstellseiten gegliedert.
- Die Hauptseiten sind Start, Kabeltest, Säbel-Test, Florett-Test, Degen-Test und Westentest.
- Die untere Schaltflächenleiste dient auf den Hauptseiten als Direktwahl zur entsprechenden Seite.
- In Einstellseiten dient die untere Leiste zum Wechsel zwischen den Einstellgruppen und zur Rückkehr.
<p align="center">
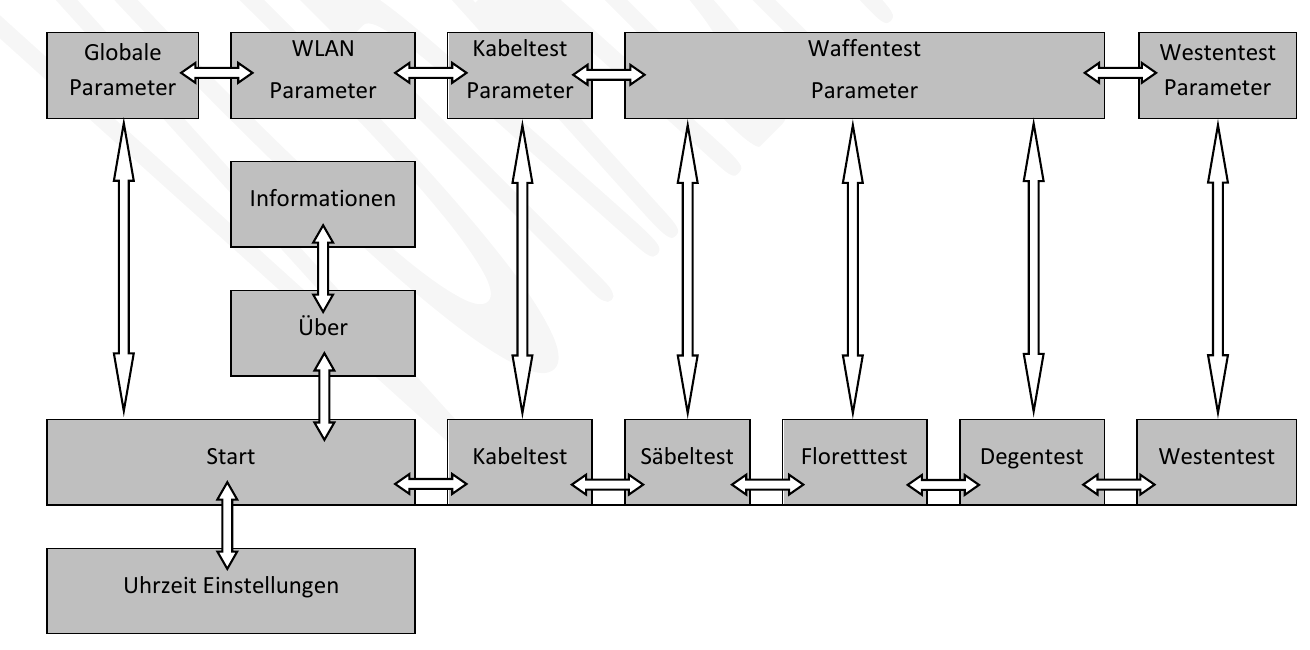
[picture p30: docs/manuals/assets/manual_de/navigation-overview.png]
Navigationsübersicht der Geräte-UI
  
</p>

#### 11.3.2 Hinweis zur Wisch-Logik

- Die Dokumentation beschreibt die Richtung der sichtbaren Seitenanimation.
- Welche Zielseite sich dabei öffnet, hängt vom aktuellen Bildschirm und vom jeweiligen Navigationskontext ab.
#### 11.3.3 Navigation am Gerät

- Wischen nach links oder Wischen nach rechts wechselt zwischen den Seiten einer Ebene.
- Auf den Hauptseiten wechselt die horizontale Wischgeste zwischen Start, Kabel, Säbel, Florett, Degen und Westen.
- Auf den Einstellseiten wechselt die horizontale Wischgeste zwischen Globale, WLAN, Kabel, Waffen und Westen.
- Wischen nach unten oder oben wechselt vertikal zwischen logisch übereinanderliegenden Seiten.
- Auf der Startseite öffnet Wischen nach unten auf der rechten Bildschirmseite die allgemeinen Parameter oder WLAN, wenn von der obersten Zeile aus gewischt wurde und die Information auf der linken Bildschirmseite.
- Auf der Startseite öffnet Wischen nach oben die Zeiteinstellung.
- Die Wischrichtung beschreibt dabei die sichtbare Animationsrichtung der eingeblendeten Zielseite.
- Entsprechend bedeutet Wischen nach unten, dass die neu geöffnete Seite mit einer Bewegung nach unten eingeblendet wird.
- Gleiches gilt für Wischen nach links oder rechts: Die Zielseite bewegt sich sichtbar in diese Richtung.
- Der Seitenwechsel ist zyklisch aufgebaut. Damit ist auch ein direkter Wechsel vom letzten zum ersten Eintrag bzw. vom ersten zum letzten Eintrag möglich.
#### 11.3.4 Schaltflächen und Schnellbereiche

- Die untere Schaltflächenleiste dient als sichtbare Direktnavigation.
- Ein Antippen des aktuell bereits aktiven Modus kann einen Untermodus öffnen oder umschalten.
- Der kleine Bereich oben links bei den WLAN-Symbolen dient als Schnellzugriff auf die WLAN-Seite.
- In den Testseiten öffnet ein langes Antippen der Testseite die passende Einstellseite.
#### 11.3.5 Sprachwechsel

- Die Sprache kann direkt am Gerät in den allgemeinen Einstellungen geändert werden.
- Der Sprachwechsel schaltet die UI zyklisch durch die verfügbaren Sprachen.
- Parallel kann die Sprache auch über die Web-App umgestellt und auf das Gerät übernommen werden.
#### 11.3.6 Zeitbedienung

- Auf der Startseite kann zwischen analoger und digitaler Uhr umgeschaltet werden.
- Die Zeiteinstellung ist sowohl über die Geräte-UI als auch über die Web-App erreichbar.
#### 11.3.7 Abschalt-Indikator am Gerät

- Am oberen Bildschirmrand zeigt ein transparenter horizontaler Balken die verbleibende Zeit bis zum Abschalten (Standby).
- Ist Standby = „Nie“ eingestellt, so ist der Balken nicht sichtbar.
- Ist die Zeit ohne Bedienung oder Prüfung abgelaufen, schaltet sich das Gerät ab.
- Das Gerät wacht danach nicht durch Berührung oder andere Aktivität wieder auf.
- Für den erneuten Betrieb muss das Gerät am Power-Schalter aus- und wieder eingeschaltet werden.
## 12. Messabläufe

### 12.1 Grundlagen zum Verständnis der Messanzeigen

Die folgenden Grundlagen helfen beim Verstehen aller Messmodi. Sie gelten für die Anzeige am Gerät und sinngemäß auch für die Browser Oberfläche.

#### 12.1.1 Was sagt der Ohm-Wert aus

- Ohm ist die Einheit für elektrischen Widerstand.
- Ein kleiner Ohm-Wert bedeutet: Strom kann gut fließen, die Verbindung ist leitfähig.
- Ein großer Ohm-Wert bedeutet: Strom kann schlecht oder praktisch gar nicht fließen.
- Für gewollte Verbindungen ist deshalb ein kleiner Wert gut.
- Für unerwünschte Verbindungen ist ein großer Wert gut.
Ω ist das Symbol für Ohm

#### 12.1.2 Ohm, kOhm und was der Wert bedeutet

Ohm und kOhm für technische Laien:

- 1 Ohm oder 1Ω ist ein kleiner Widerstand.
- 1000Ω sind 1 kΩ oder 1kOhm.
1000000Ω oder 1000kΩ sind ein MΩ

- Wenn das Gerät bei einem Soll-Durchgang wenige Ω anzeigt, ist das meistens gut.
- Wenn das Gerät bei einer Isolationsmessung sehr große Werte oder Werte im kΩ - bis MΩ-Bereich zeigt, ist das meistens gut.
- Anders gesagt: Bei Durchgang will man klein, bei Isolation will man groß.
### 12.2 Durchgang und Isolation

Der SVA-Fencing-Tester beurteilt Leitungen und Kontakte im Wesentlichen mit zwei Grundaufgaben:

- Durchgangsprüfung: Es wird geprüft, ob zwei Punkte elektrisch verbunden sein sollen und ob diese gewollte Verbindung gut ist.
- Isolationsprüfung: Es wird geprüft, ob zwei Punkte elektrisch gerade nicht verbunden sein sollen und ob trotzdem eine ungewünschte Verbindung besteht.
#### 12.2.1 Durchgangsprüfung

- Eine gewollte Verbindung soll möglichst wenig elektrischen Widerstand haben.
- Ein kleiner Widerstandswert ist hier gut.
- Typische Ursachen für zu hohe Werte sind verschmutzte Kontakte, lockere Stecker, gealterte Verbindungen oder ein beginnender Kabelbruch.
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

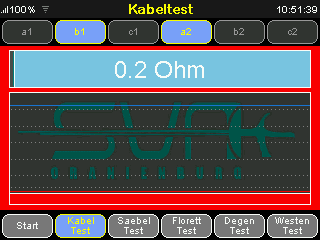
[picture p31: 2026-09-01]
docs/manuals/assets/manual_de/manual-de-14.png

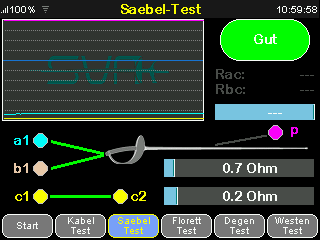
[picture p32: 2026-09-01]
docs/manuals/assets/manual_de/manual-de-02.png

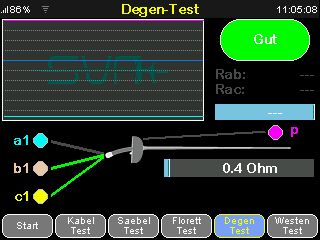
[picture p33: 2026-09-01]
docs/manuals/assets/manual_de/manual-de-08.png

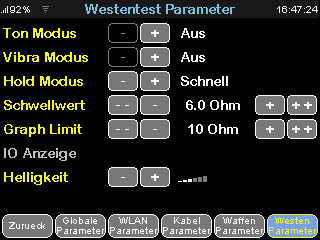
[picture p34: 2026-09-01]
docs/manuals/assets/manual_de/manual-de-04.png

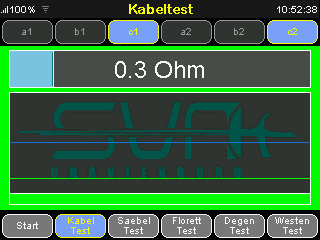
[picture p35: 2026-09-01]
docs/manuals/assets/manual_de/manual-de-11.png

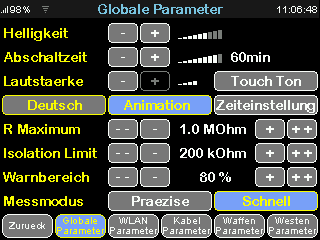
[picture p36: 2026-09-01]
docs/manuals/assets/manual_de/manual-de-03.png

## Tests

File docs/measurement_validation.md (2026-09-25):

# Messvalidierung und Genauigkeit

## Zweck

Der SVA-Fencing-Tester ist ein Materialtester für Fechtausrüstung. Er ist keine
Meldeanlage und ersetzt keine formale Materialabnahme durch die zuständigen
Stellen. Die technische Messvalidierung dokumentiert die Eignung der Messkette
für den vorgesehenen Prüfzweck; sie ist keine FIE-Zertifizierung.

## FIE-Einordnung des Materialtesters

Die [FIE Material Rules, Ausgabe Dezember 2025](https://static.fie.org/uploads/38/190667-book%20m%20ang.pdf)
nennen als homologationspflichtig Klingen, Spitzen, Schutzkleidung einschließlich
Masken und Handschuhen, Meldeanlagen, Planchen, Video-Refereeing-Systeme und
Wettkampfsoftware. Ein eigenständiger Materialtester zur Diagnose von
Fechtausrüstung ist dort nicht aufgeführt. Daraus folgt für diesen Tester keine
Behauptung einer FIE-Homologation und kein Recht zur Nutzung des FIE-Emblems.

Diese Einordnung bezieht sich ausschließlich auf die genannte, datierte
Regelversion. Die FIE kann den Anwendungsbereich erweitern; außerdem können
Veranstalter, nationale Verbände oder Prüfstellen weitergehende Anforderungen
an ein vor Ort verwendetes Prüfmittel stellen.

### Einsatz vor einem Turnier

Als Vorabprüfung durch Verein oder Fechter kann der Tester helfen, Widerstand,
Anschlussfehler und den Zusammenbau vor der Materialkontrolle zu erkennen und
rechtzeitig zu beheben. Er ersetzt nicht die offizielle Abnahme. Für offizielle
FIE-Wettbewerbe bestimmt der Veranstalter das Prüfpersonal; die Materialregeln
verlangen dort unter anderem ein elektrisches Prüfgerät für Widerstand und den
korrekten Zusammenbau (m.42). Die Entscheidung über Zulassung und die
Kennzeichnung geprüfter Ausrüstung verbleiben bei der zuständigen
Materialkontrolle.

Die Sichtkontrolle und die fachliche Gesamtbeurteilung bleiben dabei stets
Aufgabe der zuständigen Prüferperson. Der Tester ist ein Prüfmittel: Er liefert
elektrische Messwerte, eine verständliche Fehleranzeige und dokumentierbare
Hinweise, trifft jedoch keine verbindliche Abnahmeentscheidung und kennzeichnet
keine Ausrüstung als zugelassen.

## Messprinzip

Die Widerstandsmessung verwendet eine ratiometrische Vierleiter-
Vergleichsmessung nach dem Newton-Brücken-Prinzip. Der Messwert wird gegen einen
temperaturstabilen Präzisions-Referenzwiderstand bestimmt. Die tatsächliche
Referenz und die R0-Brückenkompensation werden bei der Geräteprovisionierung
ermittelt und für das jeweilige Gerät dokumentiert.

R0 gleicht den gerätespezifischen Widerstandsanteil von Buchsen und
Messbrücke im Bereich von etwa 0,1 Ohm ab. Dieser Abgleich verändert nicht die
Auflösung der Messung. Er bleibt normalerweise stabil und wird insbesondere bei
auffälligem Verschleiß oder einer Beschädigung der Gerätebuchsen erneut geprüft.
Der Buchsen- und Kontaktanteil ist bei einer realen Anschlussmessung physisch
unvermeidbar; die R0-Kompensation macht ihn nachvollziehbar, statt ihn dem
Prüfling als Messfehler zuzuordnen.

Bei den ersten Testgeräten lag die beobachtete Streuung dieses Anteils im
Bereich von rund 70 mOhm. Dieser Vorserienbefund wird bei weiteren Geräten
fortgeschrieben; er ist kein zugesicherter Maximalwert für jede Hardware-
Revision oder jeden Buchsenzustand.

R0 ist ein systematischer Offset und begrenzt nicht die Messauflösung. Ein
solcher Nullpunktabgleich könnte rechnerisch oder als Tara erfolgen; die
gerätespezifisch dokumentierte R0-Kompensation macht den Abgleich jedoch
nachvollziehbar und überprüfbar. Für eine bestimmte FIE-Regelversion wird die
erforderliche Messauflösung jeweils gegen die datierte Regelreferenz und den
dokumentierten Messnachweis abgeglichen.

## R0-Abgleich bei der Inhouse-Provisionierung

Der R0-Abgleich wird je Gerät aus einer Messreihe mit 299 Samples bestimmt.
Währenddessen werden die Min-/Max-Spanne und die Standardabweichung überwacht.
So lassen sich Ausreißer, instabile Kontakte oder ein auffälliger Messaufbau
vor der Freigabe erkennen. Die vollständige Messreihe einschließlich der
bewerteten Kennwerte wird in der Datei-Datenbank zur Seriennummer des Geräts
abgelegt. Damit bleiben R0-Wert und zugrundeliegender Messnachweis für Wartung,
erneute Prüfung und Ursachenanalyse zuordenbar.

Nur wenn alle festgelegten Qualitätsgrenzen eingehalten sind, wird der Median
dieser Reihe als R0 übernommen. Bei 299, also einer ungeraden Zahl von Samples,
ist dieser Median ein tatsächlich erfasster Rohmesswert (Raw Count) und kein
interpolierter Zwischenwert.

Der Widerstand der verwendeten Testbrücke wird bei der Auswertung berücksichtigt
und ebenfalls als gerätespezifischer Parameter gespeichert. Zusammen mit R0,
den Qualitätskennwerten und der vollständigen Messreihe bleibt damit der
jeweilige Abgleich zur Seriennummer nachvollziehbar.

**Veranschaulichung:** Hätte die Testbrücke einen bekannten Widerstand von
0,2 Ohm, könnte ein noch nicht korrigierter Systemoffset beispielhaft eine
Anzeige von 0,8 Ohm verursachen. Nach dem Abgleich wird für diese Brücke
entsprechend 0,2 Ohm angezeigt. Die Zahlen sind zur Erklärung absichtlich
überhöht: Die Bedienoberfläche löst im regulären Prüfmodus in Schritten von
0,1 Ohm auf.

Intern werden Messwerte weder gefiltert noch für die weitere Verarbeitung
gerundet; sie bleiben mit voller Float-Auflösung erhalten. Die 0,1-Ohm-
Darstellung dient allein der klaren Hauptanzeige. Diagramme und weiterführende
Auswertungen verwenden die ungerundeten Messwerte.

## Inhouse-Validierung

Für den validierten Hardware- und Firmwarestand ergab die Inhouse-Vermessung
ein Messrauschen von rund 3 mOhm. Damit besteht für die vorgesehenen
Widerstandsgrenzen ein ausreichender Abstand zu einer Auflösung von 0,1 Ohm.
Die eingesetzte Referenz hat eine Genauigkeit von 0,1 %.

Diese Angaben gelten nur für den dokumentierten Prüfaufbau und den getesteten
Gerätestand. Bei Änderungen an Hardware, Referenz, Messpfad oder Firmware wird
die Validierung wiederholt und ergänzt.

## Transparenter Prüfmodus

Das signierte FIE-Preset hält die verwendeten Grenzwerte, Version, Datum,
Quelle und Regelreferenzen lesbar fest. Bei aktivem Preset ist der FIE-Modus in
der Benutzeroberfläche sichtbar. Dadurch ist nachvollziehbar, mit welchen
Parametern geprüft wurde; daraus folgt keine formale FIE-Zertifizierung des
Testers oder eines einzelnen Prüfergebnisses.

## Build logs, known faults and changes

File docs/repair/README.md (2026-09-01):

# Reparatur und Materialprüfung

Diese Hinweise unterstützen Fechter und Vereine bei der Fehlersuche an Fechtausrüstung. Sie ersetzen keine qualifizierte Prüfung, Herstellerangaben oder geltende Sicherheitsvorgaben.

- [Typische Materialfehler](./material_failures.md) – Hinweise zu Wackelkontakten, Spitzen, Rollen und Kabeln.

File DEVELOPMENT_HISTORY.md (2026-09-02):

# ⏳ Entwicklungsgeschichte & Veröffentlichungsnachweis (Development History)

Dieses Dokument hält die eigenständige, ehrenamtliche Entwicklung des SVA-Fencing-Testers und den jeweiligen Veröffentlichungsstand fest. Öffentliche, zeitgestempelte Veröffentlichungen können bei einer späteren Bewertung als Hinweis auf einen früheren Stand der Technik dienen. Sie ersetzen jedoch keine Patent-, Rechts- oder Neuheitsprüfung und begründen keinen automatischen weltweiten Ausschluss von Schutzrechten Dritter.

---

### 📅 Technische Evolution & Prototypen-Chronologie

#### 1. Die Geburtsstunde: Breadboard-Validierung (August 2024)
* **Status:** Funktionaler Labor-Proof-of-Concept im fliegenden Aufbau.
* **Ergebnis:** Validierung des volldifferentiellen, ratiometrischen Messprinzips im ungeschirmten Zustand. Am Stichtag (**01.08.2024**) wurde die messtechnische Stabilität des mathematischen Verfahrens mit einer Auflösung von 0,01 Ω im niederohmigen Spektrum erfolgreich nachgewiesen (dokumentierter Laborwert: 2,20 Ω). Der Messbereich erstreckte sich in dieser Phase von 0,01 Ω bis 2 MΩ.
* **Prioritätsnachweis:** Einbindung des verifizierten Labor-Chat-Protokolls vom 01.08.2024 inklusive digitaler EXIF-Metadaten im Projekt-Asset-Ordner (`docs/assets/hist_01_breadboard_2024.png`).

#### 2. Revision 2.0: Die Prototypen-Serie & Labor-Debugging
* **Status:** Erste physische Leiterplatten-Fertigung (100x80 mm, 2-Layer).
* **Fertigung:** Bestellung von 15 nackten Platinen. Aufgrund der naturgemäß hohen Fehlerrate erster Platinen-Revisionen wurde aus Gründen der Kosteneffizienz vollständig auf eine Lötpasten-Schablone (Stencil) verzichtet; 10 Systeme wurden rein manuell an der Laborbank bestückt.
* **Iterative Härtung der 10 Prototypen:**
  * *Board 1 (Das Ur-Entwicklungsboard):* Ausgestattet mit dedizierten Pegelwandlern (Level Shifter) für den I²C-Bus und intensivem Hardware-Rework (Fädeldrähte/Zusatzkomponenten).
  * *Board 2:* Radikaler Rückbau zur Schaltungsvereinfachung. Die Level-Shifter-ICs wurden als überflüssig identifiziert, entfernt und durch direkte Drahtbrücken ersetzt. Der Bus-Betrieb erfolgte fortan rein über die Open-Drain-Physik.
  * *Board 3:* Erste Optimierung einer analogen P-Kanal-FET-Spannungsfolgerschaltung. Diese wurde notwendig, da ein genutzter Digital-Potentiometer-IC herstellerseitig undokumentierte (nur indirekt im Fließtext des Datenblatts erwähnte) Schottky-Schutzdioden an den Wiper-Kontakten besaß, die massive Kriechströme verursachten. Mittels manuellem Rework (Cut Traces, Zusatz-FETs und Widerstände) wurde eine Gate-Steuerspannung von -1,7 V bis -5 V zur analogen Pegelstellung des Buzzers realisiert.
  * *Board 4 bis 10:* Finalisierter, stabiler Umbau basierend auf Board 3, der als exakte Kopiervorlage für die restliche Kleinserie diente. Während des Betriebs zeigte sich ein hochgradig temporärer, vom LiPo-Akkuladestand abhängiger Bootloop-Fehler. Transiente Spannungsflanken triggerten die Reset-Leitung der DS3231-RTC, was durch ein physisches Auftrennen der Leiterbahn (Leiterbahntrennung) dauerhaft behoben wurde.

#### 3. Revision 3.0: Routing-Machbarkeit & Formfaktor-Schrumpf
* **Status:** Layout-Bereinigung ohne physische Zwischenfertigung.
* **Ergebnis:** Erfolgreiche Übernahme aller v2-Erkenntnisse (vollständige Entfernung der Level Shifter, I²C-Kopplung direkt über 3,3V-Pull-ups). Schrumpfung des Formfaktors um 25 % auf das kompakte Endmaß von **100x60 mm**, um die mechanische Kompatibilität zu standardisierten Aluminium-Strangpressprofilen zu sichern. Das Routing fokussierte primär die geometrische Machbarkeit im engen Raum, was verkoppelte Masseflächen mit langen Signal-Furchen und isolierten Masse-Inseln hinterließ.

#### 4. Revision 4.0: Serienreife, EMV-Härtung & Low-Cost-Optimierung
* **Status:** Finales Serien-Layout (100x60 mm, ready for Stencil-Sammelbestellung).
* **Layout-Härtung:** Vollständige Bereinigung der v3-Routing-Schwächen. Wiederherstellung absolut durchgehender, ununterbrochener Masseflächen (Ground Planes) auf beiden Lagen zur effektiven Abschirmung von Antenneneffekten und Störeinkopplungen der langen Fechtprüfleitungen im Hallenbetrieb.
* **Akustik-Revolution:** Kompletter Rauswurf der komplexen v2-Poti-Regelschleife. Ersetzung durch eine unhörbare, softwareseitig steuerbare 100-kHz-Dual-PWM-N-FET-Kaskade (Volume-PWM via passiven RC-Tiefpass an N-FET im Linearmodus kaskadiert mit digitalem Tone-N-FET gegen GND) für eine absolut verschleißfreie und knackfreie Lautstärkeregelung ohne mechanische Gehäusedurchbrüche.
* **Eingangsschutz:** Integration von ultra-kapazitätsarmen (Low-C) Fail-Short-ESD-Schutzdioden-Arrays aus dem High-Speed-USB-Design zum Schutz der analogen 16-Bit-Messkanäle (ADS1115/ADG707), ohne die kritische 860-Hz-Abtastung zu dämpfen. Bei massiver Überlastung verschmelzen die Dioden kontrolliert zu einem permanenten Kurzschluss gegen Masse, schützen den Systemkern vor Zerstörung und bleiben dank des handlötoptimierten Designs (Zero BGA/QFN) dezentral austauschbar.

---

### 🔬 Kernmerkmale des geschützten Messprinzips

1. **Ratiometrisches Hochgeschwindigkeits-Verfahren:** Nutzung des internen programmierbaren Signalverstärkers (PGA) des 16-Bit-ADC zur dynamischen, softwareseitigen Bereichsumschaltung unter Verzicht auf kaskadierte Hardware-Referenzwiderstände. Dies sichert eine konstante Fullrange-Abtastung von bis zu **860 Hz** zur Wackelkontakt-Analyse (0,01 Ω Auflösung im Bereich < 10 Ω, Trendanalyse bis 10 MΩ).

2. **Synchronisierte X/Y-Buskopplung & Hardware-Inhibit:** Die 3-Bit-X-Adressierung und die 3-Bit-Y-Adressierung steuern die Schalt-FETs des Prüfstroms und die analogen Multiplexer (ADG707) absolut synchron und parallel an. Diese hardwareseitige Kopplung garantiert, dass die lastfreie Spannungsmessung physisch untrennbar an den jeweils aktiven Prüfstromkanal gebunden ist ("Always In Sync"). Das zusätzliche Inhibit-Signal (AINH) schaltet die Matrix im Umschaltmoment für wenige Mikrosekunden blind, um transiente Umschalt-Glitches vollständig zu eliminieren.

3. **Optimierte ADC-Kanal-Matrix:** Die Auslegung des 16-Bit-Wandlers (ADS1115) teilt die vier analogen Eingänge (AIN0 bis AIN3) für ein mathematisch fehlerfreies, ratiometrisches Messverfahren auf:
   * **AIN2:** Dedizierter Single-Ended-Eingang zur permanenten Überwachung der LiPo-Akkuspannung ($V_{BAT}$).
   * **AIN0, AIN1, AIN3:** Kombinierte Messmatrix für synchrone Single-Ended- und Differenzialmessungen zur simultanen Erfassung von $U_{R\_Ref}$, $U_{Rx}$ sowie der Summenspannung ($U_{R\_Ref} + U_{Rx}$). Durch die differenzielle Verschaltung werden eingekoppelte Gleichtaktstörungen der langen Fechtleitungen physikalisch ausgelöscht.

4. **Ratiometrische FET-Kompensation & Erhöhte Signalreserve:** Die stabilisierte Analogspannung von 4,00 V ($V_{DDA}$) versteht sich inklusive der transienten Verluste der Schaltmatrix. Da die Firmware den Spannungsabfall über der Drain-Source-Strecke ($U_{DS}$) der aktiven Feldeffekttransistoren bei jedem Messzyklus vollautomatisch ratiometrisch bereinigt, wird der Einschaltwiderstand ($R_{DS(on)}$) der Halbleiter mathematisch vollständig eliminiert. Dies ermöglichte bereits in der Prototypenphase den erfolgreichen Einsatz von Standard-TO-92-FETs mit Eigenwiderständen im 100-mΩ-Bereich ohne Präzisionsverlust. Zudem erhöht der inhärente Spannungsabfall an der Schaltstufe die reale Spannungsreserve am Wandler-Eingang bis zur Sättigungsgrenze (4096 mV) im Praxisbetrieb signifikant, was eine absolute Immunität gegen temperaturabhängige Bauteildriften und Signal-Clipping garantiert.

5. **Level-Shifter-freie Buskopplung:** Trotz der erhöhten analogen Schienenspannung von 4,0 V erfolgt die digitale Anbindung an den 3,3V-Mikrocontroller (ESP32-S3) vollständig ohne dedizierte Pegelwandler-ICs. Durch die Auslegung der I²C-Schnittstelle als Open-Drain-Bus und die Platzierung der Bus-Pull-up-Widerstände gegen die digitale +3V3-Versorgung wird der Signalpegel im Ruhezustand physikalisch auf 3,3 V limitiert. Dies schützt die GPIO-Eingänge des Controllers dauerhaft vor Überspannung, während die High-Erkennungsschwelle des ADC (mind. 2,8 V) stabil und rauscharm überschritten wird. Dies reduziert die Stücklistenkosten (BOM) sowie den Ruhestrombedarf des Powermoduls auf ein absolutes Minimum.

6. **Unified-Firmware mit I²C-Autoscan:** Die Firmware führt beim Systemstart einen automatischen Peripheriescan durch. Sie erkennt modular das Fehlen von RTC (Fallstand: keine Uhrzeit), sekundärem ADC (Wechsel von Parallelsampling auf sequenzielles Time-Multiplexing) oder FRAM (Wechsel auf EEPROM/Flash) und sichert die vollständige Abwärtskompatibilität über alle Hardware-Generationen hinweg mit einem einzigen Release-Build.

7. **Automatisierter Zero-Power-Standby & Kapazitativer Auto-Wakeup-Trigger:** Bei Inaktivität schaltet die Firmware alle analogen Verbraucher via LDO-Enable ab und versetzt die MCU in den Deep-Sleep. Die resultierende Lastabsenkung unter die Threshold-Grenze des PMICs triggert eine vollständige, hardwareseitige Abschaltung der 5V-Hauptschiene (echter 0-Watt-Standby bei vergessenem Netzschalter). Das erneute Aufwecken des stromlosen Systems erfolgt knopflos rein über einen transienten Impuls: Ein kurzes Betätigen des 5V-Hauptschalters (< 1s) auf Aus und Ein lädt die boardeigenen MLCC-Stützkondensatoren auf. Dieser kapazitive Einschaltstrom (Inrush Current) wird vom PMIC als Lastereignis detektiert, wodurch die Spannungsversorgung dauerhaft zugeschaltet wird und die MCU fehlerfrei bootet. Die Lade- und 4-LED-Statusinfrastruktur verbleibt dabei vollständig autark und signalisiert Ladezyklen ohne Interaktion der Haupt-MCU oder dedizierte Abfragetasten.

8. Temperaturkompensierte & Fail-Safe LiPo-Batterieüberwachung (AIN2): Die Erfassung der LiPo-Akkurohspannung am dedizierten ADC-Kanal AIN2 verzichtet bewusst auf einen klassischen ohmschen Spannungsteiler. Die Schaltung implementiert stattdessen eine serielle Silizium-Diode gekoppelt mit einem definierten, deterministischen Lastwiderstand. Da der negative Temperaturkoeffizient der Dioden-Flussspannung (ca. -2 mV/K) den elektrochemischen Temperatureffekten des LiPo-Akkus unter Last präzise entgegenwirkt, neutralisieren sich thermische Einflüsse im Praxisbetrieb nahezu vollständig. Zudem bietet diese Topologie eine inhärente Fail-Safe-Sicherheit: Im Falle einer mechanischen Unterbrechung oder eines Haarrisses im unteren Pfad wird das Anliegen der ungepufferten Akkurohspannung am Wandler-Eingang physikalisch verhindert, was den Analog-Digital-Wandler dauerhaft vor transienter Zerstörung schützt.

9. Definierte Gate-Ableitung gegen parasitäres Geister-Einschalten (Anti-Ghost-On): Sämtliche funktionskritischen Feldeffekttransistoren (FETs) der Kreuzmatrix sowie der Batteriemessstrecke verfügen über eine dedizierte Gate-Ableitungsstruktur gegen das gemeinsame Bezugspotenzial (GND). Dies verhindert im Moment des softwareseitigen Standbys das Entstehen hochohmiger, floatender Gate-Zustände. Parasitäre Umladevorgänge und schleichende Kriechstrompfade (Ghost-On-Effekte) werden physikalisch vollständig unterbunden. Dies garantiert, dass die Last unter die Erkennungsschwelle des PMICs sinkt, wodurch die $V_{BAT}$-Überwachung sowie die gesamte Hauptplatine absolut stromlos geschaltet werden und ein echtes, physikalisches Zero-Power-Standby ohne Restentladung des LiPo-Akkus erzielt wird.

10. Physikalische Peripherie-Trennung via LDO-Enable-Steuerung: Zur absoluten Eliminierung transienter Kriechströme im Standby wird die analoge +4V-Messspannung über den Enable-Pin (EN) des LDO-Reglers softwaregesteuert vollständig abgeschaltet. Im Deep-Sleep-Zustand des Mikrocontrollers wird die gesamte analoge Peripherie (FET-Matrix, Multiplexer, ADCs) physikalisch komplett spannungslos geschaltet. Dies garantiert im Zusammenspiel mit den Gate-Ableitungen ein absolut fehlerfreies Sinken der Systemlast unter die Abschaltschwelle des PMICs und sichert das echte Zero-Power-Standby deterministisch ab.

11. Thermische Kopplung & Akku-Masse-Anker zur Messstabilisierung: Das mechanische Sandwich-Design nutzt den flach auf der zweiseitigen PCB aufliegenden 1800-mAh-LiPo-Akku als hochgradig effektive thermische Kapazität. Diese massive thermische Masse dämpft transiente Temperaturschwankungen der Umgebung oder digitaler Schaltzyklen (z. B. WLAN-Bursts) auf der Platine nahezu vollständig. Die resultierende thermische Homogenität des Analogzweigs minimiert das Halbleiter-Rauschen der ADG-Multiplexer und des ADS1115 drastisch und sichert die hohe zeitliche Konstanz des R₀-Feinschmiedens im 0,1-Ohm-Fenster.

12. Thermisch optimierte Lade-Infrastruktur & Dreistufige LiPo-Sicherheitskaskade: Der maximale Ladestrom ist hardwareseitig streng auf 400 mA limitiert. Bezogen auf die Akkukapazität von 1800 mAh entspricht dies einer materialschonenden Laderate von ~0,22 C, wodurch jegliche thermische Verlustleistung im Ladebetrieb eliminiert und eine thermische Degradation des darüberliegenden TFT-Displays ausgeschlossen wird. Bei drohender Tiefentladung greift eine dreistufige Schutzarchitektur: Nach der softwareseitigen 4V-LDO-Abschaltung und dem automatischen Kappen des 5V-Return-Pfads durch den PMIC (0-Watt-Standby) verbleibt die RX8900SA-RTC im direkten $V_{BAT}$-Dauerbetrieb. Da deren Stromaufnahme im Nanoampere-Bereich unterhalb der natürlichen LiPo-Selbstentladungsrate liegt, bleibt die Zeitbasis über Monate autark erhalten, bevor im finalen systemkritischen Moment die zellinterne Hardware-Schutzschaltung des Akkus die Zelle isoliert abtrennt.

13. Modulare Zwei-Platinen-Energiearchitektur & EMV-Entkopplung: Die Powerbank- und Buck-Boost-Konverterstufe ist physisch auf einer separaten Mini-Platine ausgelagert und vollständig vom analogen Hauptmessboard (100x60 mm) entkoppelt. Diese modulare Trennung isoliert das hochfrequente Schaltrauschen (Ripple) des Reglers effektiv vom sensiblen 16-Bit-Analogzweig, was eine maximale EMV-Signalintegrität und Rauschfreiheit der Messstufen garantiert. Gleichzeitig sichert diese Topologie eine herstellerunabhängige Zukunftsfähigkeit: Bei einem Technologiewechsel des Energiespeichers (z. B. auf alternative Zellchemien oder Rundzellen) kann das Powermodul ohne Modifikation oder Re-Design der komplexen Hauptplatine autark ausgetauscht werden.

---

### 🛡️ Mechanisches Sicherheitskonzept & Design-for-Repair (Rev 4.0)

Die physische Konstruktion folgt dem Prinzip der maximalen Betriebs- und Wartungssicherheit unter Gesamtkostenminimierung:
* **Mechanische Entkopplung:** Sämtliche externen Prüfbuchsen sind über flexible Kabel-Steckverbinder ($J6$, $J8$) mechanisch vollständig von der Leiterplatte entkoppelt, um mechanische Scher- und Zugkräfte der Fechtkabel von den SMD-Lötstellen fernzuhalten.
* **Planar-Sandwich-Bauweise:** Alle SMD-Komponenten sind konsequent auf der Unterseite (Bottom) platziert. Die vollkommen plane Oberseite (Top) dient als geschützte Aufnahme für den flach aufliegenden LiPo-Akku, der durch das darüber gesteckte und über Abstandshülsen starr verschraubte TFT-Display mechanisch fixiert wird.
* **Erweiterte Lebensdauer (Zero-Elko/Tantal):** Zur Eliminierung typischer Alterungsschwachstellen verzichtet das Schaltungsdesign vollständig auf flüssigkeitsbasierte Elektrolytkondensatoren (Elkos) sowie Tantal-Komponenten und setzt ausnahmslos auf langlebige MLCC-Keramikkondensatoren.
* **Manuelle Fertigbarkeit (Hand-Soldering-Optimized):** Es werden bewusst keine BGA- oder QFN-Gehäuseformen verwendet. Alle SMD-ICs sind im Handlötverfahren (SOIC/TSSOP) kontaktierbar, was eine hocheffiziente, dezentrale On-Demand-Eigenfertigung in Kleinserien ermöglicht.
* **Optimierter Einseitig-Reflow-Prozess (Industrial Design for Manufacturing):**
  Das Layout ist strikt nach Fertigungszonen getrennt: Sämtliche SMD-Komponenten befinden sich exakt auf der Unterseite (Bottom), während alle THT-Steckverbinder und akustischen Signalgeber auf der Oberseite (Top) platziert sind. Diese strikte Kanaltrennung ermöglicht bei größeren Chargen einen hocheffizienten, einseitigen Reflow-Lötprozess (Single Reflow) in einem einzigen Maschinendurchlauf, gefolgt von einer einfachen THT-Wellen- oder Selektivlötung. Dies senkt die industriellen Rüst- und Fertigungskosten drastisch und sichert eine fehlerfreie, reproduzierbare Serienqualität.
* **HF-optimiertes Nutzen-Design & Geometrische Flächeneffizienz:**
  Das Platinen-Layout verfügt am oberen Rand über gezielte geometrische Abschrägungen, die eine hocheffiziente Anordnung von zwei Platinen innerhalb eines gemeinsamen Fertigungsnutzens (Panel) ermöglichen. Diese Abschrägungen lösen das kritische Hochfrequenz-Dilemma (RF-Performance) des ESP32-S3-Moduls: Sie schaffen im Nutzenverbund den notwendigen physischen Freiraum um die integrierte PCB-Antenne herum. Dadurch werden Impedanzverstimmungen durch nahegelegene Kupferflächen oder Nutzenstege zuverlässig verhindert, was die maximale WLAN-Reichweite für kabellose OTA-Updates sichert. Gleichzeitig ermöglicht das clevere Panel-Design ein simultanes Bestreichen und Reflow-Löten von zwei Systemen auf der Hotplate, was den dezentralen Fertigungsaufwand in der Werkstatt halbiert.
* **Eurokarten-Standardisierung & Modulare Gehäuse-Kompatibilität:**
  Die Platinenbreite ist starr auf 100 mm fixiert, was eine native Abwärtskompatibilität zu industriellen Standard-Aluminium-Strangpressgehäusen im Eurokarten-Format (160x100 mm) garantiert. Die Leiterplatte gleitet dadurch ohne zusätzliche mechanische Halterungen oder Sonderbauten direkt in die integrierten Gehäuse-Führungsnuten. Während die erste Prototypenserie (Rev 2.0) mit den Maßen 100x80 mm exakt die Hälfte einer Standard-Eurokarte belegte, reduzierte das finale Serienlayout (Rev 4.0) die Baulänge durch extreme Integration auf ultrakompakte 100x60 mm, wodurch der Materialeinsatz für das Profilgehäuse pro System minimiert und die maximale mechanische Stabilität im Hallenbetrieb gewahrt bleibt.
* **Kollisionsfreier Bauraum & Buchsen-Integration:**
  Die Reduzierung der Platinenlänge auf 60 mm eliminiert jeglichen Platinenüberhang im vorderen Gehäusebereich unter dem Display. Dadurch wird ein großzügiger, mechanisch freier Bauraum geschaffen, der eine vollkommen kollisionsfreie Integration der tief ins Gehäuseinneren ragenden 4-mm-Prüfbuchsen in der Frontplatte ermöglicht. Gefährliche Kurzschlüsse zwischen den Lötpfosten der Buchsen und den SMD-Komponenten der Leiterplatte werden im Keim erstickt, was die werkstattseitige Gehäusemontage massiv vereinfacht.
* **Maximale Flexibilität für Custom-Gehäusedesigns:**
  Durch die vollständige mechanische Entkopplung von Frontplatten-Buchsen und Platinen-Sandwich wird die Konstruktion individueller Gehäuselösungen drastisch vereinfacht. Dies ermöglicht es den Vereinen, neben industriellen Standard-Aluminiumprofilen auch kostengünstige, maßgeschneiderte Gehäusedesigns im 3D-Druck oder Lasercut-Verfahren dezentral zu fertigen, ohne dass komplexe Toleranzketten oder Kollisionsrisiken berücksichtigt werden müssen.
* **Funktionale Integration & Bauteil-Reduktion (Design Reduction Principle):**
  Die technologische Reife der Revision 4.0 manifestiert sich im Prinzip der bauteilreduzierenden Feature-Maximierung. Durch das bewusste Ausnutzen intrinsischer Bauteileigenschaften und fortgeschrittener Software-Logik resultiert ein erweiterter Funktionsumfang in einer signifikant reduzierten Bauteilanzahl (BOM). Die Eliminierung dedizierter Level-Shifter-ICs durch Open-Drain-Buskopplung, der Ersatz komplexer analoger P-FET-Regelschleifen durch eine duale N-FET-PWM-Kaskade sowie die softwareseitige Hardware-Abstraktion (I²C-Autoscan) demonstrieren, wie messtechnische Präzision, Ausfallsicherheit und erweiterte Systemfeatures durch konsequente Schaltungsvereinfachung erzielt werden.

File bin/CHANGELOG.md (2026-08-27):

# 📜 SVA-Fencing-Tester – Version History & Changelog

This file documents the release history, firmware builds, and corresponding webapp/LittleFS updates for the SVA-Fencing-Tester initiative.

---

## 🛠️ Current Development Phase (Under Construction)

### [0.7.0+71] - 2026-08-17
* **Firmware (ESP32):**
  * empty test file
* **Webapp & LittleFS:**
  * empty test file
* **Testing:**
  * test repo connection

---

## 📋 Release Format & Versioning Rules

We use a specific versioning structure tailored to our automated pre- and post-build system:
`SVA-Fencing-Tester.[BRANCH]_[MAJOR].[MINOR].[PATCH]+[BUILD]_[YYYY-MM-DD]_[HH]_[MM].ota`

* **Format Type:** Combined All-in-One Bundle (contains both the compiled firmware partition and the LittleFS image).
* **Delivery:** Clients connect to the offline device Access Point, fetch the `version.json` from this repository via their active internet connection, and download the `.ota` package to flash the device locally.

---

## 🛡️ Failsafe & Recovery Matrix

If an update fails or the file system gets corrupted, refer to the following version states:

| Firmware Version | Required Webapp | LittleFS Layout | Minimum Recovery Version |
| :--- | :--- | :--- | :--- |
| **0.7.0+71** | webapp.gz (v0.7) | Layout V1 (Lite Manual) | v0.5.0 (Recovery Server Base) |

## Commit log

2026-09-01 docs: add revision 2 PCB renderings
2026-09-01 docs: add revision 4 PCB rendering and STEP reference
    [sva-fencing-tester-pcb-reference.step]
2026-09-01 docs: add KiCad PCB STEP models
    [sva-fencing-tester-pcb-reference.step]
2026-09-01 docs: mark compliance material as draft
2026-09-01 docs: add revision 4 display PCB rendering
2026-09-01 docs: show revision 2 display PCB rendering
2026-09-25 Clarify evaluation kit battery assembly
2026-09-25 Explain separate battery cost benefit
2026-09-25 Clarify R0 connector compensation
2026-09-25 Explain physical connector resistance
2026-09-25 Record initial connector variation
2026-09-25 Document R0 calibration evidence
2026-09-25 Record test bridge resistance
2026-09-25 Document FIE material tester scope
2026-10-14 Add vest probe adapter board documentation
2026-10-14 Align adapter documentation with PCB pages
2026-10-14 Document vest probe adapter in PCB index
2026-10-14 Add vest probe adapter STEP model
2026-10-14 Link vest probe adapter model in hardware overview
2026-10-14 Refresh Rev4 and vest probe adapter renders
2026-10-14 Document ESP32-S31 for Revision 5
2026-10-20 Update vest probe adapter top render
2026-10-20 Update vest probe adapter STEP model

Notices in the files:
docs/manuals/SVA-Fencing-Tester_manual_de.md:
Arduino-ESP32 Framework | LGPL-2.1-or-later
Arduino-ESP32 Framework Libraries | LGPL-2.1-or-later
